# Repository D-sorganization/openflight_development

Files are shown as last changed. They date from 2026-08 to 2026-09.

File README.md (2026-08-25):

<p align="center">

  DIY Golf Launch Monitor using the OPS243-A Doppler Radar.
</p>

<p align="center">
  <a href="https://discord.gg/w8hhG4WVMN">
    
  </a>
  <a href="https://buymeacoffee.com/colemangolfs">
    
  </a>
</p>

> [!WARNING]
> **This project is in active development.** Features may be incomplete, unstable, or change without notice. Contributions and bug reports are welcome!

## Overview

OpenFlight is an open-source golf launch monitor built around the OPS243-A
Doppler radar, with an optional TI IWR6843 angle radar.

### What It Measures

- **Ball Speed**: 15-200 mph range with ±0.5% accuracy (OPS243-A)
- **Club Speed**: Detected from pre-impact readings (OPS243-A)
- **Smash Factor**: Ball speed / club speed ratio
- **Launch Angle**: Measured by the IWR6843; estimated when no trusted radar angle is available
- **Club Path**: Experimental pre-impact estimate from the IWR6843
- **Spin Rate**: Experimental candidate from rolling-buffer I/Q; not used for carry by default
- **Carry Distance**: Ballistic model with explicit fallbacks for missing measurements

### Hardware at a Glance

| Component | What it does | ~Cost |
|---|---|---|
| OPS243-A Radar | Ball speed, club speed, experimental spin | $249 |
| Raspberry Pi 5 | Runs everything | $130 |
| 7" Touchscreen | Shows shot data | $46 |
| SparkFun SEN-14262 | Impact sound trigger for shot capture | $18 |
| Power supply + accessories | | $27 |
| **Subtotal, no angle radar** | | **~$400** |
| TI IWR6843LEVM + cable | Launch angle, experimental club path | $156 |
| **Total with angle radar** | | **~$556** |
| K-LD7 (×2) + FTDI adapters | Launch angle + club path (**deprecated**) | $140 |

Without an angle radar you still get ball speed, club speed, smash factor,
experimental spin, and estimated carry. The angle radar adds measured launch
angle and experimental club path.

> **⚠️ The K-LD7 angle radars are deprecated.** The supported angle radar is now the **TI IWR6843**. Don't buy K-LD7s for a new build; their software support remains for existing builds only. See the [full parts list](docs/PARTS.md) for details and links.

> **The IWR6843 needs custom firmware** — the stock TI demo doesn't expose the raw radar cube OpenFlight needs. A validated prebuilt image ships in `firmware/releases/`, so flashing it doesn't require the TI toolchain. See the [IWR6843 Operator Guide](docs/iwr6843/README.md).

## Getting Started

### 1. Get the parts

See the **[Parts List](docs/PARTS.md)** for everything you need with purchase links.

### 2. Wire it up

Follow the **[Sound Trigger Wiring Guide](docs/sound-trigger-wiring.md)** to connect the SEN-14262 to the OPS243-A. The (deprecated) K-LD7 modules connect via USB — no wiring needed.

**Adding the IWR6843 angle radar?** The Pi cannot power both radars over USB, so
the OPS243 moves to the Pi's GPIO UART header while the TI board takes the USB
port. Do it in this order, validating each step before the next — doing both at
once makes any failure ambiguous:

1. **[Move the OPS243 from USB to the Pi GPIO UART](docs/ops243-uart-migration.md)** — rewire and confirm the OPS still triggers on its own.
2. **[IWR6843 Operator Guide](docs/iwr6843/README.md)** — wire, flash the firmware, mount, aim, and measure geometry.

If your OPS243-A has **WiFi**, you cannot use the GPIO UART — its WiFi module
already drives the radar's UART receive line. Use a separately powered USB hub
instead; see the operator guide's Option B.

### 3. Set up the Pi

Flash Raspberry Pi OS (64-bit), plug in the radars, then run the interactive setup:

```bash
git clone https://github.com/jewbetcha/openflight.git
cd openflight
./scripts/setup/setup.sh
```

The script installs everything and walks you through the one-time hardware
configuration (radar flash setup, legacy K-LD7 device naming, auto-start, and
optional cloud sync) with prompts. It's safe to re-run any time.
See the **[Raspberry Pi Setup Guide](docs/raspberry-pi-setup.md)** for
details and troubleshooting.

### 4. Hit balls

```bash
# Default: rolling buffer mode with sound trigger
scripts/start-kiosk.sh

# With the IWR6843 angle radar (OPS243 on the Pi GPIO UART).
# Geometry values are examples — measure your own; see the operator guide.
scripts/start-kiosk.sh --iwr6843 \
  --ops-port /dev/ttyAMA0 \
  --iwr6843-tee-m 1.372 --iwr6843-net-m 4.064 \
  --iwr6843-tilt-deg 5.5 --iwr6843-radar-height-m 0.229 \
  --iwr6843-ball-height-m 0.021

# With legacy K-LD7 hardware (measure the mount tilt first)
scripts/start-kiosk.sh --kld7 --kld7-mount-tilt <measured-degrees>

# Swing speed training (air swings / speed sticks, no sound trigger)
scripts/start-kiosk.sh --swing-speed

# Development mode (no hardware)
scripts/start-kiosk.sh --mock

# With Geekworm X1202/X1206 battery monitoring
scripts/start-kiosk.sh --battery geekworm
```

The IWR6843 example values are not universal. Measure the geometry from the
antenna center and follow the [operator guide](docs/iwr6843/README.md#measure-the-geometry);
wrong values bias the result instead of producing an obvious startup error.

Then open http://localhost:8080 or use the touchscreen.

### 5. Sync to the cloud (optional)

OpenFlight can push your sessions to the **FlightWeb** cloud so you can review
shots from any device. It's opt-in, and **raw radar data never leaves your
Pi** — only shot results and session metadata are uploaded (verify with
`openflight-cloud push --dry-run`).

`setup.sh` offers to enable this and link your Pi. To do it by hand:

```bash
openflight-cloud link       # pair this Pi (enter a short code in your browser)
openflight-cloud status     # linked? queued? parked?
```

Once linked, sessions sync automatically (on session end and via a ~10-minute
timer that heals wifi outages). See the **[Cloud Sync Guide](docs/cloud-sync.md)**
for details.

### TV Display Mode

OpenFlight also serves a fullscreen-friendly browser display for tablets, TV browsers, or a Chrome tab cast to Chromecast.

1. Start OpenFlight as usual with `scripts/start-kiosk.sh`.
2. Find the OpenFlight host on your LAN — its hostname (see below) or its IP address.
3. Open `http://<openflight-host>:8080/display` from another laptop, tablet, or TV browser.
4. For Chromecast, open the display page in Chrome and use Chrome's built-in **Cast** feature to cast the tab.

> **Prefer the hostname over the IP.** Raspberry Pi OS broadcasts its hostname over
> mDNS (Avahi), so `http://openflight.local:8080/display` keeps working even when the
> Pi's DHCP lease expires and it comes back on a different address — a bookmarked IP
> breaks unless you reserved it on your router. Set the name in Raspberry Pi Imager's
> **Hostname** field when you flash the card; the default is `raspberrypi`, i.e.
> `raspberrypi.local`. The viewing device has to support mDNS — macOS, iOS, Windows 10+
> and most Linux desktops do, but some smart-TV browsers don't, so use the IP there.

This is browser/tab casting only. OpenFlight does not include native Cast SDK support yet.

### Swing Speed Training

For air swings and speed-stick training, OpenFlight can use the OPS243-A fast
speed stream directly instead of waiting for impact audio. Start it with
`scripts/start-kiosk.sh --swing-speed`; the server emits `swing_speed` events
with peak club speed, rep duration, reading count, and session stats. See the
**[Swing Speed Training Guide](docs/swing-speed-training.md)** for setup and
tuning options.

## How It Works

### System Architecture

```
SEN-14262 ── trigger ──► OPS243-A ── I/Q ──► RollingBufferMonitor
                                                   │
IWR6843 (optional) ── angle + club path ───────────┤
                                                   ▼
                                           Flask + WebSocket ──► React UI
```

1. **Sound trigger fires** — SEN-14262 detects club impact, triggers OPS243-A HOST_INT
2. **OPS243-A dumps buffer** — I/Q data is analyzed for ball speed, club speed, and an experimental spin candidate
3. **IWR6843 correlates** — The optional angle radar uses the same impact edge for launch angle and experimental club path
4. **Carry computed** — The ballistic model uses trusted measurements and fills missing inputs with documented fallbacks
5. **UI updates** — Shot data emitted via WebSocket to the React frontend

### Doppler Radar Basics

The OPS243-A transmits a 24 GHz signal. When it bounces off a moving object (the golf ball), the frequency shifts proportionally to the object's speed — this is the Doppler effect. At 24.125 GHz, each 1 mph of speed creates a ~71.7 Hz Doppler shift.

### Positioning

Place the OPS243-A **3-5 feet behind the tee**, pointing down the target line:

```
                Ball Flight Direction
                ======================>

[Tee]  ←--- 3-5 ft ---→  [OPS243-A]
```

The IWR6843 has stricter mounting and measurement requirements; use the
[operator guide](docs/iwr6843/README.md#mount-and-aim-the-radar) rather than assuming it
shares the OPS243 position.

## Configuration

### Radar Settings for Golf

| Setting | Value | Why |
| --- | --- | --- |
| Mode | Rolling buffer | Raw I/Q capture for precise speeds and experimental spin |
| Sample Rate | 30 ksps | Supports up to ~208 mph ball speed |
| Capture | 4096 I/Q samples | ~136 ms around impact |
| Trigger | Sound (SEN-14262) | ~10 µs hardware latency via HOST_INT |
| Min Ball Speed | 15 mph | Filter club waggle and slow movements (35 mph for non-default SpeedTriggeredCapture) |
| DC Mask | ~15 mph exclusion zone | Reject body movement and environmental noise |

These are applied automatically — the one-time flash configuration is handled
by the setup script.

### Python API

```python
from openflight.rolling_buffer import RollingBufferMonitor

monitor = RollingBufferMonitor()  # auto-detects the OPS243-A
monitor.connect()
monitor.start()

print("Swing when ready...")
shot = monitor.wait_for_shot(timeout=60)
if shot:
    print(f"Ball Speed: {shot.ball_speed_mph:.1f} mph")
    print(f"Est. Carry: {shot.estimated_carry_yards:.0f} yards")

monitor.stop()
monitor.disconnect()
```

## Limitations

- **Cosine error**: If ball doesn't travel directly toward/away from radar, measured speed will be slightly lower than actual
- **Spin detection**: The live multitaper value is experimental and is not used for carry by default. Short indoor flight windows and multipath make individual readings unreliable; see [Rolling Buffer and Spin Detection](docs/rolling_buffer_spin_detection.md).
- **K-LD7 speed aliasing** (deprecated hardware): The K-LD7 max speed is 62 mph, so it's used only for angle/distance, not speed

## Hardware Diagnostic

To verify the OPS243, sound trigger, and legacy K-LD7 path:

```bash
uv run python scripts/hardware-test/diagnose.py
```

The diagnostic checks the OPS243 transport, rolling-buffer persistence,
software and hardware triggers, and any connected K-LD7 radars. IWR6843 builds
use the [operator guide's first-capture checks](docs/iwr6843/README.md#verify-the-first-capture).

Missing optional hardware (like the horizontal K-LD7) is reported as a skip rather than a failure. Pass `--require-all` to fail on skips, or `--no-interactive` to skip the sound-trigger prompt in unattended runs.

## Project Structure

```
openflight/
├── src/openflight/
│   ├── ops243.py              # OPS243-A radar driver
│   ├── launch_monitor.py      # Shot detection & club/ball separation
│   ├── ballistics.py          # Ballistic trajectory & carry model
│   ├── server.py              # Flask server and shot orchestration
│   ├── session_logger.py      # JSONL session logging
│   ├── rolling_buffer/        # OPS capture and signal processing
│   ├── iwr6843/               # Current angle radar
│   ├── kld7/                  # Legacy angle radar
│   ├── sim/                   # Simulator connector framework
│   └── cloud/                 # FlightWeb uploader
├── ui/                        # React frontend
├── scripts/                   # Utility & setup scripts
├── docs/                      # Documentation
└── pyproject.toml
```

## Community

Join the **[OpenFlight Discord](https://discord.gg/w8hhG4WVMN)** to ask build
questions, share results, and follow development.

## Contributing

Contributions welcome! See [CONTRIBUTING.md](CONTRIBUTING.md) for guidelines.

Areas of interest:

- **Better spin detection**: A dechirped Doppler-sideband estimator is in development (`scripts/analysis/replay_spin_dechirp.py`) — help validating it against launch-monitor truth data is especially welcome
- **Mobile app**: Bluetooth connection to phone

### Running Tests

```bash
uv run pytest tests/ -v
```

## Documentation

- **[Parts List](docs/PARTS.md)** — What to buy
- **[Sound Trigger Wiring](docs/sound-trigger-wiring.md)** — How to wire the sound trigger
- **[Raspberry Pi Setup](docs/raspberry-pi-setup.md)** — Full setup guide
- **[Battery Monitoring](docs/battery/README.md)** — Provider architecture, UI states, and shared Pi support
- **[Geekworm X1202/X1206 Operator Guide](docs/battery/geekworm.md)** — Batteries, Pi setup, native telemetry, and warnings
- **[IWR6843 Operator Guide](docs/iwr6843/README.md)** — Wire, flash, mount, aim, and calibrate the angle radar
- **[LIS3DH Inclinometer Setup](docs/inclinometer/README.md)**: Add enclosure-level compensation to IWR6843 tilt
- **[OPS243 USB → GPIO UART Migration](docs/ops243-uart-migration.md)** — Required before adding the IWR6843
- **[IWR6843 Firmware Developer Guide](firmware/README.md)** — Build the firmware from source (not needed to flash the prebuilt image)
- **[Simulator Connectors](docs/simulator/README.md)** — Stream shots to GSPro, OpenGolfSim, and others
- **[Cloud Sync](docs/cloud-sync.md)** — Push filtered sessions to FlightWeb
- **[Rolling Buffer & Spin Detection](docs/rolling_buffer_spin_detection.md)** — Production capture and experimental spin details
- **[Dechirped-Sideband Spin Replay](docs/spin-dechirp-replay.md)** — Next-gen spin estimator test bench
- **[Camera and YOLO Experiments](docs/yolo-performance-tuning.md)** — Optional, non-production vision work
- **[Legacy K-LD7 Setup](docs/kld7.md)** — Existing K-LD7 builds only
- **[K-LD7 Ball Detection Theory](docs/kld7-ball-detection-theory.md)** — How angle detection works (deprecated hardware)
- **[K-LD7 Session Review](docs/kld7-session-review.md)** — Offline review workflow for session JSONL files (deprecated hardware)
- **[Observability & Log Shipping](docs/observability.md)** — Ship logs to Grafana Cloud
- **[Contributing Guide](CONTRIBUTING.md)** — How to contribute
- **[Changelog](docs/CHANGELOG.md)** — Version history

## License

GNU Affero General Public License v3.0 or later (AGPL-3.0-or-later) - see LICENSE file.

## Acknowledgments

- [OmniPreSense](https://omnipresense.com/) for the OPS243-A radar and documentation
- The golf hacker community for inspiration

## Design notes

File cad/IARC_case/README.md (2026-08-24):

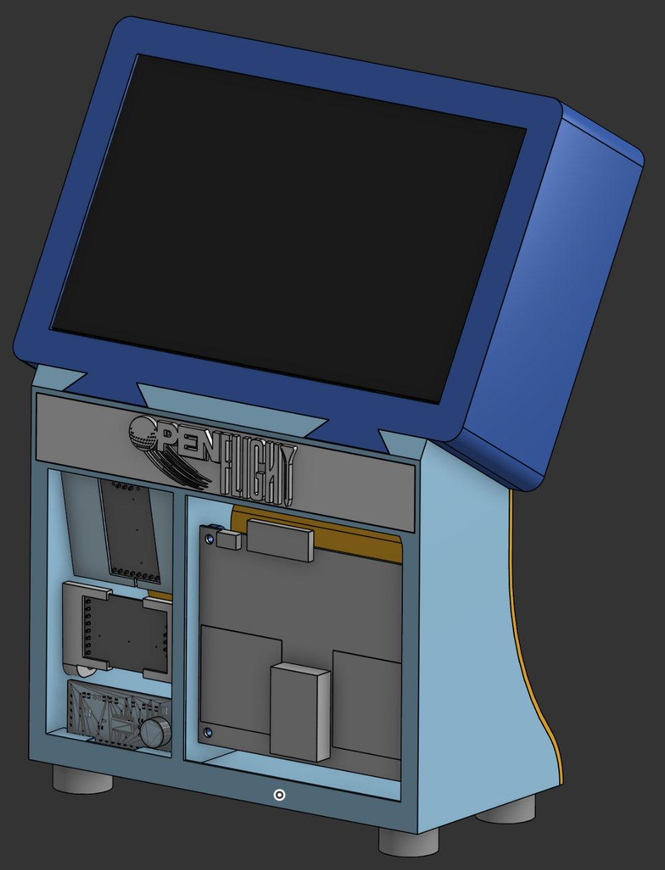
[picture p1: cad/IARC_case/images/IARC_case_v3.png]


> **⚠️ Note:** The KLD7 mounts in this case are for the deprecated K-LD7 angle radars — OpenFlight has moved to a more capable radar chip. Skip the KLD7 mount steps for a new build.

- M5 Bolts needed: 10
- M2.5 Bolts needed: 12

Instructions for OpenFlight IARC v3 Case Build
  
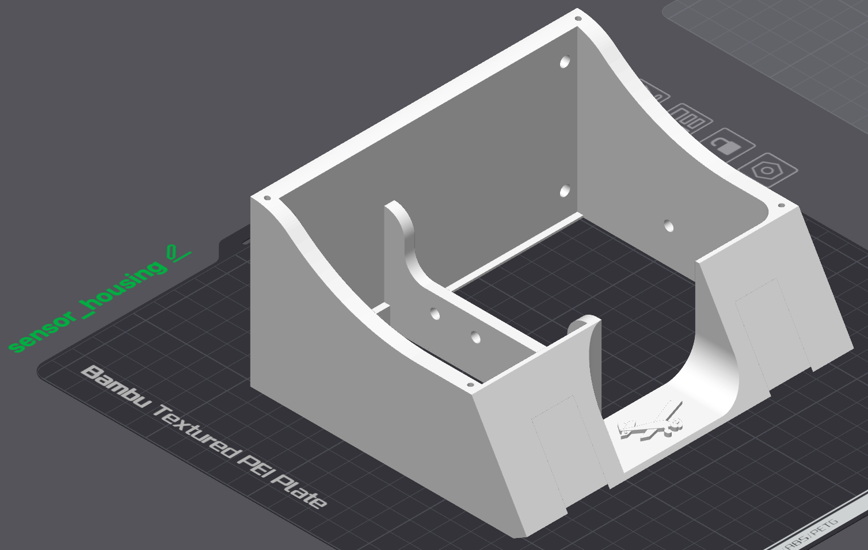
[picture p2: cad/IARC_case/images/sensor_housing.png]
1. Print out `sensor_housing.stl` 
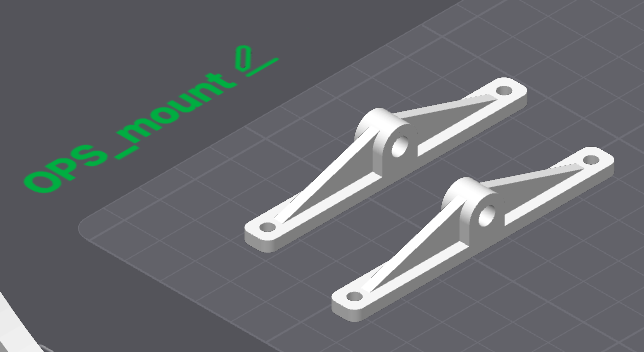
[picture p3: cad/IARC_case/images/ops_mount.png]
2. Print out (2x) `OPS_mount.stl` 
3. Secure the OPS sensor to each `OPS_mount.stl` part with screws (I don't know which ones)
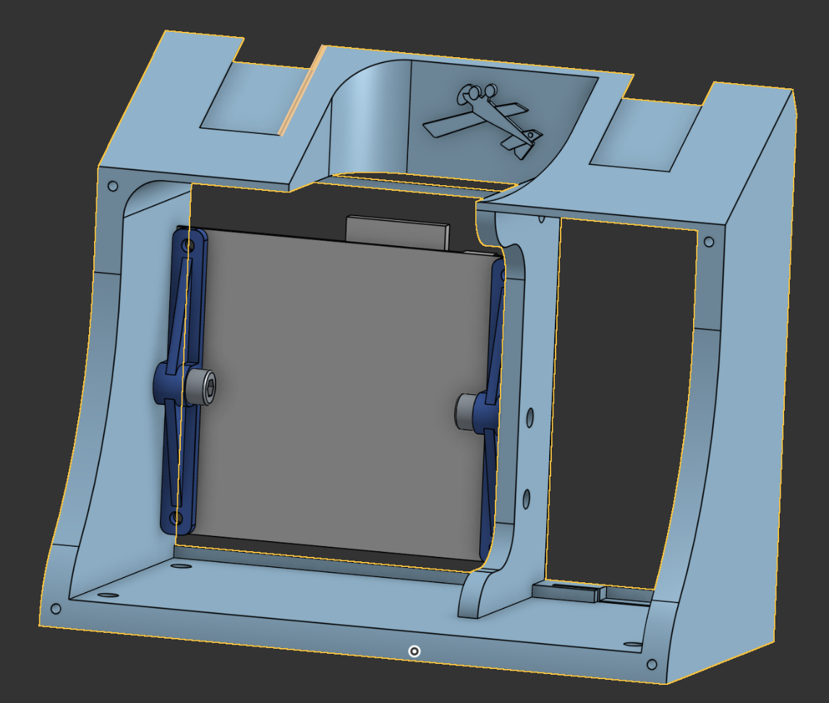
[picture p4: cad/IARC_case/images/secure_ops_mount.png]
4. Secure the `OPS_mount.stl` parts to the `sensor_housing.stl` part with (2x) M5 bolt 
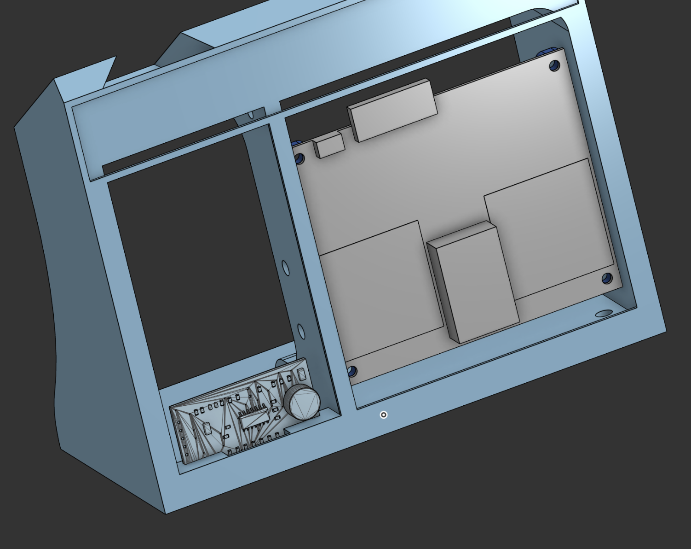
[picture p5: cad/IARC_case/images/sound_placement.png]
5. Fit the sound sensor into the little slot on the left side of the `sensor_housing.stl` part. 
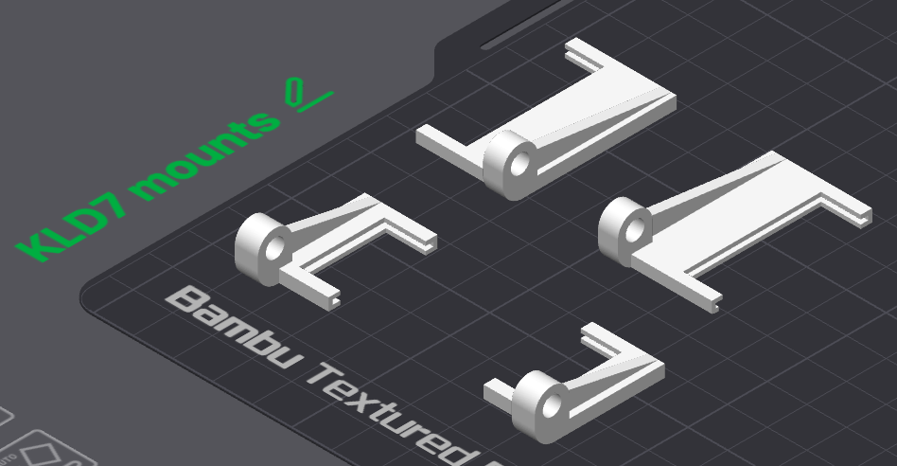
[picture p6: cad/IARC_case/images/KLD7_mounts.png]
6. Print out (1x) `KLD7_h_mount_L_v2.stl` and (1x) `KLD7_h_mount_R_v2.stl` 
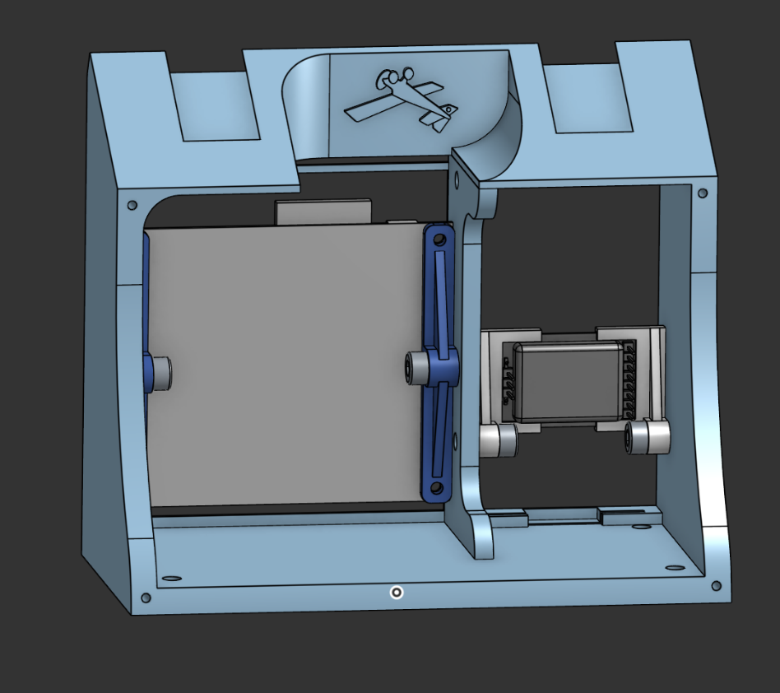
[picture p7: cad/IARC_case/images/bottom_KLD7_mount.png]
7. Slot a KLD7 sensor between the mount parts, and secure them to the `sensor_housing.stl` part with (2x) M5 bolt 
8. Print out (1x) `KLD7_v_mount_L_v2.stl` and (1x) `KLD7_v_mount_R_v2.stl` 
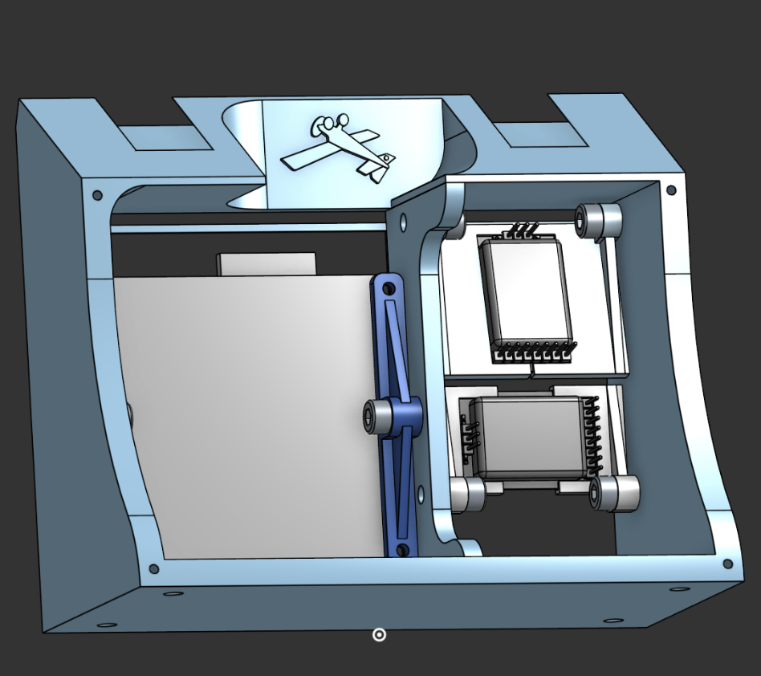
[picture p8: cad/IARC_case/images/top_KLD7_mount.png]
6. Slot a KLD7 sensor between the mount parts, and secure them to the `sensor_housing.stl` part with (2x) M5 bolt 
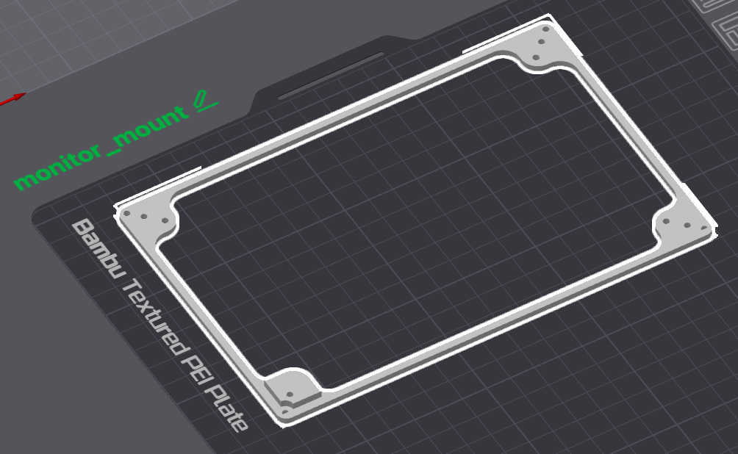
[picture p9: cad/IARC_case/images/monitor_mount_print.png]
7. Print out the `monitor_mount.stl` part. 
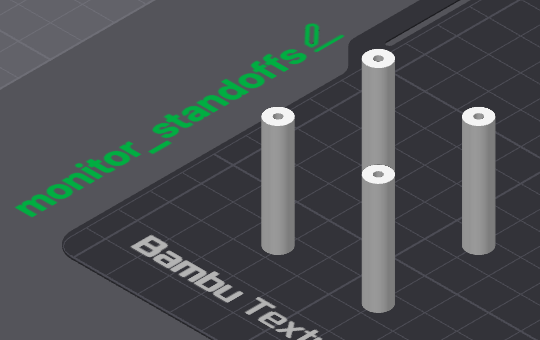
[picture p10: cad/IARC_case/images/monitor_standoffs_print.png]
8. Print out (4x) `monitor_standoffs.stl`'s. 
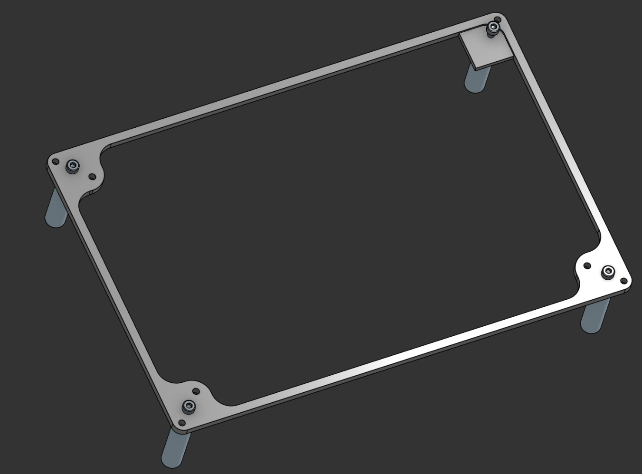
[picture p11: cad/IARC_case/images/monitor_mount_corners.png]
9. Secure each `monitor_standoff.stl` part to the corners of the `monitor_mount.stl` part with (1x) M2.5 bolt. 
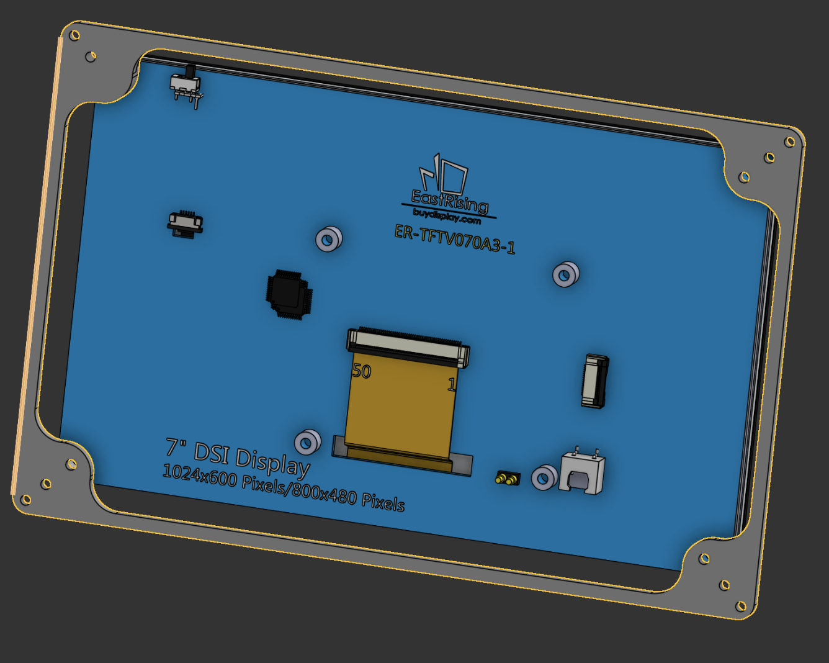
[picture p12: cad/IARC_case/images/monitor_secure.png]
10. Secure the monitor to the `monitor_mount.stl` part. 
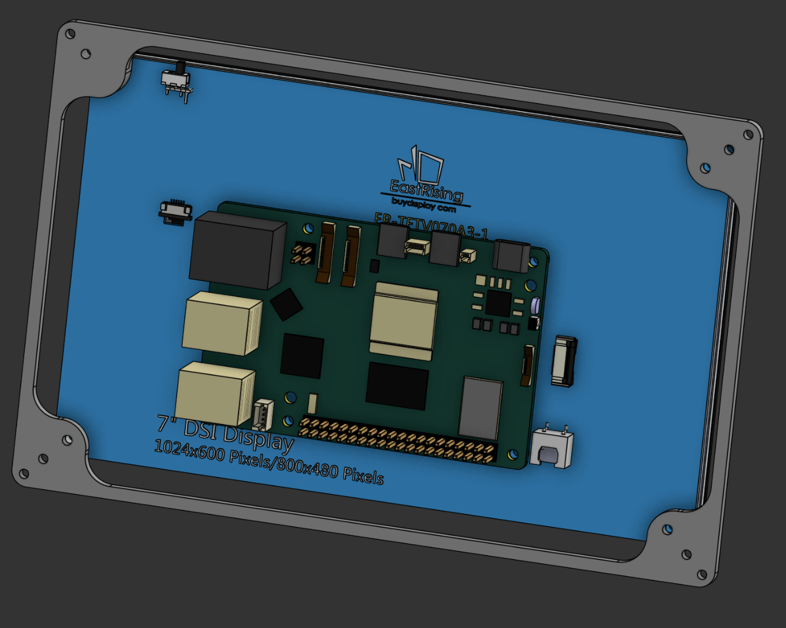
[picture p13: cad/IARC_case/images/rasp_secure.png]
11. Secure the raspberry Pi to the monitor. 
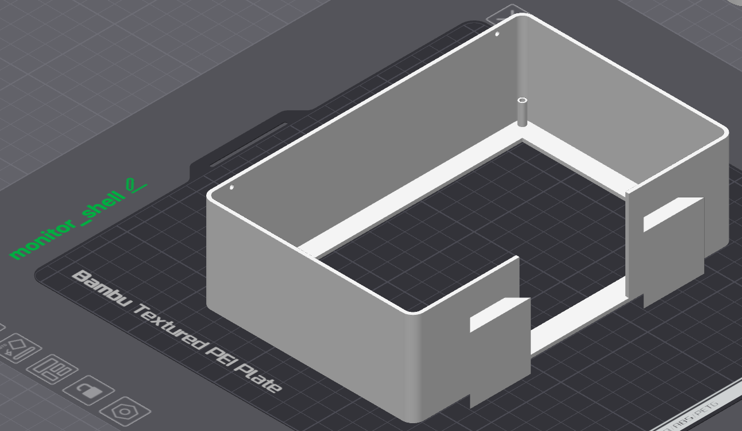
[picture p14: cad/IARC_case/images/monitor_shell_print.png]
12. Print out the `monitor_shell.stl` part. If you use the Raspberry Pi Touch Display 2 instead of the 7" HMTECH touchscreen, print `Touch_Display2_shell.stl` and `Touch_Display2_backplate.stl` instead. 
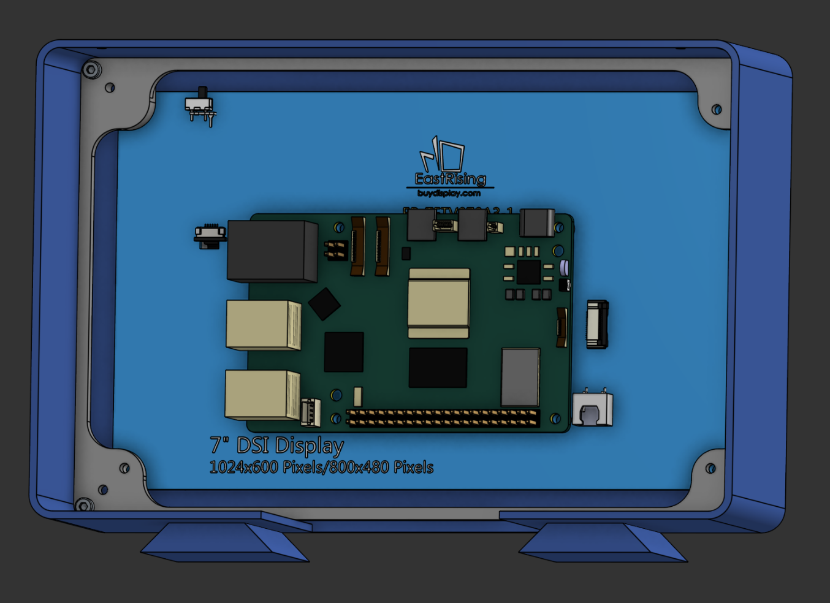
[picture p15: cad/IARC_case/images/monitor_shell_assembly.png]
13. Secure the monitor assembly inside the `monitor_shell.stl` part with (4x) M2.5 bolts at the corners. 
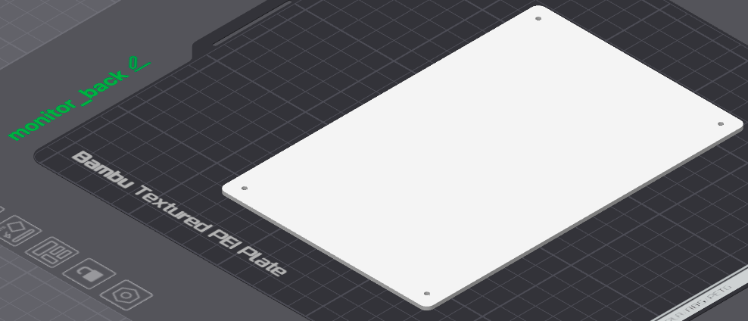
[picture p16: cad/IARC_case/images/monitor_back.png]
14. Print out the `monitor_back.stl` part. 
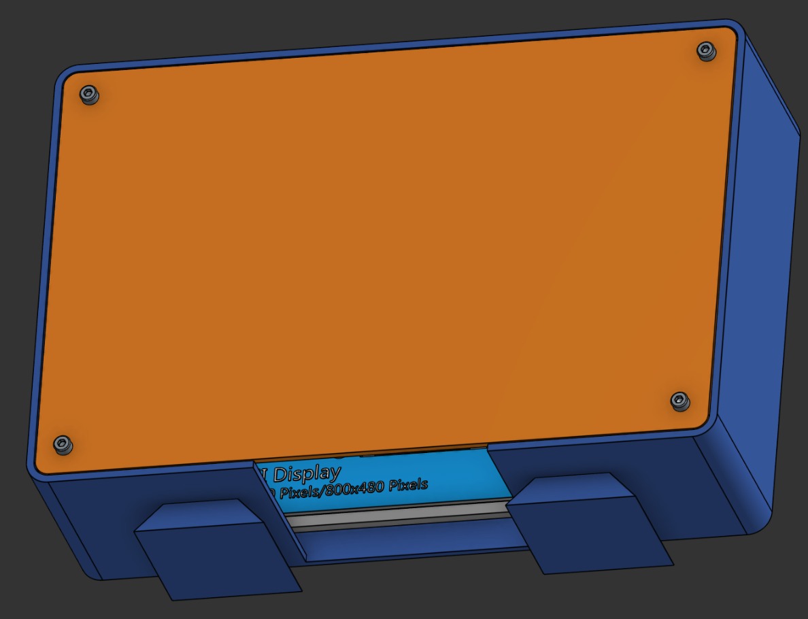
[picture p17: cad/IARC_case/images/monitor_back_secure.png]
15. Secure the `monitor_back.stl` part to the `monitor_standoffs.stl` parts with (4x) M2.5 bolts. 
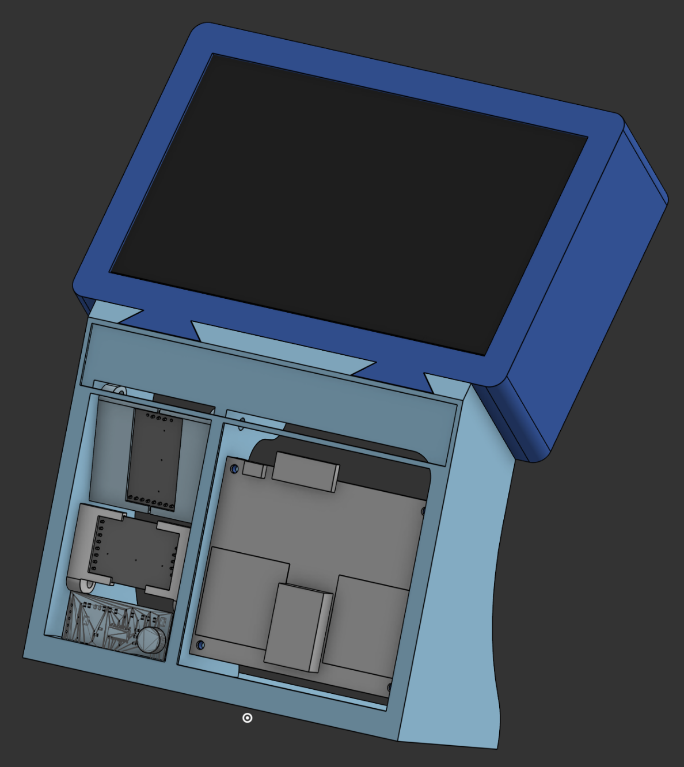
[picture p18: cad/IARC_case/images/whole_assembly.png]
16. Slide the whole assembly into the sensor housing assembly, using the dovetails to align everything together. 
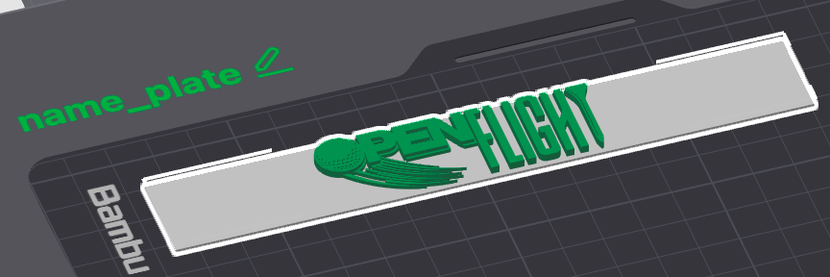
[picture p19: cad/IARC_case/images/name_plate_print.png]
17. Print out the `name_plate.stl` file. 
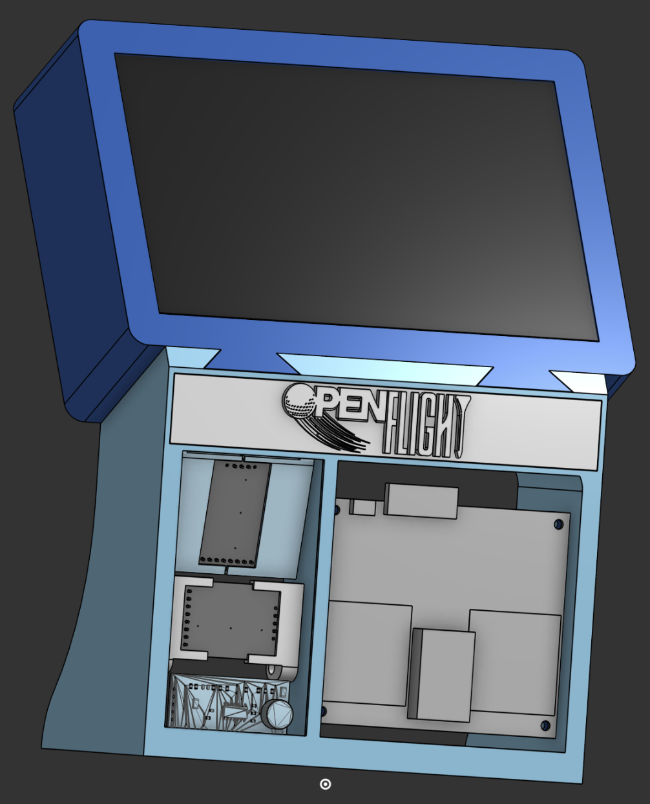
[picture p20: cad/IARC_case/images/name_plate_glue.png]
18. Secure the `name_plate.stl` file to the front of the whole assembly with glue. 
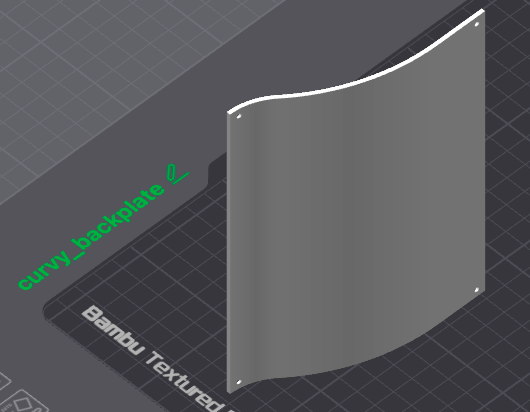
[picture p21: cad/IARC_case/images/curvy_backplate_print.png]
19. Print out the `curvy_backplate.stl` file. 
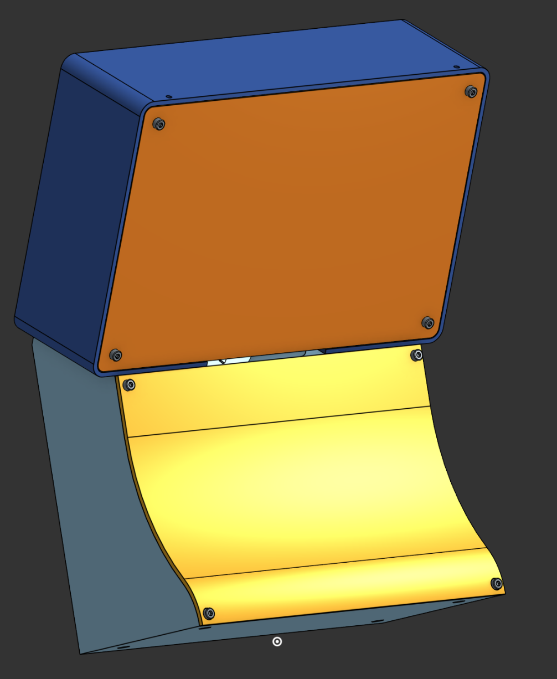
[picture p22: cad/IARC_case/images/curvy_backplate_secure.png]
20. Secure the `curvy_backplate.stl` file to the whole assembly with (4x) M2.5 bolts. 
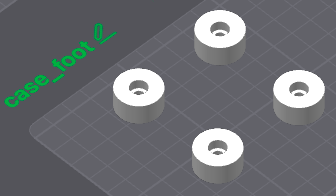
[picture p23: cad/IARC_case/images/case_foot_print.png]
21. Print out (4x) `case_foot.stl` parts. 
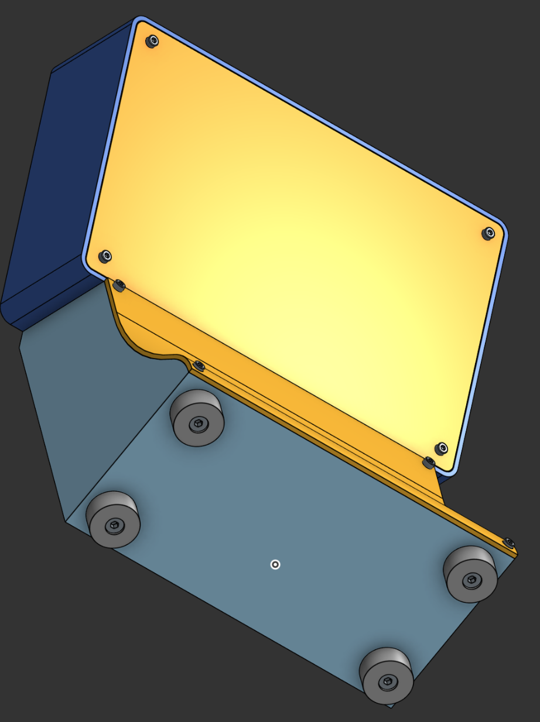
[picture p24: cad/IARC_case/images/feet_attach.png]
22. Secure each foot to the bottom of the whole assembly with (4x) M5 Bolts. 

And that’s how you put together the 3d printed parts!

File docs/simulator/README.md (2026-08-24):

# Simulator Connectors

OpenFlight can stream each shot into golf simulators in real time. Connectors
are **optional** and **additive**: you can run zero, one, or several at once
(e.g. GSPro and OpenGolfSim simultaneously). The shot-detection pipeline is
never modified — connectors are listeners that hang off the shot it already
produces.

Supported simulators:

- [GSPro](gspro.md) (OpenConnectV1)
- [OpenGolfSim](opengolfsim.md)

This document explains how the connector layer works and how to add a new
simulator. For setting up a specific simulator, see its page above.

## Quick start

1. Copy the example config and enable the simulator(s) you use:
   ```bash
   cp config/sim.example.json config/sim.json
   ```
   ```jsonc
   {
     "connectors": [
       // OpenGolfSim via its Developer API on 3111 (speaks OpenConnect V1).
       // Club sync needs the scripts/setup/opengolfsim patch; see opengolfsim.md.
       { "type": "opengolfsim", "enabled": true, "host": "127.0.0.1", "port": 3111 },
       // GSPro
       { "type": "gspro", "enabled": false, "host": "192.168.1.50", "port": 921 }
     ]
   }
   ```
   A connector's `type` is the *product*. Both ride the shared OpenConnect V1
   codec — they differ only in name and default port (GSPro 921, OpenGolfSim's
   Developer API 3111).
2. **Enable the feature at launch with `--sim`** (off by default). Connectors
   marked `enabled` in the file then come up:
   ```bash
   scripts/start-kiosk.sh --sim
   ```
   Without `--sim`, no connectors run regardless of the file. (Once the feature
   is broadly stable it may default on.)

The header shows a status pill per connector (green = connected, amber =
connecting/reconnecting, red = error, gray = disabled). In **debug mode**, a
per-shot "Sent to <sim>" panel shows every field that was sent with an **M**
(measured) or **E** (estimated) badge.

## How it works

```
OPS243 + optional angle radar  ──►  shot pipeline  ──►  on_shot_detected()
                                              │  (UI emit unchanged)
                                              ▼
                                       resolve_shot(shot)            ← sim/resolver.py
                                              │  ResolvedShot + provenance
                                              ▼
                              ┌───────────────┼───────────────┐
                              ▼               ▼               ▼
                  OpenConnect V1 codec (gspro/codec.py)    (future)   ← per-sim codec
                              │               │
                        TcpSimClient    TcpSimClient                   ← sim/transport.py
                              ▼               ▼
                          GSPro :921     OpenGolfSim :3111
```

The design separates the parts that are **shared across all simulators** from
the parts that are **specific to one protocol**:

| Layer | File | Shared? |
|---|---|---|
| TCP lifecycle, reconnect/backoff, JSON framing, optional heartbeat | `sim/transport.py` | shared |
| Shot → resolved fields + measured/estimated provenance (fallback table) | `sim/resolver.py` | shared |
| Connection state, player state, inbound event types, resolved shot | `sim/types.py` | shared |
| Connector = codec + transport, and the codec registry | `sim/codec.py` | shared |
| Config (`config/sim.json` + CLI merge) | `sim/config.py` | shared |
| **Wire format**: serialize a shot, parse inbound messages, heartbeat | `gspro/codec.py`, `opengolfsim/codec.py` | **per-sim** |

The key idea: two simulators differ only in their **wire format** and their
**inbound message shapes**. Everything else — connecting, reconnecting,
filling in missing fields, tracking provenance, fanning out to multiple
targets — is written once and reused.

### The resolver and provenance

`resolve_shot()` turns a `Shot` into a `ResolvedShot` with every
simulator-relevant field populated, applying a fallback when a measurement is
missing (e.g. no measured spin → a per-club model value). Each field is tagged
`measured` or `estimated`. This logic lives in exactly one place, so every
connector is honest about what came from hardware versus a model, and the UI
renders identical badges for any simulator.

A shot is **only dropped** when ball speed is missing — every other field has
a model fallback.

### The codec contract

A codec is a small class implementing the `Codec` protocol
(`sim/transport.py`):

```python
class Codec(Protocol):
    name: str

    def build_shot(self, resolved: ResolvedShot) -> bytes: ...  # serialize a shot
    def parse_inbound(self, frame: bytes) -> list[InboundEvent]: ...  # decode sim → us
    def heartbeat_bytes(self) -> Optional[bytes]: ...  # None = no keepalive
    def on_connect_bytes(self) -> Optional[bytes]: ...  # e.g. a hello frame
    def fields_for_target(self) -> list[str]: ...  # which fields it sends
```

Inbound messages are normalized into protocol-neutral events
(`PlayerUpdate`, `ShotAck`, `SimError`) so the server handles club changes and
errors the same way regardless of simulator.

> **Club selection is one-way: simulator → OpenFlight.** Both GSPro and
> OpenGolfSim treat the sim as the source of truth for the current club and
> push it to the launch monitor; neither protocol accepts a club change *from*
> the launch monitor. OpenFlight applies the sim's club to its shot tagging and
> carry/spin model. (If a future sim's API supports setting the club from the
> device, the codec is where you'd add an outbound `build_club_change`-style
> method — no other layer changes.)

## Adding a new simulator

1. **Create a codec.** Add `src/openflight/<sim>/codec.py` implementing the
   `Codec` protocol. Map `ResolvedShot` fields to the simulator's wire format
   in `build_shot`, and translate inbound messages to `PlayerUpdate` /
   `ShotAck` / `SimError` in `parse_inbound`. Return `None` from
   `heartbeat_bytes()` if the protocol has no keepalive.
2. **Register it.** Add the type to `_codec_for()` and to `_DEFAULTS` /
   `KNOWN_TYPES` in `sim/config.py` (default host/port/units).
3. **No new CLI flag needed.** The single `--sim` gate enables all connectors
   from `config/sim.json`; just add your connector there.
4. **UI display names.** Add the target → display-name entry in
   `ui/src/components/SimStatus.tsx` and `SimShotBadges.tsx`.
5. **Tests.** Add a codec round-trip test (serialize + parse inbound) and a
   club-mapping test. The shared transport/resolver are already covered.
6. **Docs.** Add `docs/simulator/<sim>.md` and link it from this page.

You do **not** touch the transport, the resolver, the server fan-out, or the
config loader — that's the point of the abstraction.

## Session logging

Each connector logs three entry types to the session JSONL:

- `sim_send` — a shot forwarded to a simulator (target, shot number, per-field
  values + provenance)
- `sim_status` — a connection-state change (connected, reconnecting, error)
- `sim_player` — a player/club update pushed back by the simulator

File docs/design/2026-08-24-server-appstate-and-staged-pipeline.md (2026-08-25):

# Upstream Design Proposal: `server.py` AppState, Staged Shot Pipeline, and Camera Retirement

**Author:** Dieter Olson  
**Date:** 2026-08-24  
**Issue:** [#20](https://github.com/D-sorganization/openflight_development/issues/20)  
**Status:** Proposed / Implemented in Slice 1  

---

## 1. Executive Summary

As OpenFlight has expanded to support TI IWR6843 mmWave radar, simulator connectors (GSPro, OpenGolfSim, E6), LIS3DH inclinometer compensation, calculated spin models, and swing-speed training modes, `src/openflight/server.py` has grown into a 4,200+ line god-module holding 29 `global` declarations, runtime mutation of configuration constants, and a ~500-line monolithic `on_shot_detected` handler.

Past experience across large refactors (e.g. PRs #120–#127) demonstrates that massive, single-shot rewrites stall in review, whereas well-specified incremental slices with automated tests merge quickly and safely.

This proposal outlines a phased architectural refactoring strategy:
1. **`AppState` Dataclass:** Encapsulate scattered module globals, hardware controllers, session state, and configuration dictionaries into a clean, typed container instantiated at startup.
2. **Staged Shot Processing Pipeline:** Decompose the monolithic `on_shot_detected` handler into distinct, testable, and isolated stages (ingestion, angle extraction, ballistics, logging, and downstream fan-out).
3. **K-LD7 Orientation Extraction (First Slice):** Extract `_process_kld7_orientation()` to deduplicate ~90 lines of duplicated vertical/horizontal radar buffer analysis and validation logic.
4. **Dead Camera Stack Retirement:** Formally deprecate and retire ~2,030 lines of unreachable computer vision code (`camera_tracker.py` and `src/openflight/camera/`) whose dependencies (`opencv-python`, `supervision`, `inference-sdk`) were removed from the base package.

---

## 2. Current Architecture & Pain Points

### 2.1 Global State Accumulation
`server.py` currently relies on 29 `global` statements across startup routines, socket events, and shot callbacks:
- Hardware handles: `monitor`, `kld7_vertical`, `kld7_horizontal`, `iwr6843_runtime`, `inclinometer_service`, `power_monitor`, `camera`, `camera_tracker`.
- Session state: `current_player_name`, `sim_player_state`, `sim_connectors`.
- Operational flags: `mock_mode`, `debug_mode`, `mock_swing_speed_mode`, `ballistics_enabled`, `battery_provider`, `ball_speed_correction_enabled`, `calculated_spin_enabled`, `_VERTICAL_RADAR_GATE_BYPASS`.
- Configuration dictionaries: `active_kld7_radc_tuning`, `iwr6843_runtime_config`, `inclinometer_runtime_config`.

**Consequences:**
- Testing requires extensive `monkeypatch.setattr(server_module, ...)` calls.
- Concurrency and lifecycle cleanup are fragile.
- Runtime state cannot be cloned or instantiated independently for headless simulations or multi-rig testing.

### 2.2 Duplication in `on_shot_detected`
The primary shot callback executes synchronously on the capture thread. Prior to this refactor, vertical (launch angle) and horizontal (club path) K-LD7 processing were duplicated line-for-line across ~200 lines:
- Ring buffer snapshotting and underfill warnings.
- RADC raw payload verification.
- Post-shot frame span validation.
- Radar angle candidate extraction and validation gating.
- Club angle extraction (angle of attack vs. club path).
- JSONL buffer session logging.
- Tracker reset.

### 2.3 Dead Vision Stack
OpenFlight previously explored Pi Camera v2 / HQ camera tracking for launch angle. However:
- Dependencies (`opencv-python`, `supervision`, `trackers@git`, `inference-sdk`) were commented out in `pyproject.toml` due to ARM64 wheel build instability and latency constraints on Raspberry Pi.
- TI IWR6843 60 GHz radar and OPS243-A Doppler radar provide superior accuracy and environmental robustness without optical lighting constraints.
- `camera_tracker.py` and `camera/` remain on disk and referenced in `server.py`, but all execution branches are unreachable on fresh installs.

---

## 3. Proposed Architecture

```
                                  ┌─────────────────────────────┐
                                  │          AppState           │
                                  │ ─────────────────────────── │
                                  │ • Hardware Adapters         │
                                  │ • Session & Player State    │
                                  │ • Config & Tuning Dicts     │
                                  │ • Operational Flags         │
                                  │ • Lifecycle & Concurrency   │
                                  └──────────────┬──────────────┘
                                                 │
                                                 ▼
┌─────────────────────────────────────────────────────────────────────────────────────────┐
│                                   Shot Processing Pipeline                              │
├───────────────────┬───────────────────┬───────────────────┬──────────────┬──────────────┤
│ 1. Ingestion      │ 2. Angle & Path   │ 3. Ballistics &   │ 4. Session   │ 5. Client &  │
│    & Geometry     │    Resolution     │    Trajectory     │    Logging   │    Sim Fanout│
├───────────────────┼───────────────────┼───────────────────┼──────────────┼──────────────┤
│ • Inclinometer    │ • IWR6843 LCMF-v1 │ • Cosine speed    │ • JSONL      │ • WebSocket  │
│   tilt snapshot   │ • K-LD7 vertical/ │   correction      │   logging    │   "shot" emit│
│ • Impact timing   │   horizontal      │ • Calculated spin │ • Diagnostic │ • Simulators │
│   correlation     │   processing      │ • RK4 simulation/ │   provenance │   (GSPro,    │
│                   │ • Estimator/table │   table carry     │ • Error traps│   OpenGolf)  │
│                   │   fallback        │                   │              │              │
└───────────────────┴───────────────────┴───────────────────┴──────────────┴──────────────┘
```

### 3.1 `AppState` Dataclass
`AppState` unifies runtime state into a structured, type-annotated dataclass:

```python
@dataclass
class AppState:
    """Encapsulates OpenFlight server runtime state, hardware adapters, and configuration."""

    # Hardware controllers & adapters
    monitor: Any = None
    power_monitor: Optional[PowerMonitor] = None
    battery_provider: Optional[str] = None
    kld7_vertical: Any = None
    kld7_horizontal: Any = None
    iwr6843_runtime: Any = None
    inclinometer_service: Any = None
    camera: Any = None
    camera_tracker: Any = None
    sim_connectors: List[Any] = field(default_factory=list)

    # Session & player state
    current_player_name: str = "Player 1"
    sim_player_state: SimPlayerState = field(
        default_factory=lambda: SimPlayerState(shot_counter=initial_shot_counter())
    )

    # Operational flags & runtime modes
    mock_mode: bool = False
    debug_mode: bool = False
    mock_swing_speed_mode: bool = False
    ballistics_enabled: bool = True
    ball_speed_correction_enabled: bool = True
    ball_speed_correction_distance_ft: float = 1.0
    ball_speed_correction_ball_above_radar_ft: float = 0.0
    radar_gate_bypass: bool = False
    calculated_spin_enabled: bool = False
    experimental_kld7_radc_tuning: bool = False
    experimental_kld7_raw_radc_logging: bool = False

    # Dynamic tuning / config dictionaries
    active_kld7_radc_tuning: dict = field(default_factory=lambda: dict(_DEFAULT_KLD7_RADC_TUNING))
    iwr6843_runtime_config: dict = field(default_factory=lambda: {"enabled": False})
    inclinometer_runtime_config: dict = field(default_factory=lambda: {"enabled": False})

    # Debug file logging
    debug_log_file: Any = None
    debug_log_path: Optional[Path] = None

    # Camera runtime state
    camera_enabled: bool = False
    camera_streaming: bool = False
    camera_thread: Optional[threading.Thread] = None
    camera_stop_event: Optional[threading.Event] = None
    ball_detected: bool = False
    ball_detection_confidence: float = 0.0
    latest_frame: Optional[bytes] = None

    # Lifecycle synchronization
    shutdown_cleanup_started: bool = False
```

### 3.2 Staged Shot Pipeline
`on_shot_detected` is decomposed into 5 clear stages:

1. **Stage 1: Geometric Ingestion & Snapshot**
   - Captures orientation from `inclinometer_service` before blocking I/Q operations.
   - Correlates radar impact timestamps.
2. **Stage 2: Launch Angle & Path Resolution**
   - Executes `_process_iwr6843_angle()` (TI 60 GHz radar).
   - Executes `_process_kld7_orientation()` for vertical (launch angle + AoA) and horizontal (club path) tracking.
   - Derives spin axis from horizontal launch and club path.
   - Falls back to `_ensure_user_facing_launch_angles()` when radar measurements are unavailable or rejected.
3. **Stage 3: Ballistic & Trajectory Simulation**
   - Applies radial-to-true speed cosine correction.
   - Evaluates calculated spin models if enabled.
   - Resolves launch conditions and simulates 3D trajectory via RK4 numerical ballistics, falling back to spin-adjusted tables.
4. **Stage 4: Session Logging & Telemetry**
   - Records shot records, raw I/Q captures, and RADC buffer diagnostics to `SessionLogger`.
5. **Stage 5: Client Broadcast & Simulator Fan-out**
   - Emits WebSocket payload to React frontend.
   - Dispatches shot events to active simulator connectors (GSPro / OpenGolfSim).

### 3.3 First Slice Implementation: `_process_kld7_orientation()`
Extracted helper function that unifies K-LD7 vertical and horizontal buffer processing:

```python
def _process_kld7_orientation(
    tracker,
    orientation: str,
    shot: Shot,
    shot_ts: float,
    session_log=None,
) -> None:
    """Process a single K-LD7 tracker (vertical or horizontal) for a detected shot."""
```

Benefits:
- Eliminates ~90 lines of duplicate code.
- Ensures identical diagnostic warning logs and buffer retention across both axes.
- Cleanly isolated for unit testing.

### 3.4 Camera Stack Retirement Plan

| Phase | Scope | Description |
|---|---|---|
| **Phase 1 (This PR)** | Foundation & Deduplication | Define `AppState`, extract `_process_kld7_orientation()`, document proposal, maintain backwards-compatible camera stubs. |
| **Phase 2** | Code Retirement | Move `camera_tracker.py` and `camera/` to `archive/vision/` or deprecate package. Remove unused CV2 dependencies. |
| **Phase 3** | Server Cleanup | Remove dead camera branches from `server.py` startup and `on_shot_detected`. Collapse camera status routes into a clean no-op / disabled stub. |
| **Phase 4** | Pipeline Decoupling | Refactor `on_shot_detected` into standalone stage functions accepting `(shot, app_state)`. |

---

## 4. Testing & Validation Strategy

1. **Automated Unit Tests:**
   - `TestAppState`: Verify default values, custom instantiation, and immutability/field consistency.
   - `TestProcessKld7Orientation`: Verify vertical angle acceptance, low-confidence rejection, club AoA sign inversion, horizontal club path assignment, and buffer session logging.
   - Existing 1,400+ unit and replay tests in `tests/` pass with zero regressions.
2. **Backwards Compatibility:**
   - All module-level attributes in `server.py` are preserved, ensuring existing test monkeypatching and public imports remain unbroken.

---

## 5. Conclusion

This proposal establishes a clean, reviewable roadmap for modernizing `server.py`. By landing `AppState` and `_process_kld7_orientation` first, we demonstrate immediate code reduction and maintainability gains without risking system stability.

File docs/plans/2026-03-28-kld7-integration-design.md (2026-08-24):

# K-LD7 Full Stack Integration — Design

**Date:** 2026-03-28
**Status:** Approved

## Goal

Integrate the RFbeam K-LD7 24 GHz FMCW radar into the openflight stack for real-time angle measurement. The K-LD7 handles angle (vertical or horizontal, depending on mount orientation) and distance. The OPS243-A handles speed and spin. Long-term, K-LD7 replaces the camera for angle measurement.

## Architecture

### K-LD7 Module (`src/openflight/kld7/`)

**`kld7_tracker.py`** — Main integration class, mirrors CameraTracker pattern:

```python
KLD7Tracker(
    port=None,  # Auto-detect FTDI serial
    range_m=5,  # Detection range
    speed_kmh=100,  # Hardware max; gives fastest frame rate (~34 fps)
    orientation="vertical",  # "vertical" or "horizontal" — which angle plane this module measures
)
```

- Background thread streams TDAT+PDAT continuously (no FFT — maximizes frame rate to ~34 fps)
- Ring buffer (`collections.deque`) holds last ~2 seconds of frames (~70 frames)
- `get_angle_for_shot() -> KLD7Angle | None`:
  - Searches ring buffer for highest-magnitude detection event
  - Prefers PDAT over TDAT (more reliable for transient targets — validated in testing)
  - Returns angle, distance, magnitude, confidence, frame count
  - Confidence based on: magnitude strength, number of detection frames, angle consistency
- `reset()` — clears ring buffer after shot processed
- Supports two instances on different ports for dual-module (vertical + horizontal)

**`types.py`** — Data types:

```python
@dataclass
class KLD7Angle:
    vertical_deg: float | None  # Populated when orientation="vertical"
    horizontal_deg: float | None  # Populated when orientation="horizontal"
    distance_m: float
    magnitude: float
    confidence: float  # 0.0 - 1.0
    num_frames: int  # Frames with detection in the event

@dataclass
class KLD7Frame:
    timestamp: float
    tdat: dict | None  # Single tracked target
    pdat: list[dict]  # All raw detections
```

### Server Integration

**CLI flags** (server.py + start-kiosk.sh):

| Flag | Default | Description |
|---|---|---|
| `--kld7` | off | Enable K-LD7 module |
| `--kld7-port` | auto-detect | Serial port |
| `--kld7-orientation` | `vertical` | `vertical` or `horizontal` |

Future (second module): `--kld7-port-2`, `--kld7-orientation-2`

**Startup:**
1. If `--kld7` present, create `KLD7Tracker`, connect, start background thread
2. Non-fatal on failure — warn and continue without angle radar (like camera)

**Shot attachment** (in `on_shot_detected()`):
1. OPS243 creates shot with speed + spin
2. K-LD7 step: `kld7_tracker.get_angle_for_shot()` → `KLD7Angle`
3. Attach to shot: `shot.launch_angle_vertical` or `shot.launch_angle_horizontal` per orientation
4. Reset ring buffer

**Angle priority chain (vertical):**
1. K-LD7 radar (highest — direct measurement)
2. Camera (medium — visual tracking)
3. Estimation from club/speed (lowest)

**Angle priority chain (horizontal):**
1. K-LD7 radar (when horizontal module connected)
2. Camera (existing)
3. None (no estimation)

K-LD7 data overrides camera data when both are present.

### Carry Distance

**Vertical angle:** No formula changes. `adjust_carry_for_launch_angle()` already penalizes deviation from optimal launch angle per club type. K-LD7 provides better input data with higher confidence.

**Horizontal angle** (when available): `carry_along_target = carry * cos(horizontal_angle_rad)`. Applied after all other adjustments (spin, smash factor). A 10° offline shot loses ~1.5% carry.

### UI Changes

**Current:** Ball speed gauge + 4 metric cards (carry, club speed, launch angle, spin)

**Changes:**
- Rename "Launch Angle" → **"Vertical"** — vertical launch angle in degrees
- Add **"Horizontal"** card — horizontal angle in degrees (positive = right of target)
- Subtext shows source: "radar" or "estimated"
- Horizontal card hidden when no horizontal data available
- Same confidence indicator pattern (high/medium/low)

## Data Flow

```
K-LD7 (USB serial)              OPS243-A (USB serial)
    │                                │
    ▼                                ▼
KLD7Tracker                    RollingBufferMonitor
(background thread)            (capture thread)
    │                                │
    │ ring buffer                    │ trigger → process → Shot
    │ (~2s of TDAT/PDAT)             │ (speed + spin)
    │                                │
    └──────────┐    ┌────────────────┘
               ▼    ▼
         on_shot_detected()
               │
               ├── kld7_tracker.get_angle_for_shot()
               ├── camera_tracker.calculate_launch_angle() [fallback]
               ├── estimate_launch_angle() [last resort]
               ├── adjust carry for angles
               ├── session_logger.log_shot(...)
               └── socketio.emit("shot", ...)
                        │
                        ▼
                    React UI
                (vertical + horizontal cards)
```

## Hardware

**Single module (tomorrow's test):**
- K-LD7 on EVAL board, mounted vertically (90° rotation)
- Provides vertical launch angle
- `/dev/ttyUSB*` via FTDI

**Dual module (future):**
- Module 1: mounted vertically → vertical angle
- Module 2: bare K-LD7 + FTDI cable (~$95) → horizontal angle
- Two `/dev/ttyUSB*` ports, two `KLD7Tracker` instances

## Known Limitations

1. **Speed aliasing:** K-LD7 max 100 km/h; golf ball speeds alias. Speed data ignored — OPS handles speed.
2. **~34 fps without FFT:** 1-2 frames per ball pass at golf speed. May limit angle accuracy.
3. **Golf ball RCS:** Detection at 5m validated indoors with tossed balls. Full-speed struck balls unverified.
4. **Single-plane per module:** Each K-LD7 measures one angle plane only.

## Module Responsibilities (Clean Separation)

| Measurement | Module | Notes |
|---|---|---|
| Ball speed | OPS243-A | Primary measurement |
| Club speed | OPS243-A | From pre-impact readings |
| Spin rate | OPS243-A | Rolling buffer I/Q analysis |
| Vertical angle | K-LD7 (vertical mount) | Replaces camera when available |
| Horizontal angle | K-LD7 (horizontal mount) | Future second module |
| Distance | K-LD7 | Bonus data, not used in carry calc yet |

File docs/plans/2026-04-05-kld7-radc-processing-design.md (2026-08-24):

# K-LD7 Raw ADC Processing — Design Spec

**Date:** 2026-04-05
**Status:** Draft

## Goal

Replace dependence on the K-LD7's internal detector (PDAT) with custom FFT + CFAR processing on raw ADC samples (RADC). This gives us control over detection threshold, FFT resolution, and angle estimation — the same signal-processing chain that commercial launch monitors use.

## Background

The K-LD7 currently outputs processed detections (PDAT) at ~34 fps. A golf ball appears in only 1-2 PDAT frames because the module's internal detector is conservative. With raw I/Q we can run longer FFTs, lower thresholds, and potentially recover ball returns the module discards.

### RADC Frame Structure

3072 bytes per frame at ~34 fps:

| Segment | Content | Size |
|---|---|---|
| F1 Freq A | 256 I samples (uint16) + 256 Q samples (uint16) | 1024 bytes |
| F2 Freq A | 256 I samples (uint16) + 256 Q samples (uint16) | 1024 bytes |
| F1 Freq B | 256 I samples (uint16) + 256 Q samples (uint16) | 1024 bytes |

Two frequencies (F1, F2) enable phase-difference angle estimation between Rx channels.

### Bandwidth Requirement

RADC at 34 fps = ~102 KB/s. Current baud rate of 115200 (~11.5 KB/s) is insufficient. Must use 3 Mbaud for reliable RADC streaming.

## Deliverables

### 1. Capture Script — `scripts/capture_kld7_radc.py`

**Purpose:** Stream and record raw ADC data from a single K-LD7 for offline analysis.

**Behavior:**
- Connect to K-LD7 at specified port and baud rate (default 3 Mbaud)
- Stream `RADC | PDAT | TDAT` simultaneously
- RADC for custom processing, PDAT/TDAT for comparison against module's detector
- Record continuously for a specified duration
- Save to `.pkl` with metadata

**CLI:**
```bash
./scripts/capture_kld7_radc.py --port /dev/ttyUSB0 --orientation vertical --duration 60
./scripts/capture_kld7_radc.py --port /dev/ttyUSB0 --baud 3000000 --duration 30
```

**Output `.pkl` structure:**
```python
{
    "metadata": {
        "module": "K-LD7",
        "port": "/dev/ttyUSB0",
        "baud_rate": 3000000,
        "orientation": "vertical",
        "capture_start": "2026-04-05T...",
        "capture_end": "2026-04-05T...",
        "total_frames": N,
        "params": {...},  # K-LD7 config params
    },
    "frames": [
        {
            "timestamp": float,
            "radc": {
                "f1a_i": np.ndarray,  # (256,) uint16
                "f1a_q": np.ndarray,  # (256,) uint16
                "f2a_i": np.ndarray,  # (256,) uint16
                "f2a_q": np.ndarray,  # (256,) uint16
                "f1b_i": np.ndarray,  # (256,) uint16
                "f1b_q": np.ndarray,  # (256,) uint16
            },
            "tdat": dict | None,  # module's tracked target
            "pdat": list[dict],  # module's raw detections
        },
        ...,
    ],
}
```

### 2. Analysis Library — `scripts/kld7_radc_lib.py`

**Purpose:** Standalone helpers for processing RADC captures. No dependency on the main `openflight` package.

**Dependencies:** `numpy` only. Plotting lives in the analysis script, not here.

#### FFT Processing

- `parse_radc_frame(frame) -> dict` — Extract I/Q arrays from raw RADC bytes
- `compute_range_doppler(iq_complex, fft_size=2048) -> np.ndarray` — Hann window, zero-pad, FFT, magnitude spectrum
- `cfar_detect(spectrum, guard_cells=4, training_cells=16, threshold_factor=8.0) -> list[Detection]` — OS-CFAR on the range-Doppler spectrum, returns peaks above adaptive noise floor

#### Spatial Filtering

- `estimate_angle_from_phase(f1_complex, f2_complex) -> float` — Phase-difference angle estimation between the two frequency channels
- `filter_by_distance(detections, min_m, max_m) -> list` — Distance gate
- `filter_by_velocity(detections, min_kmh, max_kmh) -> list` — Velocity gate

#### Ball Isolation

- `find_ball_candidates(frames, club_event_time) -> list` — Distance gate 2-6m, fast outbound, short burst, appearing after club event
- `compare_radc_vs_pdat(frame) -> dict` — Side-by-side comparison of what our FFT finds vs what the module's PDAT reported

#### Data Types

```python
@dataclass
class RADCDetection:
    frame_index: int
    timestamp: float
    distance_m: float
    velocity_kmh: float
    angle_deg: float  # from phase difference
    magnitude: float  # FFT bin magnitude
    snr_db: float  # signal-to-noise from CFAR
    bin_index: int  # FFT bin number
```

### 3. Analysis Script — `scripts/analyze_kld7_radc.py`

**Purpose:** Visualize and explore RADC captures.

**Dependencies:** `numpy`, `matplotlib`

**CLI:**
```bash
# Full analysis
./scripts/analyze_kld7_radc.py capture.pkl

# Zoom to detected swing windows
./scripts/analyze_kld7_radc.py capture.pkl --shot-windows

# Export detections to CSV
./scripts/analyze_kld7_radc.py capture.pkl --csv
```

**Generated outputs:**
- Range-Doppler heatmap per frame (around swing events)
- Detection timeline: our FFT detections vs PDAT detections on same time axis
- Distance vs time scatter for ball candidates
- Per-shot comparison table (CSV): our detection count, angles, magnitudes vs PDAT

## FFT Parameters

| Parameter | Value | Rationale |
|---|---|---|
| Window | Hann | Standard for spectral analysis, good sidelobe suppression |
| Input samples | 256 (from RADC) | Fixed by hardware |
| Zero-pad to | 2048 | 8× interpolation, ~0.15 m/s velocity resolution |
| CFAR guard cells | 4 | Prevent target self-masking |
| CFAR training cells | 16 | Enough for noise estimate |
| CFAR threshold | 8.0× (start) | Tunable — lower = more sensitive, more false alarms |

## What This Is Not

- **Not a live replacement for the PDAT tracker** — purely offline analysis to validate the approach
- **Not coherent integration across frames** — single-frame FFT first, multi-frame stacking is a future step if this shows promise
- **Not dual-K-LD7** — single vertical unit for now, horizontal comes later

## Success Criteria

1. Capture script reliably records RADC at 3 Mbaud without dropped frames
2. Our FFT + CFAR finds at least as many ball detections as PDAT on the same capture
3. We can see ball returns in the range-Doppler map that PDAT missed
4. Phase-based angle estimation produces reasonable values (within ±10° of PDAT angles)

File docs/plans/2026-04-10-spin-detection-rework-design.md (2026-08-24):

# Spin Detection Rework: Amplitude Envelope Demodulation

## Problem

The current spin detection extracts ~30 ball speed values from overlapping FFT windows (937 Hz effective sample rate), then runs a secondary 256-point FFT to find spin modulation frequency. With only 30 data points, the frequency resolution is 220 RPM/bin — too coarse to detect real spin. 81% of captures show spectral leakage artifacts, and the 19% that "pass" are Hann window sidelobe artifacts at exactly 1318 and 1538 rpm (FFT bins 6 and 7).

## Approach

Work directly on the raw 4096 I/Q samples (30 kHz, 136.5ms) instead of ~30 extracted speed values. The golf ball seam creates amplitude modulation at **2x spin rate** as it crosses the radar beam twice per revolution. Bandpass filter the I/Q signal around the ball's Doppler frequency, extract the amplitude envelope, then find the spin frequency using FFT (primary) with autocorrelation fallback for low-cycle signals (drivers).

This gives us ~100x more data points for spin analysis and ~2x finer frequency resolution.

## Signal Processing Pipeline

```
Raw I/Q (4096 samples, 30 kHz, from IQCapture)
    │
    ├─ Existing pipeline → ball_speed_mph (from process_capture)
    │
    ▼
1. Convert ball speed to Doppler frequency
   ball_doppler_hz = 2 * ball_speed_mps / wavelength_m

2. Bandpass filter I/Q around ball_doppler_hz
   - Complex signal: I + jQ
   - 4th order Butterworth bandpass, ±200 Hz around ball Doppler
   - Using scipy.signal.sosfiltfilt (zero-phase, no group delay)
   - Isolates ball return from club, body movement, and noise

3. Extract amplitude envelope
   envelope = abs(filtered_complex_signal)
   Full capture: ~4096 samples at 30 kHz

4. Trim to ball-present window
   - Use ball_timestamp_ms from existing speed detection to locate ball onset
   - Convert to sample index: start_sample = ball_timestamp_ms * 30
   - Take from ball onset to end of capture (typically 30-80ms = 900-2400 samples)
   - Require minimum 600 samples (~20ms) to proceed

5. Remove DC offset, apply Hann window
   - Subtract mean from envelope (removes DC component)
   - Apply Hann window to reduce spectral leakage

6. Primary detection: FFT on envelope
   - Zero-pad to 8192 for spectral interpolation
   - Frequency resolution: 30000/8192 = 3.66 Hz ≈ 110 RPM
   - Search for peak in seam frequency range: 80-670 Hz
     (corresponds to 2400-20000 RPM via 2x seam relationship)
   - Calculate SNR: peak magnitude / median of valid frequency range
   - Reject peaks in first 2 bins (DC leakage)

7. Fallback detection: Autocorrelation on envelope
   - Used when FFT SNR is marginal (< 5.0) but above noise (> 2.0)
   - Compute normalized autocorrelation of the windowed envelope
   - Search for first significant peak at lag corresponding to 80-670 Hz
   - Lag range: 30000/670 = 45 samples to 30000/80 = 375 samples
   - Peak must exceed 0.3 normalized correlation to be valid
   - If autocorrelation confirms FFT frequency (within 10%), boost confidence

8. Convert seam frequency to spin RPM
   spin_rpm = (peak_frequency_hz / 2) * 60
   Divide by 2 because seam crosses beam twice per revolution.

9. Quality assessment
   - "high": FFT SNR >= 8 AND >= 5 seam cycles in the trimmed window
   - "medium": FFT SNR >= 5, OR autocorrelation confirms FFT peak
   - "low": FFT SNR >= 3, marginal detection
   - Reject: SNR < 3, or peak in first 2 bins, or fewer than 2 seam cycles
```

## Expected Detection Performance

| Club | Typical Spin | Seam Freq | Cycles in 60ms | Expected Result |
|---|---|---|---|---|
| Wedge | 8000-10000 rpm | 267-333 Hz | 16-20 | High confidence |
| 9-iron | 7000-9000 rpm | 233-300 Hz | 14-18 | High confidence |
| 7-iron | 5000-7000 rpm | 167-233 Hz | 10-14 | High confidence |
| 5-iron | 4000-5500 rpm | 133-183 Hz | 8-11 | Medium-high |
| 3-iron | 3500-4500 rpm | 117-150 Hz | 7-9 | Medium |
| Driver | 2500-3500 rpm | 83-117 Hz | 5-7 | Medium (FFT+autocorrelation) |
| Driver (low) | 2000-2500 rpm | 67-83 Hz | 4-5 | Low-medium (autocorrelation) |

## Bandpass Filter Design

- Type: 4th order Butterworth
- Center: ball_doppler_hz (computed from OPS243 ball speed)
- Bandwidth: ±200 Hz (400 Hz total)
- Implementation: `scipy.signal.butter` + `sosfiltfilt` (sos form for numerical stability)
- The ±200 Hz window captures the ball's Doppler peak plus spin-induced spectral broadening while rejecting club returns (which are at a different Doppler frequency)

### Doppler Frequency Examples

| Ball Speed | Doppler Frequency | Filter Band |
|---|---|---|
| 80 mph | ~1930 Hz | 1730-2130 Hz |
| 120 mph | ~2900 Hz | 2700-3100 Hz |
| 160 mph | ~3860 Hz | 3660-4060 Hz |

All within the 0-15 kHz Nyquist bandwidth of 30 ksps sampling.

## Files Changed

### Modified: `src/openflight/rolling_buffer/processor.py`

**`detect_spin()`** — Replace internals entirely. New signature:
```python
def detect_spin(self, capture: IQCapture, ball_speed_mph: float, 
                ball_timestamp_ms: float) -> SpinResult:
```
Instead of the current:
```python
def detect_spin(self, ball_speeds: List[float], sample_rate_hz: float) -> SpinResult:
```

**`process_capture()`** — Update to pass `IQCapture` and `ball_speed_mph` to `detect_spin` instead of extracted ball speed values.

**Keep `extract_ball_speeds()`** — still used for the speed timeline, just no longer feeds spin detection.

### Unchanged
- `SpinResult` dataclass in `types.py` — same fields: `spin_rpm`, `confidence`, `snr`, `quality`
- `server.py` — consumes `SpinResult` from `ProcessedCapture`, no changes
- Session logger, UI, Alloy pipeline — all consume spin_rpm/quality unchanged
- Trigger, monitor, K-LD7 code — unrelated

## Constants

```python
# Spin detection via amplitude envelope demodulation
SPIN_BANDPASS_BW_HZ = 200  # ±200 Hz around ball Doppler
SPIN_BANDPASS_ORDER = 4  # Butterworth filter order
SPIN_FFT_SIZE = 8192  # Zero-padded FFT for envelope
SPIN_MIN_SEAM_HZ = 80  # 2400 RPM minimum (seam = 2x spin)
SPIN_MAX_SEAM_HZ = 670  # 20000 RPM maximum
SPIN_MIN_SAMPLES = 600  # ~20ms minimum ball signal
SPIN_SNR_HIGH = 8.0  # High confidence threshold
SPIN_SNR_MEDIUM = 5.0  # Medium confidence threshold
SPIN_SNR_MIN = 3.0  # Minimum to report
SPIN_AUTOCORR_THRESHOLD = 0.3  # Minimum normalized correlation
SPIN_MIN_CYCLES = 2  # Minimum seam cycles to report
```

## Testing Strategy

1. **Synthetic signal test**: Generate I/Q with known Doppler frequency and amplitude modulation at known spin rate. Verify `detect_spin` recovers the correct RPM.
2. **Multiple spin rates**: Test at 3000, 5000, 7000, 10000 RPM to cover the full range.
3. **No-spin test**: Flat amplitude envelope (no modulation) should return no spin.
4. **Noise robustness**: Add white noise to synthetic signal, verify detection degrades gracefully.
5. **Real capture validation**: Run against the driving range session data (session_20260410) to check that the new method doesn't produce the 1318/1538 artifacts.

## Validation Against Real Data

After implementation, re-analyze `session_logs/session_20260410_110759_range.jsonl` (68 shots from driving range). Success criteria:
- No more 1318/1538 rpm quantized values
- Iron/wedge spin detection rate > 50% (currently 19% but with fake values)
- Detected spin values in expected ranges per club (driver 2500-3500, iron 4000-8000, wedge 8000-12000)
- "No spin detected" is preferred over reporting incorrect values

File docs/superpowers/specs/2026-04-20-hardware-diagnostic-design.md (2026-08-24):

# Hardware Diagnostic Script

**Date:** 2026-04-20
**Status:** Approved
**Scope:** A unified guided diagnostic script that verifies every hardware component of the OpenFlight launch monitor — OPS243-A radar, both K-LD7 angle radars, the sound trigger, and the rolling buffer hardware trigger path.

## Problem

The repo has 5+ separate hardware test scripts (`test_kld7.py`, `test_radar_raw.py`, `test_sound_trigger_hardware.py`, `test_rolling_buffer_persist.py`, `debug_hardware_trigger.py`). Each tests one thing. There's no single "is the device fully working?" check — a user setting up a new build or debugging a failure has to run each script, interpret its output independently, and remember which flags each accepts. A unified diagnostic reduces setup friction and provides a clear pass/fail signal for support.

## Approach

Single Python script at `scripts/hardware-test/diagnose.py` that runs 6 checks in sequence. Each check is a function returning a `CheckResult`. Shared state (open serial handles, detected ports) is passed between checks via a `DiagnosticState` dataclass. Reuses existing `OPS243Radar`, `KLD7Tracker`, and `RollingBufferProcessor` — no new dependencies.

Guided walkthrough model: the diagnostic prompts the user at moments that require physical interaction (sound trigger). Connectivity checks run automatically. Missing optional hardware skips cleanly with a clear reason.

## Architecture

**File:** `scripts/hardware-test/diagnose.py` (one file)

**Entry point:** `uv run python scripts/hardware-test/diagnose.py`

**Flags:**
- `--require-all` — skipped checks (e.g., only one K-LD7 detected) fail instead of pass
- `--no-interactive` — skip checks that require user action (Check 6)
- `--timeout-multiplier N` (default 1.0) — scale all per-check timeouts for slow environments

**Data structures:**

```python
@dataclass
class CheckResult:
    name: str
    status: Literal["pass", "fail", "skip"]
    detail: str = ""  # one-line primary message
    hint: str = ""  # remediation suggestion on fail
    elapsed_s: float = 0.0

@dataclass
class DiagnosticState:
    """Shared state between checks so later ones can skip cleanly."""

    ops243_port: Optional[str] = None
    ops243_radar: Optional[OPS243Radar] = None  # held open across checks
    kld7_vertical_port: Optional[str] = None
    kld7_horizontal_port: Optional[str] = None
```

**Top-level flow:**

```python
CHECKS = [
    check_ops243_connectivity,
    check_ops243_rolling_buffer_persisted,
    check_ops243_software_trigger,
    check_kld7_vertical,
    check_kld7_horizontal,
    check_sound_trigger_end_to_end,
]

def main():
    state = DiagnosticState()
    results = []
    try:
        for check in CHECKS:
            print_check_start(check.__name__)
            result = run_with_timeout(check, state)
            results.append(result)
            print_check_result(result)
    finally:
        if state.ops243_radar:
            state.ops243_radar.disconnect()
    print_summary(results)
    sys.exit(0 if all_pass(results) else 1)
```

## The 6 Checks

### Check 1 — OPS243 connectivity (~2s)
- Auto-detect by scanning `/dev/ttyACM*` and `/dev/ttyUSB*`, try `OPS243Radar.connect()` at 57600 baud.
- Query `get_info()` and `get_firmware_version()`; PASS if either returns a usable response.
- Detail on pass: `"{port} • firmware {version}"`
- Hint on fail: `"Check USB connection and permissions (dialout group)"`
- Stores `state.ops243_port` and `state.ops243_radar` (kept open for Checks 2–3 and 6).

### Check 2 — OPS243 rolling buffer persisted (~1s)
- Queries current boot mode via `get_info()`. Verifies the radar is already in rolling buffer mode (G1/GC) without us configuring it — this proves the `A!` persistence from the setup script is active.
- Detail on pass: `"Radar boots in rolling buffer mode (G1)"`
- Hint on fail: `"Run 'uv run python scripts/hardware-test/test_rolling_buffer_persist.py --setup' then power cycle the radar"`
- Skipped (cascade) if Check 1 failed.

### Check 3 — OPS243 software trigger (~3s)
- Calls `radar.trigger_capture(timeout=5)`. Parses response through `RollingBufferProcessor.parse_capture()`. Verifies 4096 I/Q samples.
- Detail on pass: `"Capture received: 4096 I/Q samples"`
- On fail, detail distinguishes "no response" vs "malformed response":
  - No response: `"Software trigger sent but no I/Q response received"`
  - Malformed: `"Response received but parse failed: {parse_error}"`
- Skipped if Check 2 failed.

### Check 4 — K-LD7 vertical connectivity (~3s)
- Scans serial ports for FTDI/CP210x devices matching K-LD7 descriptors (reusing logic from `test_kld7.py`). If two match, uses the first one; the second is reserved for Check 5.
- Instantiates `KLD7Tracker(orientation="vertical")`, connects, streams for 1 second, verifies at least 5 frames received.
- Detail on pass: `"{port} • {frame_count} frames in 1.0s (~{fps} fps)"`
- Hint on fail: distinguishes "no K-LD7 detected on any serial port" vs "detected but no frames streaming".
- Disconnects after check so Check 5 can claim the other unit.

### Check 5 — K-LD7 horizontal connectivity (~3s)
- Same logic as Check 4, using the second detected K-LD7. Uses `orientation="horizontal"`.
- If only one K-LD7 was detected, SKIP with detail `"Only one K-LD7 detected — horizontal is optional"`.
- `--require-all` converts this skip to a fail.

### Check 6 — Sound trigger end-to-end (~20s, interactive)
- Calls `radar.rearm_rolling_buffer()` first (since Check 3's software trigger consumed the previous buffer).
- Prompts: `"Clap loudly or tap the SEN-14262 sensor. Waiting up to 15 seconds..."`
- Calls `radar.wait_for_hardware_trigger(timeout=15)`. On trigger, parses the capture, verifies 4096 samples.
- Detail on pass: `"Hardware trigger fired, capture valid (4096 samples)"`
- Hint on timeout: `"Check SEN-14262 wiring to OPS243 HOST_INT pin. Adjust R17 resistor if sensor too quiet."`
- On malformed response: distinguishes "trigger fired but capture bad" from no trigger.
- Skipped if Check 3 failed. Skipped with `--no-interactive`.

**Ordering rationale:** Later checks depend on earlier ones — connectivity → persistence → trigger. Failing a prerequisite cascade-skips dependent checks, producing a clear "OPS243 broken → these 4 checks skipped because of it" rather than a cascade of red.

## Output Format

Color-coded live checklist. Colors auto-disable when `stdout` isn't a TTY.

```
OpenFlight Hardware Diagnostic
========================================

[1/6] OPS243 connectivity ............... ✓ PASS (1.2s)
        /dev/ttyACM0 • firmware v1.2.3

[2/6] OPS243 rolling buffer persisted ... ✓ PASS (0.8s)
        Radar boots in rolling buffer mode (G1)

[3/6] OPS243 software trigger ........... ✓ PASS (2.1s)
        Capture received: 4096 I/Q samples

[4/6] K-LD7 vertical .................... ✓ PASS (2.5s)
        /dev/ttyUSB0 • 42 frames in 1.0s (~42 fps)

[5/6] K-LD7 horizontal .................. ⊘ SKIP
        Only one K-LD7 detected — horizontal is optional
        Pass --require-all to fail on skipped optional components

[6/6] Sound trigger + rolling buffer ....
        ► Clap loudly or tap the SEN-14262 sensor now.
          Waiting up to 15 seconds...
        ✓ Trigger received after 3.2s
[6/6] Sound trigger + rolling buffer .... ✓ PASS (3.4s)
        Hardware trigger fired, capture valid (4096 samples)

========================================
Summary: 5 passed, 0 failed, 1 skipped (10.0s total)
Overall: ✓ HEALTHY
```

**Color scheme:** ✓ PASS green, ✗ FAIL red, ⊘ SKIP yellow, ⧗ (running) dim, hints dim gray, headings bold.

**Failure example:**

```
[3/6] OPS243 software trigger ........... ✗ FAIL (5.1s)
        Software trigger sent but no I/Q response received
        → Radar may be stuck in a non-rolling-buffer mode despite Check 2
        → Try power-cycling the radar and re-running
```

## Exit Codes

- `0` — all checks passed (skips allowed unless `--require-all`)
- `1` — one or more checks failed
- `2` — script usage error (bad flags)
- `130` — interrupted by user (Ctrl+C)

## Error Handling

- Each check runs inside `try/except Exception as e` — any uncaught exception becomes `status=fail` with `detail=f"Unexpected error: {type(e).__name__}: {e}"`. The diagnostic never crashes; it reports.
- `SerialException` with `[Errno 13] Permission denied` maps to hint: `"Add your user to the dialout group: sudo usermod -aG dialout $USER"`.
- `KeyboardInterrupt` handled at top level for clean Ctrl+C exit (130).
- `finally` in `main()` ensures any open serial handles in `state` are closed on any exit path.

## Timeouts

- Checks 1, 2, 4, 5: 10s soft timeout per check
- Check 3: 8s
- Check 6: 15s wait + 5s processing = 20s
- `--timeout-multiplier N` scales all values
- Implementation: `signal.alarm()` wrapper (POSIX only — fine for Linux Pi, the target environment)

## Testing

**In scope (unit tests in `tests/test_diagnose.py`):**
- `CheckResult` formatting helpers (color, status symbols)
- Summary function with synthetic result sets (all pass, some fail, all skip)
- Each check function's decision logic, with `OPS243Radar` / `KLD7Tracker` mocked — verifies the correct `CheckResult` is produced for each observable radar/tracker response pattern

**Out of scope:**
- Live hardware interaction (that's what the script itself is for)
- Mocking the serial-level protocol — too brittle, no real verification value

## Out of Scope / YAGNI

- JSON output (can add later if a health dashboard needs it)
- Metrics export to Prometheus/Alloy (observability is already wired up elsewhere)
- CI integration beyond running the unit tests
- Web-based version of the diagnostic
- Fixing hardware problems detected (diagnostic is read-only; setup scripts already exist for fixes)

## Files Created / Modified

| File | Change |
|---|---|
| `scripts/hardware-test/diagnose.py` | New |
| `tests/test_diagnose.py` | New |
| `README.md` | Add "Diagnostic" section pointing to the new script |

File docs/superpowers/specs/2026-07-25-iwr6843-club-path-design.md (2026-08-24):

# IWR6843 Club Path From Pre-Impact Frames

**Date:** 2026-07-25
**Status:** Approved
**Scope:** Measure true club path (in-to-out / out-to-in) from the IWR6843's pre-impact frames, and fix three defects in the existing angle pipeline that would otherwise make the new measurement untrustworthy: a plain-mean channel combine, a span gate that rejects usable tracks, and hardcoded confidence values on both launch angles.

## Problem

`Shot.club_path_deg` exists and is wired end to end — session logger, WebSocket payload, GSPro `Path` field, and the `spin_axis_deg` derivation at `server.py:2156`. Its only producer was the deprecated K-LD7 horizontal radar, so the field is permanently `None` on the IWR6843 path.

The IWR6843 firmware retains 6 pre-impact frames explicitly for future club metrics. Nothing consumes them.

Separately, the 2026-07-25 range sessions exposed three defects in the vertical launch path that must be fixed alongside, because club path inherits the same machinery and feeds the same derived metric:

1. `lcmf.py:658` averages the two channel estimates unweighted. When one channel collapses, the reported angle is the mean of a good estimate and a broken one.
2. `REJECT_MIN_SPAN_S = 0.018` rejects tracks that produce good estimates.
3. `server.py:1892` and `:1900` hardcode `0.95` confidence for both launch angles, discarding the quality signals the estimators already compute.

## Evidence From Current Code And Captured Data

All findings below come from the 15 captures in `session_logs/iwr/` (sessions `20260725_130951` and `20260725_140533`), replayed offline.

### The club region is stored, and there is a club-like mover in it

`Geometry.loop_time` maps ring slot to time via `(frame - trigger_frame) % n_frames`, so slot-order 0 is the **oldest** retained frame and impact sits at slot-order 6. The pre-impact frames are therefore slot-orders 0–6.

Those frames carry range bins 20–72 = **0.94–3.38 m**, which covers the tee at 1.372 m. The observed window schedule matches `firmware/README.md` exactly on all seven captures of session `140533`: orders 0–6 → start bin 20, 7–11 → 32, 12–17 → 47.

Within the pre-impact frames every shot shows a strong mover in the club's neighbourhood, 60–1000× the frame-median power, closing from roughly 2.0 m to 1.55 m over the final 20 ms — about 22 m/s radial, consistent with the 66–79 mph club speeds the OPS243 measured for those same shots.

That mover is **not proven** to be the club head rather than hands or body. The design therefore treats identity as a gate, not an assumption: the club track's radial speed must be consistent with the OPS243 club speed for the shot, which is an independent measurement already available per shot.

### Range resolution and array shapes

- `range_res_m = RANGE_SPAN_M / range_fft_size` = 6.0 / 128 = **4.69 cm**. `geometry_from_header` on an unprojected 3-TX dump leaves `range_fft_size` unset and silently falls back to `6.0 / n_samples` = 11.3 cm. Always derive geometry from the projected 2-TX cube, as `process_dump` does.
- `tracking.mti_filter` returns a 5-D array `(frames, tx, loops, rx, bins)`. Power reductions must sum every axis except frames and bins; `movers_by_slot` sums `axis=(1, 2, 3)`.

### The `two8` channel collapses at this rig's geometry

Session `140533`, seven 7-irons, tilt 5.5°, radar height 0.229 m:

| shot | reported (mean) | `two8` | `four4_path_tdm` | component sd |
|---|---|---|---|---|
| 2 | 8.60 | −0.50 | 17.71 | 9.1 |
| 3 | 24.32 | 26.62 | 22.03 | 2.3 |
| 4 | 9.13 | −0.96 | 19.23 | 10.1 |
| 5 | 7.95 | −0.11 | 16.02 | 8.1 |
| 6 | 7.33 | −0.62 | 15.28 | 7.9 |
| 7 | 7.92 | −0.65 | 16.48 | 8.6 |

`four4_path_tdm` alone gives **17.8° ± 2.5°**, against this codebase's own table expectation of 17.1° for a 7-iron. The reported mean is 10.9°. The operator confirmed the shots flew normally, which is incompatible with 8° launches.

`two8` is also hypersensitive to assumed tilt — on identical data it reads −1.4° at tilt 0, −0.5° at 5.5°, and +16.6° at 10.4°, while `four4_path_tdm` moves roughly 1:1 with tilt as physics requires. A 4.9° change in one input moving an output 17° indicates an ill-conditioned fit, not a measurement. `two8` is also the only channel that does not receive the TDM cross-phase correction applied at `lcmf.py:234-241`, which is a plausible but unproven root cause.

### The span gate rejects usable tracks

Replaying with `REJECT_MIN_SPAN_S` relaxed from 0.018 to 0.015:

| session | accepted at 18 ms | at 15 ms | recovered four-path value |
|---|---|---|---|
| `140533` | 6/7 | 7/7 | shot 1 → 19.25° |
| `130951` | 1/7 | 2/7 | shot 6 → 21.16° |

Recovered values sit inside the existing cluster. Remaining failures are at 12.5–12.9 ms with 16–24 inliers and are genuinely thin.

Relaxing the gate **alone makes the product worse**: shot 1 at a 15 ms gate reports 8.79°, the mean of `two8 = −1.66` and `four4 = 19.25`. The relaxation is only worth shipping together with robust channel selection.

Gating on `component_std_deg` is also harmful in isolation: spread is 8–11° on nearly every shot *because* `two8` is broken, so an agreement gate would cut coverage from 7/7 to 1/7. Component agreement becomes a usable signal only once two healthy channels exist.

### Horizontal launch is healthy but reported dishonestly

HLCMF-v0 coherence across both sessions is 0.71–0.95, comfortably above its own 0.25 bar. `server.py:1900` reads `horizontal_confidence` into a local variable and then assigns `0.95` regardless.

## Approach

Estimate club path from the **rate of change** of the club's azimuth across the pre-impact frames, rather than from absolute azimuth.

Club path is a direction of travel, so it needs at least two spatial samples over time; a single azimuth reading cannot produce it. Given samples over time, two formulations are available:

- **Absolute:** convert each frame's phase to an absolute azimuth, build a Cartesian track, fit a line. Depends on `elem_phase_rad` from `iwr6843_calibration_reference.json`, measured on a different board.
- **Differential (chosen):** fit the azimuth *rate* and discard the constant offset. A per-element phase error common to every frame cancels in the difference.

The differential form is chosen because the 2026-07-25 sessions are a direct demonstration of what borrowed array calibration does to an absolute angle estimate. It still requires one external constant — where boresight sits relative to the target line — but that is a mount-aim value measured with a tape and a string, not inherited from another board.

```
path_deg = degrees(atan2(r · θ̇, ṙ)) + aim_offset_deg
```

where `θ̇` is the fitted azimuth rate, `ṙ` the club track's range rate, and `r` the club's range at impact.

### Expected precision

For a 3° club path at r ≈ 1.7 m and ṙ ≈ 22 m/s, the club moves ~2.3 cm laterally over the final 20 ms — roughly 0.8° of azimuth change, about 0.04 rad of phase. Against per-snapshot phase noise at the observed SNR, averaged over ~72 snapshots, this lands near **±1–2° of club path**.

That is sufficient to separate deliberate in-to-out from out-to-in swings (8–15° apart) and insufficient for a degree-level accuracy claim. The validation plan is set accordingly. This estimate is analytical and must be confirmed or refuted by the separation test.

> **Superseded by implementation (2026-07-25).** The polar formulation above
> (fit the azimuth *rate*, `path_deg = atan2(r · θ̇, ṙ) + aim_offset_deg`) was
> not what shipped, including the "Differential" bullet's rejection of the
> Absolute/Cartesian option above — that option is what `club.py` actually
> implements. This note records the divergence rather than rewriting the
> sections above; see `club.py`'s module docstring for the full derivation.
>
> The shipped formulation is Cartesian, not polar: each sample converts to
> `x = r · cos(az)`, `y = r · sin(az)`, weighted linear fits recover
> `v_x`/`v_y` directly, and `path_deg = atan2(v_y, v_x) + aim_offset_deg`.
> Both `x(t)` and `y(t)` are exactly linear in time for straight-line motion,
> so this fit is unbiased in the continuous limit — the polar/rate form was
> not (a fitted azimuth rate is a window-averaged rate through the fit's own
> mean time, not the instantaneous rate at impact; see `club.py` for the
> measured discrepancy on a synthetic fixture).
>
> Measured precision (first-principles fixture, `test_iwr6843_club_path.py`)
> is **±0.3° across ±12°** — 0.034° at 4°, 0.092° at 8°, 0.297° at +12°,
> 0.303° at −12°, growing with angle — not the "±1–2°" estimated above.
>
> The cancellation mechanism is also corrected here: absolute azimuth enters
> **additively** (`+ aim_offset_deg`), so it is only the *rate*/velocity
> terms that are immune to a constant per-element phase error, which is what
> makes `--iwr6843-azimuth-offset-deg` load-bearing rather than a mount-aim
> nicety. And the cancellation does not come from `elem_phase_rad` in
> `iwr6843_calibration_reference.json` as implied above — `club.py` never
> calls `cal.apply`. It comes from the TX2-vs-reference-antenna phase
> *difference* computed in `doa.tx2_phase_at`, which is why a common
> per-element error cancels regardless of which board it was measured on.
>
> The "azimuth-rate fit residual" named in the Failure Modes table below
> (`rejected_azimuth_fit`) is, correspondingly, now a cross-range fit
> residual (`club.py:277`), not a rate residual.

## Architecture

One new module, `src/openflight/iwr6843/club.py`, owns the club measurement. It stays out of `lcmf.py` (683 lines, owns vertical launch) and `shot.py` (owns the ball) because club path has its own gates, failure modes, and confidence.

Two targeted improvements to existing code, both non-breaking:

- **`tracking.py`** — `find_ball` hardcodes `BALL_GATES_M` and `SPEED_BOUNDS_MS` as module constants. Add them as keyword parameters defaulting to today's values so the club track reuses the RANSAC range-walk fitter instead of duplicating it. The function's docstring already notes that the club steals the track when gates are wrong, so the fitter demonstrably finds clubs; it needs pointing at one deliberately.
- **`doa.py`** — the per-`(frame, loop)` TX2 phase construction currently lives inside `lcmf._tx2_horizontal_proxy`. Extract it as a shared helper used by both the ball's horizontal proxy and the club estimator, so the TDM correction and per-RX circular median exist once.

`club.py` depends on `tracking`, `doa`, and `dump`. It does **not** depend on `lcmf`, keeping the two estimators independent.

### Data flow

```
capture.raw ──► process_dump()        ──► ball track      (existing)
            ├─► estimate_lcmf_v1()    ──► launch angles   (existing)
            └─► estimate_club_path()  ──► ClubPathResult  (new)
                      │
                runtime.process_shot() → IWR6843ShotResult(capture, measurement, club_path)
                      │
                server.py → shot.club_path_deg (gated on confidence)
                      │
                ├─ session log: iwr6843_capture.club_path
                ├─ WebSocket: club_path_deg          (field exists)
                └─ GSPro: Path                        (already mapped)
```

`runtime.py` is the seam: `IWR6843ShotResult` gains a `club_path` field and `process_shot` calls the new estimator alongside the existing one. No changes to the capture monitor.

## Components

### `club.py`

```
CLUB_SEARCH_HALF_WIDTH_M = 0.6           # window around the tee
CLUB_SPEED_BOUNDS_MS = (10.0, 45.0)      # radial; 66-79 mph clubs read ~22 m/s
CLUB_MIN_FRAMES = 4
CLUB_MIN_SNAPSHOTS = 24
CLUB_MAX_AZIMUTH_FIT_RESIDUAL_DEG = 0.5  # provisional, see below
CLUB_SPEED_PROJECTION_RANGE = (0.4, 0.95)

@dataclass ClubPathResult:
    status, path_deg, confidence,
    azimuth_rate_dps, range_rate_ms, club_range_m,
    n_frames, n_snapshots, fit_residual_deg,
    track_rms_bins, track_inliers, track_span_s

find_club(mti, geo, *, tee_range_m) -> BallTrack | None
estimate_club_path(raw, cal, *, ops_club_speed_mph, aim_offset_deg,
                   tdm_sign) -> ClubPathResult
```

Pipeline: parse and project the dump → MTI → `find_club` over the pre-impact window → per `(frame, loop)` TX2 phase from the shared `doa` helper → line fit of azimuth versus time → combine with the track's range rate → apply the aim offset and TrackMan sign.

**Club-speed gate as a projection window, not a tolerance.** The club track measures *radial* speed, which is the true club speed times an unknown projection factor. The observed 22 m/s against a 66 mph (29.5 m/s) club gives a factor of ~0.66. The gate therefore requires the track's radial speed to fall between 0.4× and 0.95× the OPS club speed in m/s, rather than within a symmetric tolerance of it. A symmetric tolerance would either reject every valid shot or admit anything.

**`CLUB_MAX_AZIMUTH_FIT_RESIDUAL_DEG` is provisional at 0.5°.** It cannot be derived analytically. Implementation sets it from the residual distribution observed across the 15 local captures plus the synthetic tests' noise floor, and the chosen value is recorded in the implementation plan. Until then 0.5° is a starting point, not a validated threshold.

**Sign conventions, stated explicitly because they are the easiest thing to get backwards:**

- `path_deg` follows TrackMan for a **right-handed** golfer: positive is in-to-out (club travelling rightward relative to the target line), negative is out-to-in. Left-handed operation is not handled; the existing `club_path_deg` contract has the same limitation and changing it is out of scope.
- `aim_offset_deg` is **added** to the measured path. A positive offset means the radar's boresight points to the *right* of the target line. It is exposed as `--iwr6843-azimuth-offset-deg`, following the existing `--kld7-angle-offset` precedent, and defaults to 0 with a log note that the reported path is then relative to boresight rather than the target line.

**`tdm_sign` source.** `estimate_club_path` does not resolve the TDM sign itself. The caller passes it: `runtime.process_shot` forwards `measurement.tdm_sign_used` from the ball estimate when one exists, and otherwise falls back to the configured `tdm_sign_policy` (`"positive"` in production). A club path computed on the fallback is still emitted but its status records `tdm_sign_fallback` so replay can tell the two cases apart.

### Fix 1 — robust channel selection (`lcmf.py`)

Replace `raw_angle_deg = float(np.mean(component_values))` with a robust combine: when the channel spread exceeds `CHANNEL_SPREAD_MAX_DEG = 8.0`, keep the channel with better own-fit evidence and multiply confidence by `SINGLE_CHANNEL_CONFIDENCE_FACTOR = 0.7`; otherwise take the mean as today.

The 8.0° threshold is set from the captured data rather than picked: the one shot whose channels agree has a spread of 4.59° (26.62 vs 22.03), while the collapsed shots span 15.9–20.2°. Nothing observed falls between, so the boundary sits in a genuine gap. The 0.7 derate is a policy choice, not a measurement — a single-channel estimate has no cross-check, and 0.7 keeps it above the fallback-estimate confidence of 0.5 while marking it as weaker than a corroborated one.

Shot 1 becomes 19.25° instead of 8.79°. The reference rig's behaviour at 10.4° tilt is unchanged because its channels agree. No channel model internals change.

### Fix 2 — span floor (`shot.py`)

`REJECT_MIN_SPAN_S = 0.015`. Ships with Fix 1, never alone.

### Fix 3 — derived confidence (`server.py`)

Vertical confidence derives from channel agreement and evidence count; horizontal confidence derives from HLCMF-v0 coherence. `spin_axis_deg` is emitted only when both legs clear their thresholds, rather than appearing the moment `club_path_deg` becomes non-null.

## Non-Goals

- Changing the HLCMF-v0 horizontal algorithm. Fix 3 only stops its coherence being discarded.
- Changing the `two8` channel model, including adding the missing TDM cross-phase. Fix 1 routes around it. If the cross-phase is the root cause, that is a separate change owned by the estimator's author, with its own TrackMan validation.
- Attack angle (vertical club path). Shares the pre-impact dependency and is a natural follow-on, but out of scope here.
- Any firmware change. The required data is already captured.

## Failure Modes

Club path is an independent estimator. Every failure leaves `club_path_deg` at `None` and does not affect ball speed, club speed, spin, or launch angle.

| Status | Cause |
|---|---|
| `rejected_no_club_track` | no mover in the tee window passes the club gates |
| `rejected_club_speed_mismatch` | track radial speed inconsistent with OPS club speed |
| `rejected_insufficient_snapshots` | fewer than `CLUB_MIN_FRAMES` / `CLUB_MIN_SNAPSHOTS` survive |
| `rejected_azimuth_fit` | azimuth-rate fit residual above threshold |
| `rejected_phase_wrap` | \|Δφ\| across the window exceeds π/2; the true change is ~0.04 rad, so anything near a wrap is a bad track |
| `rejected_no_pre_impact_frames` | `trigger_frame` leaves no pre-impact window |

## Logging

`iwr6843_capture` gains a `club_path` block carrying every `ClubPathResult` field.

The ball measurement dict gains **`track_span_s`**. Track span is the gate that rejected 7 of 8 shots in session `130951` and 1 of 7 in `140533`, and it is currently invisible without an offline replay. Any threshold that rejects a value must record the value it rejected.

## Testing

Synthetic-first, following `test_iwr6843_pipeline.py`, which packs a known target into the real wire format via `pack_dump`. Real captures cannot be committed: `.gitignore` excludes `session_logs/*/` and `session_logs/session_*.jsonl`.

- **Club path math** — synthesise a club with known azimuth and range rates; assert the recovered path within tolerance. Golden cases: pure radial → 0°, known lateral → known in-to-out, mirrored → out-to-in with the sign flipped. This test pins the sign convention.
- **Robust channel selection** — table-driven: spread above threshold drops the outlier, agreement takes the mean, single-channel derates confidence. Includes the exact `two8 = −1.66 / four4 = 19.25` case asserting 19.25°.
- **Span gate boundary** — 14.9 ms rejected, 15.1 ms accepted.
- **Confidence derivation** — low horizontal coherence yields low confidence; a regression test asserts `0.95` never appears as a literal confidence for either angle.
- **Spin axis gating** — emitted only when both legs pass; absent when either fails.
- **Failure-mode coverage** — one test per status in the table above.
- **Real-dump regression, opt-in** — `skipif`-guarded over `session_logs/iwr/`, asserting shot 1 → 19.25° and that the five collapsed shots report their four-path value. Skips on CI, runs locally.

## Validation

Club path has no ground truth at the operator's range, so acceptance is a **directional separation test** rather than an accuracy figure — the method PR #155 used for its horizontal launch proxy.

Three sessions of 10 shots each: deliberate in-to-out, square, deliberate out-to-in. The session boundary is the label, so no live intent-tagging is required.

`scripts/iwr6843/club_path_report.py` takes the three session JSONLs and reports group means, within-group spread, and whether the ordering separates.

**Pass criteria:** group means ordered correctly (out-to-in < square < in-to-out), and the gap between adjacent group means exceeding the within-group spread.

The feature ships marked experimental, reporting a separation result rather than an accuracy claim, until a TrackMan session can score it.

## Risks

- **The pre-impact mover may not be the club head.** Mitigated by the OPS club-speed cross-check as an acceptance gate rather than an assumption. If the mover turns out to be hands or body, the club-speed gate rejects and club path stays `None` — the failure is visible, not silent.
- **±1–2° precision may be too coarse even for separation** if the operator's deliberate in-to-out and out-to-in swings differ by less than a few degrees. The separation test detects this directly.
- **The aim offset is a new manual measurement.** A wrong offset biases every club path by a constant. It is recorded in the session config so a bad value can be corrected in replay rather than requiring a re-shoot.

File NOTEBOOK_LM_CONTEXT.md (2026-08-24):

# NOTEBOOK_LM_CONTEXT: OpenFlight Development (Launch Monitor, Force Plate & MoCap)

> **Agent Context Directive**: This notebook serves as the master knowledge base and context pack for AI agents and NotebookLM writing systems generating technical content, documentation, or articles for the **OpenFlight Development** ecosystem, specifically feeding launch monitor sensors, tri-axial force plate dynamics, and 3D motion capture articles.

---

## 1. Domain & Project Architecture

**OpenFlight Development** is an open-hardware and software telemetry suite integrating high-speed optical vision, FMCW Doppler radar, tri-axial force plate arrays, and 3D optical motion capture for athletic impact and movement analysis.

### Core Telemetry Subsystems:
```
                       +-----------------------------------+
                       |    Impact Event & Athlete Motion  |
                       +-----------------+-----------------+
                                         |
            +----------------------------+----------------------------+
            |                            |                            |
            v                            v                            v
 +----------------------+    +-----------------------+    +-----------------------+
 | Launch Monitor Optics|    |    Doppler Radar      |    | Force Plate Hardware  |
 | Stereo High-Speed    |    | 24/60 GHz FMCW        |    | Tri-Axial Strain Gauge|
 | Impact & Spin Axis   |    | Velocity & Range FFT  |    | GRF Vectors & COP     |
 +----------+-----------+    +-----------+-----------+    +-----------+-----------+
            |                            |                            |
            +----------------------------+----------------------------+
                                         |
                                         v
                       +-----------------------------------+
                       | Synchronized Telemetry Engine     |
                       +-----------------------------------+
```

---

## 2. Sensor Physics & Mathematical Derivations

### 2.1 Launch Monitor Sensor Physics
1. **High-Speed Optical Stereoscopic Imaging**:
   - Stereo pair intrinsic parameters matrix $K$ and extrinsic rotation/translation $[R | \mathbf{t}]$.
   - 3D marker centroid reconstruction from 2D pixel coordinates $(u, v)$ via epipolar geometry and triangulation.
   - Ball launch angle $\theta_{launch}$, azimuth $\phi_{az}$, ball speed $v_0$, and 3D spin vector $\boldsymbol{\omega}$ estimation.

2. **Doppler Radar (FMCW / Continuous Wave)**:
   - Baseband beat frequency $f_b = \frac{2 B R}{c T_c} + \frac{2 f_0 v}{c}$.
   - FFT range-Doppler processing for velocity tracking ($v_{club}, v_{ball}$) pre- and post-impact.

### 2.2 Force Plate Dynamics & Center of Pressure (COP)
Tri-axial force sensors measure Ground Reaction Force (GRF) vector components $\mathbf{F} = (F_x, F_y, F_z)^T$ and moments $\mathbf{M} = (M_x, M_y, M_z)^T$.

- **Center of Pressure (COP)**:
  $$
  x_{COP} = \frac{-M_y + F_x z_0}{F_z}, \quad y_{COP} = \frac{M_x + F_y z_0}{F_z}
  $$
  where $z_0$ is the vertical distance from sensor origin to the top plate surface.

- **Free Moment (Torque about vertical axis $T_z$)**:
  $$
  T_z = M_z - x_{COP} F_y + y_{COP} F_x
  $$

- **Shear Forces & Loading Rate**:
  - $F_x$: Lateral (side-to-side) shear force.
  - $F_y$: Anterior-Posterior (toe-to-heel) shear force.
  - Vertical Loading Rate: $dF_z / dt$ during transition from backswing to downswing.

### 2.3 3D Motion Capture & Kinematic Alignment
- **Segment Coordinate Systems (SCS)**: Defined for pelvis, thorax, lead upper arm, lead forearm, and club.
- **Euler / Cardan Angle Rotations**: $Z-Y'-X''$ sequence (Flexion/Extension, Abduction/Adduction, Internal/External Rotation).
- **Temporal Synchronization**: Triggering frame $t_0$ across optical cameras ($1000\text{ fps}$), Doppler radar ($100\text{ Hz}$ update), force plates ($1000\text{ Hz}$), and optical mocap ($250\text{ Hz}$).

---

## 3. Technical Article Drafting Frameworks

Use the structured context below to feed technical writing articles:

### Article Feeder 1: Launch Monitor Physics & Hardware Architecture
- **Focus**: Comparing optical high-speed vision vs FMCW radar for measuring launch parameters.
- **Key Points**: Photogrammetric error bounds, shutter speed requirements ($1/10,000\text{ s}$), rolling vs global shutter distortion, and spin axis vector calculation.

### Article Feeder 2: Ground Reaction Force (GRF) & COP Trajectory Analysis
- **Focus**: Biomechanics of ground force generation in explosive rotary athletic movements.
- **Key Points**: Lead vs trail foot vertical force distribution, COP trace path during downswing, peak vertical force timing relative to arm uncocking, and free moment $T_z$ torque creation.

### Article Feeder 3: Integrated 3D Motion Capture & Sensor Fusion
- **Focus**: Synchronizing force vectors with kinematic body segment movements.
- **Key Points**: Mapping GRF force vectors to joint moment centers, kinetic sequence energy transfer, and multi-sensor calibration protocols.

---

## 4. Key Terminology & Index for AI Agents

| Term | Definition | Context Usage |
| :--- | :--- | :--- |
| **GRF** | Ground Reaction Force 3D vector $(F_x, F_y, F_z)$ | Tri-axial force plate kinetics |
| **COP** | Center of Pressure $(x_{COP}, y_{COP})$ | Force centroid location on footbed/plate |
| **Smash Factor** | Ratio $v_{ball} / v_{club}$ | Impact efficiency parameter |
| **Free Moment ($T_z$)** | Pure rotational torque about vertical axis | Foot-ground friction interaction |
| **FMCW Radar** | Frequency-Modulated Continuous-Wave Radar | Ball & club velocity tracking |

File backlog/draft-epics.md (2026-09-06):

# Draft Epics — Hardware Bring-Up and Validation

**Archived:** 2026-09-06 · **Draft only — not filed, not tracked.**

The three former milestones of this repository, preserved as draft epics. Every
former open issue is reproduced below **verbatim**, under the epic it belonged to.
Issue numbers are retained only so that older references and the closure comments
on GitHub still resolve; the issues themselves are closed and will not be reopened.

The bodies are unedited, so they still say `jewbetcha/openflight`; that repo was
renamed and now redirects to [`open-flight/openflight`](https://github.com/open-flight/openflight).

## The dependency chain

This backlog is almost entirely serial, because it is physical work. That is the
single most useful thing to know about it — there is no parallel lane to pick up
when the current step is blocked on a part in the mail.

```
Build chain
  D1 bench prep ─┐
                 ├─► D4 Pi base ─► D5 OPS bring-up ─► D6 sound trigger ─► [M1]
  D2 procure ────┘
                 [M1] ─► D7 GPIO UART ─► D8 IWR6843 ─► D9 case + mount ─► [M2]

Validation chain
  [M1] ─► D10 interference A/B/AB ─┐
                                   ├─► D12 paired session ─► D21 driver truth data ─► [M3]
  [M2] ────────────────────────────┘
```

`D1` (bench prep) and `D2` (procurement) are the only two that can start
concurrently, and `D1` needs no Pi at all. `D10` (the interference A/B/AB) only
needs the ~$400 speed monitor from `D6`, so it is available well before the angle
radar arrives — and it must be settled before `D12`, or any later disagreement can
be blamed on OPS243/MLM2 cross-talk rather than on the instrument.

## Gate discipline

Every phase ends in a gate: a concrete command whose output proves the phase
worked. This mirrors the upstream principle that doing two things at once makes
any failure ambiguous. If a gate is red, the next phase is not started — that rule
is worth more than the issue tracker ever was.

---

## Draft Epic A — M1: A working speed monitor (~$400)

**Outcome:** an OPS243-A + Raspberry Pi 5 + sound-trigger rig that reports
plausible ball speed, club speed and smash factor on real shots, with a reliable
clap trigger and rolling-buffer capture that survives a power cycle.

**Why this epic is the one that matters.** It is genuinely useful on its own — no
angle radar required — and it is the point at which MLM2 Pro ball-speed spot checks
become possible, which is the entire premise of the contribution strategy. Nothing
downstream is reachable without it.

**Known traps captured in the drafts below.** The OPS243 WiFi (`-W`) variant locks
serial to 19200 baud and is incompatible with I/Q transfer, so the variant check in
`D1` is not a formality. The SEN-14262 needs an R17 gain resistor for 3.3 V
operation, and its LED behaviour is the gate. Rolling-buffer mode must persist
across a power cycle because upstream documents a firmware bug where the HOST_INT
pin mode switches on runtime mode transitions.

**Draft issues:** `D1`, `D2`, `D4`, `D5`, `D6`

<details>
<summary><b>D1 — Phase 0: Bench prep - verify OPS243 variants, solder R17</b></summary>

> Archived from closed issue #1 · labels: `build`

From [hardware/build-plan.md](https://github.com/D-sorganization/openflight_development/blob/main/hardware/build-plan.md) Phase 0 - no Pi required, can start now.

- [ ] Inspect both OPS243 boards: confirm neither is the WiFi `-W` variant (WiFi locks serial to 19200 baud - incompatible with I/Q transfer per upstream PARTS.md). Note serial numbers, label unit A (build) and unit B (bench).
- [ ] Solder 47 kOhm through-hole resistor into R17 on the SEN-14262 (gain fix for 3.3 V operation). Gate: LED flashes on clap, does not stick on. Fallback: 33 kOhm.
- [ ] Read upstream docs end-to-end: sound-trigger-wiring.md, PARTS.md, iwr6843/README.md, ops243-uart-migration.md.

**Exit gate:** both radars identified and labeled; SEN-14262 modded and LED behavior verified.

</details>

<details>
<summary><b>D2 — Procure core parts (Pi 5, display, PSU, SD, cables, resistors, RPT balls)</b></summary>

> Archived from closed issue #2 · labels: `procurement`

Buy the core block from [hardware/parts-list.md](https://github.com/D-sorganization/openflight_development/blob/main/hardware/parts-list.md) (~$220-235):

- [ ] Raspberry Pi 5 (4 GB+)
- [ ] Display - DECIDE FIRST: HMTECH 7" 1024x600 vs Raspberry Pi Touch Display 2 (IARC case parts differ per display; pick before printing)
- [ ] Official 27 W USB-C PSU
- [ ] microSD 64 GB
- [ ] USB-A to micro-USB data cable (OPS243)
- [ ] Data-capable USB cable for IWR6843LEVM (confirm connector when board arrives)
- [ ] Dupont F-F jumper pack (need 8+)
- [ ] 47 kOhm and 33 kOhm through-hole resistors
- [ ] RPT balls (Callaway Chrome Soft X RPT 3-pack) - spin ground truth for validation
- [ ] Decide: powered USB hub needed? (only if an OPS is WiFi variant or Layout B chosen)

</details>

<details>
<summary><b>D4 — Phase 1: Pi base system + mock-mode smoke test</b></summary>

> Archived from closed issue #4 · labels: `build`

From [hardware/build-plan.md](https://github.com/D-sorganization/openflight_development/blob/main/hardware/build-plan.md) Phase 1.

- [ ] Flash Raspberry Pi OS 64-bit, boot, network
- [ ] Clone jewbetcha/openflight and run `./scripts/setup/setup.sh` (interactive: uv, deps, UI build, auto-start prompts)
- [ ] Display working (per display choice)

**Exit gate:** `scripts/start-kiosk.sh --mock` shows simulated shots in the UI at http://localhost:8080.

</details>

<details>
<summary><b>D5 — Phase 2: OPS243 USB bring-up + rolling-buffer flash persistence</b></summary>

> Archived from closed issue #5 · labels: `build`

From [hardware/build-plan.md](https://github.com/D-sorganization/openflight_development/blob/main/hardware/build-plan.md) Phase 2.

- [ ] Connect OPS243 unit A over USB
- [ ] One-time flash config: `uv run python scripts/hardware-test/test_rolling_buffer_persist.py --setup`
- [ ] Power-cycle radar (unplug, wait 3 s, replug)

**Exit gate:** `test_rolling_buffer_persist.py --test` passes - rolling buffer mode persists across power cycle (required for HOST_INT hardware triggers; upstream documents a firmware bug where HOST_INT pin mode switches on runtime mode transitions).

</details>

<details>
<summary><b>D6 — Phase 3: Sound trigger wiring + first real shots</b></summary>

> Archived from closed issue #6 · labels: `build`

From [hardware/build-plan.md](https://github.com/D-sorganization/openflight_development/blob/main/hardware/build-plan.md) Phase 3, following upstream docs/sound-trigger-wiring.md.

- [ ] Wire: SEN-14262 VCC to Pi 3.3V (pin 1); GND to Pi GND (pin 6); GATE to OPS J3 pin 3 (HOST_INT); OPS J3 pin 10 to Pi GND (shared rail). J3 pin 1 is at the RIGHT end - confirm silkscreen.
- [ ] `uv run python scripts/hardware-test/test_sound_trigger_hardware.py` then clap: expect TRIGGER RECEIVED with 4096 I/Q samples
- [ ] Full diagnostic: `uv run python scripts/hardware-test/diagnose.py` (K-LD7 checks will skip)
- [ ] Hit real balls; skim session JSONL (`shot_detected`, `rolling_buffer_capture`, `trigger_diagnostic`)

**Exit gate:** reliable clap triggers AND plausible ball/club speed + smash on real shots. This is the ~$400 working-speed-monitor milestone - MLM2 Pro ball-speed spot checks become possible here.

</details>

---

## Draft Epic B — M2: Full unit with the IWR6843 angle radar

**Outcome:** measured launch angle (and experimental club path) from a
TI IWR6843LEVM mounted in a printed IARC case, with geometry measured rather than
guessed and a calibration session on record.

**The ordering constraint is hard.** The Pi cannot power both radars over USB, so
the OPS243 must move to the GPIO UART header *and be re-validated alone* before the
TI board is connected. On a Pi 5 the header UART is `/dev/ttyAMA0`; `/dev/serial0`
is the debug-header UART and will silently fail to be the thing you meant.

**The open design problem.** The IARC case STL set predates the IWR6843 migration
and carries K-LD7 mounts only — there is no LEVM mount. That gap has to be solved
by anyone building this, which makes a finished mount design the highest-value CAD
contribution available upstream (see `D9`). CAD PRs have historically merged fast
there.

**Geometry is the accuracy budget.** Tilt, tee slant range, net distance, radar
height and ball height are all measured from the antenna centre against a common
floor reference. Wrong values bias the result instead of producing an obvious
startup error, and small mount shifts appear as angle bias — so the mount must be
rigid and the geometry re-measured after any reassembly.

**Draft issues:** `D7`, `D8`, `D9`

<details>
<summary><b>D7 — Phase 4: Migrate OPS243 to Pi GPIO UART (Layout A)</b></summary>

> Archived from closed issue #7 · labels: `build`

From [hardware/build-plan.md](https://github.com/D-sorganization/openflight_development/blob/main/hardware/build-plan.md) Phase 4, following upstream docs/ops243-uart-migration.md. Required before the IWR6843 (the Pi cannot power both radars over USB).

- [ ] Wire OPS 5V (J3-9) to Pi pin 2/4; GND (J3-10) to Pi GND; OPS TxD (J3-7) to Pi RXD0 (pin 10); OPS RxD (J3-6) to Pi TXD0 (pin 8). TX/RX crossed.
- [ ] raspi-config: disable serial login shell, enable serial hardware, reboot
- [ ] Use `/dev/ttyAMA0` on Pi 5 (NOT `/dev/serial0` - that is the debug-header UART)
- [ ] Confirm user in `dialout` and `gpio` groups

**Exit gate:** everything from Phase 3 works identically on `--radar-port /dev/ttyAMA0`, validated BEFORE the TI board is connected (upstream: doing both at once makes any failure ambiguous).

</details>

<details>
<summary><b>D8 — Phase 5: IWR6843LEVM firmware flash + bring-up + calibration</b></summary>

> Archived from closed issue #8 · labels: `build`

From [hardware/build-plan.md](https://github.com/D-sorganization/openflight_development/blob/main/hardware/build-plan.md) Phase 5, following the upstream IWR6843 Operator Guide (docs/iwr6843/README.md).

Board confirmed ordered 2026-07: Digi-Key 296-IWR6843LEVM-ND (TI IWR6843LEVM) - correct variant (#3, closed).

- [ ] On arrival: verify silkscreen says IWR6843LEVM; identify USB connector type and confirm a data-capable cable is on hand; confirm boot-mode switch S1 and RESET button are accessible
- [ ] Verify firmware image hash: sha256 `3045bb2f087b40c228bf1dd5190cf3fac6dbde50682c7927e86714314b0e7fcb`
- [ ] Identify CP2105 Enhanced/UARTA interface (usually /dev/ttyUSB0, by-id ...if00-port0)
- [ ] Flash-mode switches; `firmware/flash_iwr6843.py --probe`; flash release image; functional-mode switches; RESET
- [ ] Three-way GATE splice: detector GATE to OPS HOST_INT AND Pi BCM17 (pin 11), soldered or lever connector
- [ ] Mount: antenna face down target line, vertical array vertical (TX above RX), ~0.152 m height, ~10 deg tilt starting point
- [ ] Measure geometry from antenna center and a common floor reference: tee-m (slant), net-m, tilt-deg (inclinometer), radar-height-m, ball-height-m (0.021 mat / 0.040 tee)
- [ ] First run with `--debug` and explicit ports/config/geometry
- [ ] Calibration session: `scripts/iwr6843/calibrate.py --shots 20 --club 7i ...` (stop kiosk first - it owns BCM17). Set tilt by PHYSICAL measurement; ignore edge-of-sweep tilt candidates (known unreliable upstream).
- [ ] If using club path: measure and pass `--iwr6843-azimuth-offset-deg`; run the 3-session separation test (`scripts/iwr6843/club_path_report.py`). Right-handed only for now.

**Exit gates:** clap gives `Capture complete: 549542 bytes` with `rf_faults=0`; real shots log `Angle source: radar` on trusted shots.

</details>

<details>
<summary><b>D9 — Phase 6: IARC case print + solve IWR6843 mount gap</b></summary>

> Archived from closed issue #9 · labels: `build`, `upstream`

From [hardware/build-plan.md](https://github.com/D-sorganization/openflight_development/blob/main/hardware/build-plan.md) Phase 6.

- [ ] Print IARC case v3 parts for the chosen display (`cad/IARC_case/` - `monitor_shell.stl` vs `Touch_Display2_*.stl` variants). Note upstream PR #147 / merged #156 reworked Touch Display 2 parts.
- [ ] Assemble: Pi, OPS mount, sensor housing, display shell, feet
- [ ] **Solve the IWR6843 mount gap:** the IARC case STL set predates the IWR6843 (K-LD7 mounts only, no LEVM mount). Check upstream cad/ and issues first; if absent, design one. Constraints from the operator guide: board rotated so the vertical virtual array is physically vertical, antenna face unobstructed, rigid mount (small shifts appear as angle bias).
- [ ] Re-measure ALL geometry after mounting; re-run a short calibration session

A finished IWR6843LEVM mount design is a strong upstream contribution - every new builder will need one.

</details>

---

## Draft Epic C — M3: Cross-validated against the MLM2 Pro

**Outcome:** a paired dataset that says, with numbers, how this rig compares
to a commercial reference instrument — and specifically a driver dataset that
upstream has asked for and does not have.

**This is the distinctive contribution.** Upstream's own words are that estimator
limits are "deferred pending a session paired with a reference instrument, which
this repo does not have." All of their truth data to date is three borrowed
TrackMan sessions. An MLM2 Pro plus RPT balls closes that gap.

**The specific upstream ask.** Driver is their weak point: 3.55° MAE and +3.39°
bias in the July 2026 field report, dominated by false-accepted slow "ghost" tracks
— the TI radar locking onto 55–57 mph movers while the OPS measured 152–158 mph
balls. Their proposed fix (reject TI tracks below ~65–70% of OPS ball speed, then
OPS-guided fast-track recovery) recovered 3 of 4 bad driver shots at ~2.6° MAE in
offline replay, and is explicitly blocked on more truth data. Driver blocks with
RPT balls are exactly that dataset.

**Settle interference first.** `D10` is not optional politeness. The MLM2 Pro radar
plausibly shares the OPS243's K-band neighbourhood (24.125 GHz CW); the IWR6843 at
60 GHz is unaffected. If cross-talk is not characterised before the paired session,
a maintainer can reasonably attribute any disagreement to cross-talk rather than to
the instrument, and the finding becomes contestable.

**Run with `--debug`.** The `.l3dump` captures are what make offline replay possible
(`scripts/iwr6843/replay.py`), and replay is how a dataset becomes a proposed fix
rather than just a complaint.

**Draft issues:** `D10`, `D12`, `D21`

<details>
<summary><b>D10 — Radar interference check: MLM2 Pro + OPS243 (A/B/AB protocol)</b></summary>

> Archived from closed issue #10 · labels: `validation`, `research`

From [validation/mlm2pro-cross-validation.md](https://github.com/D-sorganization/openflight_development/blob/main/validation/mlm2pro-cross-validation.md).

The MLM2 Pro radar likely operates in the same K-band neighborhood as the OPS243 (24.125 GHz CW). Interference is an open question to TEST, not assume away. (IWR6843 is 60 GHz - unaffected.)

Protocol:
- [ ] A: 10 shots OpenFlight only - record spin read rate, spin_snr, ball-speed spread
- [ ] B: 10 shots MLM2 Pro only - confirm normal behavior
- [ ] AB: 10 shots both running - compare OpenFlight spin_snr / read rate / trigger behavior vs A, and MLM2 readings vs B
- [ ] If degraded: try lateral separation, then alternating-shot capture as fallback
- [ ] Write up result in notes/ - publishable upstream (other MLM2 Pro owners will ask)

</details>

<details>
<summary><b>D12 — First full paired validation session (driver/7i/wedge, RPT balls)</b></summary>

> Archived from closed issue #12 · labels: `validation`

From [validation/mlm2pro-cross-validation.md](https://github.com/D-sorganization/openflight_development/blob/main/validation/mlm2pro-cross-validation.md). Prereqs: build at M2, interference check done, adapter script working.

- [ ] Session header: date, location, net distance, full OpenFlight geometry flags, commit SHA, MLM2 app version, ball type per block
- [ ] Run with `--debug --session-location mlm2-validation`
- [ ] Blocks: driver 10-15 (RPT), 7i 10-15 (RPT), PW/SW 10-15 (RPT), optional 5-10 range balls
- [ ] Select matching club in UI per block; log shot order
- [ ] Export MLM2 CSV; pair by sequence + timestamp; count device-only shots (detection-rate asymmetry is a finding)
- [ ] Report: detection rate, ball-speed bias/std, launch V/H bias/RMSE split by angle_source, spin read rate + accepted-delta + rejection histogram, club speed (with MLM2 caveat), carry labeled model-vs-model
- [ ] Autopsy the 2-3 worst disagreements via JSONL diagnostics and .l3dump replay

Driver block matters most upstream: the IWR6843 driver ghost-track problem (3.55 deg MAE, +3.39 deg bias in the July field report) needs driver truth data.

</details>

<details>
<summary><b>D21 — Truth-data program: driver ghost-track gate dataset for upstream</b></summary>

> Archived from closed issue #21 · labels: `validation`, `upstream`

**Tier 2 - the unique-value contribution** ([contribution opportunities](https://github.com/D-sorganization/openflight_development/blob/main/project-reviews/2026-07-30-contribution-opportunities.md) item 5).

Upstream's driver accuracy is their weak point: 3.55 deg MAE, +3.39 deg bias, dominated by false-accepted slow "ghost" tracks (TI locked onto 55-57 mph movers while OPS measured 152-158 mph balls). Their roadmap fix - reject TI tracks below ~65-70% of OPS ball speed, then OPS-guided fast-track recovery (offline replay recovered 3 of 4 bad driver shots at ~2.6 deg MAE) - explicitly "needs more truth data before shipping."

- [ ] After M2+M3 prereqs: dedicated driver blocks (10-15 shots, RPT balls) in every paired MLM2 session
- [ ] Log with `--debug` so .l3dump captures replay offline (`scripts/iwr6843/replay.py`)
- [ ] Deliver paired dataset + replay results to upstream (issue first, offer the data)
- [ ] Also feeds: two-dot relaxed-confidence thresholds, the 8-deg agreement gate, select-vs-average - all "deferred pending a session paired with a reference instrument"

</details>

---

## What was deliberately not carried forward

- **The milestones themselves.** `M1`, `M2` and `M3` were closed along with the
  issues. The three epics above replace them as prose.
- **Issue #11** (MLM2 Pro CSV adapter for `compare_trackman.py`) — completed and
  closed on its own merits before this archive; the script exists. Upstreaming it as
  `--source mlm2pro` support is carried in
  [`upstream-contribution-queue.md`](upstream-contribution-queue.md).
- **Issue #3** (verify the IWR6843 order is the LEVM variant) — resolved 2026-07;
  Digi-Key 296-IWR6843LEVM-ND is the correct variant. The on-arrival silkscreen
  check survives inside `D8`.

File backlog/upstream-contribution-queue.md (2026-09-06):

# Upstream Contribution Queue — Draft

**Archived:** 2026-09-06 · **Draft only — not filed, not tracked.**
**Verified against** `open-flight/openflight` `main` = **`5dd0d0b`** (2026-09-02), fetched 2026-09-06.

Software work that belongs to [`open-flight/openflight`](https://github.com/open-flight/openflight),
not to this repository. Nothing here is filed anywhere yet — filing it means opening
an issue or PR **on the upstream repo**.

---

## First, the thing this archive exists to fix

This repository is **not a GitHub fork**. It was seeded by copying upstream's tree,
so there is **no merge base** — `git merge-base upstream/main HEAD` returns nothing.
Git cannot rebase, cherry-pick or three-way-merge anything between the two.

Since that copy, the two trees have gone in different directions:

| | This repo | Upstream `5dd0d0b` |
|---|---|---|
| Commits the other side does not have | 24 | 1,182 |
| `src/openflight/server` | 8-module package, 4,687 lines | single `server.py`, **5,964 lines** |
| `AppState` | present (`server/state.py`) | 0 occurrences |
| `club_data.py` | present | absent |
| CI toolchain | `uv` + ruff + vitest | `pip`, no ruff job |

Nine of the 24 local commits are real source changes to the mirrored tree, made
here instead of upstream. That is the drift, stated plainly: roughly nine PRs of
software work living in a snapshot that upstream has since moved 1,182 commits
past, in a repo with no ancestry link to rebase across.

**The rule going forward:** clone `open-flight/openflight` fresh, branch from *its*
`main`, and open the PR there. Do not develop against the snapshot in this repo.

## Disposition of the nine local source PRs

Re-checked against upstream `5dd0d0b` today. "Rebuild" means the change is still
wanted but must be re-authored against current upstream — the local diff will not
apply.

| Local PR | What it did | Upstream today | Disposition |
|---|---|---|---|
| [#35](https://github.com/D-sorganization/openflight_development/pull/35) | Windows test fixes (CRLF, platform skips) | `test_compare_trackman.py:159,178` already carry `newline=""`; `test_start_kiosk.py` guarded by PR #171 | **Mostly landed independently.** Only the `test_cloud_config` 0600 and `test_serial_latency` udev skips may remain — verify, then a tiny PR. |
| [#36](https://github.com/D-sorganization/openflight_development/pull/36) | Docs-drift fixes | `CLAUDE.md:204` now reads "Min ball speed: 15 mph"; the CFAR-SNR and shot-timeout lines are gone | **Superseded.** Re-diff before claiming any remaining drift. |
| [#37](https://github.com/D-sorganization/openflight_development/pull/37) | CI → `uv`, add ruff/vitest | upstream workflows are still `anti-slop`, `pr-checks`, `pylint`, `pytest`, `ui-build`; no `uv`, no ruff job | **Rebuild and offer.** Mechanical, high acceptance odds, closes the local-vs-CI gap that violates upstream's own rule #1. |
| [#38](https://github.com/D-sorganization/openflight_development/pull/38) | `club_data.py` consolidation | no `club_data.py` upstream | **Rebuild — highest priority.** This is a *correctness* fix dressed as a refactor: the smash/launch/spin tables were numerically diverged (DRIVER 1.48 vs 1.45, WOOD_7 1.42 vs 1.41 vs 1.40). Propose in an issue first, then PR with cross-consistency tests. |
| [#39](https://github.com/D-sorganization/openflight_development/pull/39) | MLM2 Pro CSV adapter | absent upstream | **Rebuild and offer** as `--source mlm2pro` for `compare_trackman.py` plus `docs/mlm2pro-test-process.md`. Gives every MLM2-owning builder a validation path, which multiplies upstream's truth-data supply beyond one person. |
| [#40](https://github.com/D-sorganization/openflight_development/pull/40) | `AppState` + K-LD7 orientation dedup | 0 `AppState`; `server.py` grew 3,755 → 5,964 lines | **Do not cold-PR.** See U7 below. |
| [#41](https://github.com/D-sorganization/openflight_development/pull/41) | IWR6843 accuracy write-up for Discussion #161 | n/a — this is prose | **Blocked on data**, not on code. See U9. |
| [#45](https://github.com/D-sorganization/openflight_development/pull/45) | Replace unsafe `pickle`, convert server to logging | `server.py` has 0 `pickle`, but ~10 `scripts/analysis/*` files still load pickles; 1,623 `print(` calls remain across 69 files in `src` + `scripts` | **Split and rebuild.** The pickle-load hardening in the analysis scripts is a defensible standalone security PR. The print→logging sweep is too large to land as one change. |
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

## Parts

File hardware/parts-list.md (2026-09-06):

# OpenFlight Build — Parts List & Procurement Status

**Date:** 2026-07-30
**Sources:** upstream [docs/PARTS.md](https://github.com/jewbetcha/openflight/blob/main/docs/PARTS.md), [IWR6843 Operator Guide](https://github.com/jewbetcha/openflight/blob/main/docs/iwr6843/README.md), [sound-trigger wiring guide](https://github.com/jewbetcha/openflight/blob/main/docs/sound-trigger-wiring.md), `cad/IARC_case/`.

Target build: **current-generation stack** — OPS243 (speed/spin) + IWR6843LEVM (angles/club path) + SEN-14262 sound trigger on a Raspberry Pi 5. The K-LD7 path is deprecated upstream; do not buy K-LD7 hardware.

## Already have

| Item | Qty | Notes / action needed |
|---|-----|---|
| OPS243 Doppler radar | 2 | ⚠️ **Verify variant.** Upstream requires the standard USB **OPS243** (57600 baud CDC-ACM). The **OPS243-A-W (WiFi)** locks serial to 19200 baud — too slow for I/Q transfer; PARTS.md calls it incompatible, and the IWR guide only allows it via a powered USB hub (Layout B) with degraded assumptions. Check the board for the WiFi module / "-W" marking. Two non-WiFi units = one for the build + one bench/dev unit (very useful for replay + driver work without touching the build). |
| SparkFun SEN-14262 sound detector | 1 | Needs the **R17 gain-mod resistor soldered** before use (see consumables below). |
| Rapsodo MLM2 Pro | 1 | Reference instrument for validation — not part of the build. Needs RPT balls for measured (not estimated) spin. |

## On order

| Item | Qty | Notes / action needed |
|---|-----|---|
| TI IWR6843LEVM mmWave radar | 1 | ✅ **Variant confirmed 2026-07-31:** Digi-Key **296-IWR6843LEVM-ND**, MFG Texas Instruments **IWR6843LEVM** — exactly the board upstream targets (~$150, 60 GHz, 3 TX × 4 RX, CP2105 dual-UART USB bridge; firmware image, `.cfg`, S1 flash procedure, and enclosure geometry are all LEVM-specific). On arrival: verify silkscreen, identify USB connector type (data-capable cable), confirm S1 boot switch + RESET access — see draft `D8` in [`backlog/draft-epics.md`](../backlog/draft-epics.md). |

## Need to buy — core (blocks the build)

| # | Item | Spec | Ref price | Why |
|---|---|---|---|-----|
| 1 | Raspberry Pi 5 | 4 GB+ RAM (8 GB is fine) | ~$130 | Main compute. Upstream setup targets Pi 5 explicitly (UART0 on `/dev/ttyAMA0`, lgpio pin factory). |
| 2 | 7" touchscreen | Either HMTECH 7" 1024×600 IPS (HDMI/USB, ~$46) **or** Raspberry Pi Touch Display 2 (DSI, ~$60) | ~$46–60 | Kiosk UI. Note: the IARC case has dedicated STLs for each display — pick the display **before** printing the case (`monitor_shell.stl` vs `Touch_Display2_*.stl`). |
| 3 | 27 W USB-C power supply | Official Pi 5 PSU, 5V/5A | ~$14 | Pi 5 + two radars is power-hungry; don't cheap out here. Upstream: treat intermittent USB disconnects as power problems first. |
| 4 | microSD card | 32 GB+ Class 10 / A2 | ~$10 | Pi OS (64-bit). Debug-mode IWR dumps are ~550 KB/shot — 64 GB is cheap insurance for long sessions. |
| 5 | USB-A → micro-USB cable | Data-capable | ~$5 | OPS243 connection (initial USB phase, and permanently if using Layout B). |
| 6 | USB cable for IWR6843LEVM | **Data-capable** (charge-only cables won't enumerate); check the connector on the board revision when it arrives | ~$5 | CP2105 serial bridge → Pi. |
| 7 | Dupont jumper wires, F-F | Assorted pack (need ≥8: 3× sound trigger, 4× OPS UART migration, 1× GATE→BCM17) | ~$7 | Sound trigger wiring + OPS GPIO-UART migration (Layout A). |
| 8 | Resistors, through-hole | **47 kΩ** (start) and **33 kΩ** (backup, noisy environments) | ~$2 | R17 gain mod on SEN-14262 — mandatory at 3.3 V or GATE sticks high. |

**Core subtotal: ~$220–235**

## Need to buy — conditional

| # | Item | Condition | Ref price |
|---|---|---|---|
| 9 | Powered USB hub (own external supply, e.g. Acer 4-port) | **Only if** an OPS turns out to be the WiFi variant, or you choose Layout B (both radars on USB) instead of the validated Layout A (OPS on GPIO UART). The Pi cannot power both radars over USB alone. | ~$20 |

## Need to buy / make — recommended extras

| # | Item | Why | Ref price |
|---|---|-----|---|
| 10 | 3D-printed IARC case v3 | `cad/IARC_case/` has the full STL/3MF set (monitor shell, OPS mount, sensor housing, feet). No printer → print service or a friend. ⚠️ **Gap:** the IARC case predates the IWR6843 — it has K-LD7 mounts but **no IWR6843LEVM mount** in `cad/IARC_case/stl/`. Check upstream for a newer mount; otherwise this is a contribution opportunity (design one). The IWR guide says the validated enclosure holds the board rotated so the vertical virtual array is physically vertical — replicate that constraint in any DIY mount. | ~$15 filament |
| 11 | Tripod / mount, 1/4"-20 | Positioning behind the tee (3–5 ft). A rigid mount matters: "small mechanical shifts can appear as angle bias." | ~$10 |
| 12 | Digital inclinometer or phone app | Measuring `--iwr6843-tilt-deg` (antenna-face tilt). Upstream is emphatic: **set tilt by physical measurement**, the calibration sweep cannot recommend one. A phone clinometer app on a flat reference surface works. | $0–15 |
| 13 | Tape measure (metric) | All IWR geometry flags are in meters (tee slant distance, net distance, radar height, ball height). Wrong values silently bias launch angle. | have? |
| 14 | Soldering iron + solder + heat-shrink | R17 resistor mod; the GATE three-way splice (detector GATE → OPS HOST_INT + Pi BCM17) must be soldered/secure, not twisted wires. A lever/Wago 3-way connector is an acceptable alternative for the splice. | tool |
| 15 | Callaway Chrome Soft X **RPT balls** (3+) | MLM2 Pro only *measures* spin with RPT-marked balls; otherwise it estimates. Without them the validation of OpenFlight's hardest metric (spin) has no ground truth. | ~$25/3-pack |
| 16 | Corner reflector (DIY foil or small trihedral) | Optional: verifies IWR horizontal aim on the target line during setup. | ~$0 DIY |
| 17 | Hitting net + mat | Presumably already owned with the MLM2 Pro. Remember: net distance is a measured input (`--iwr6843-net-m`), and ball height off mat (0.021 m) vs tee (0.040 m) ≈ 0.8° of launch angle. | have? |

## Explicitly do NOT buy

- **K-LD7 radars / FTDI adapters** — deprecated upstream, no further development.
- **OPS243-A-W (WiFi)** — incompatible baud rate for I/Q.
- **K-LD7 EVAL boards** — never needed even for legacy builds.
- **TI toolchain / UniFlash requirements** — the prebuilt firmware image flashes from the Pi via the checked-in `firmware/flash_iwr6843.py`; UniFlash is only a fallback.
- **DCA1000EVM / MMWAVEICBOOST carrier boards** — the LEVM's own CP2105 USB serial is the supported data path (verify against upstream docs when the board arrives; the operator guide references only the LEVM + USB).

## Ball-marking note (spin vs angles trade-off)

Upstream README: reflective stickers/dots improve angle-radar returns but wreck radar spin detection (specular pulse ≠ seam modulation); a thin painted stripe is the compromise. For validation sessions, decide per-session what's being validated — use RPT balls (MLM2 spin truth) with no extra reflective patches when validating OpenFlight spin.

## Budget summary

| Bucket | Est. cost |
|---|---|
| Core remaining (items 1–8) | ~$220–235 |
| Conditional hub (item 9) | $0–20 |
| Extras (case, mount, RPT balls, misc) | ~$50–65 |
| **Total remaining spend** | **~$270–320** |
| Already sunk (2× OPS243, SEN-14262, IWR6843 on order) | ~$650 |

## Open verification tasks (tracked as issues)

1. Inspect both OPS243 units — confirm neither is the `-W` WiFi variant; label them A (build) and B (bench).
2. ~~Confirm the IWR6843 order line-item is **IWR6843LEVM**.~~ ✅ Done 2026-07-31 — Digi-Key 296-IWR6843LEVM-ND confirmed.
3. When the LEVM arrives: identify its USB connector type, buy the matching data cable if not on hand.
4. Decide display (HMTECH vs Touch Display 2) before printing case parts.
5. Check upstream `cad/` and issues for an IWR6843 case mount; if absent, plan to design one.

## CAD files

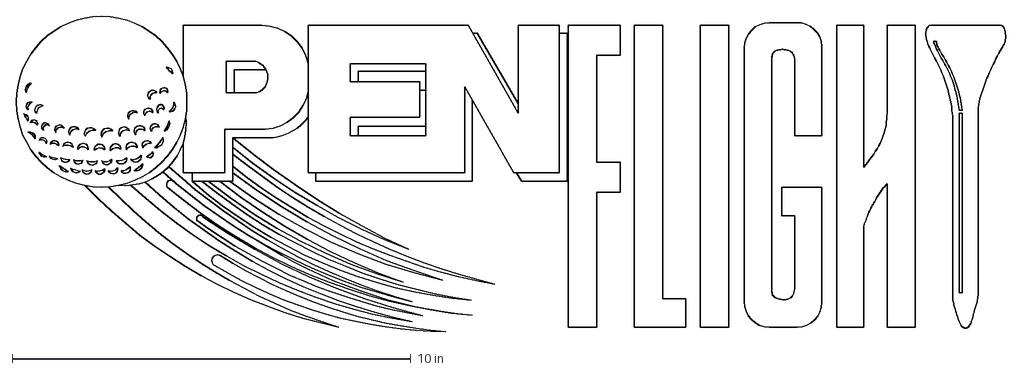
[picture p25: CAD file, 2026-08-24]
cad/logo/MainLogo.DXF
24.8 x 7.90 in

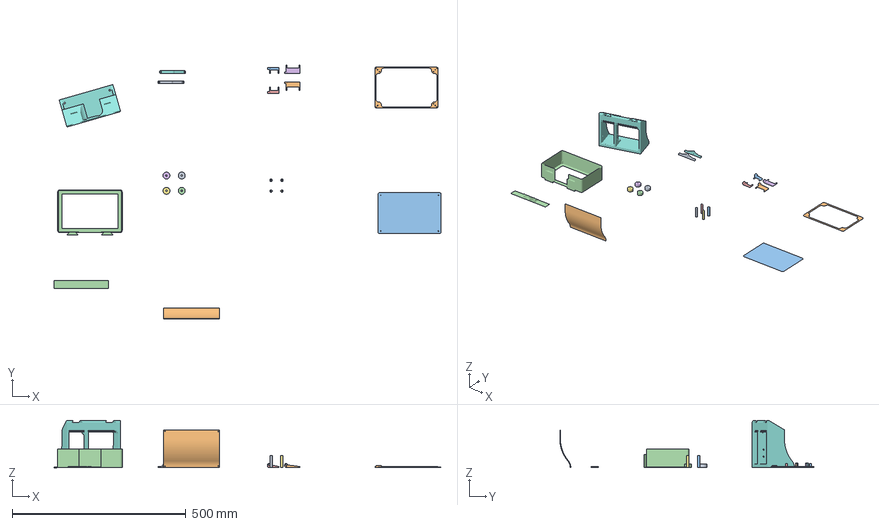
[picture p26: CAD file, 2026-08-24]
cad/IARC_case/IARC_Case_v3.3mf
1113.5 x 732.3 x 136.2 mm
case_foot.stl x 4
curvy_backplate.stl
monitor_standoffs.stl x 4
monitor_shell.stl
KLD7_v_mount_L_v2.stl
sensor_housing.stl
KLD7_v_mount_R_v2.stl
KLD7_h_mount_L_v2.stl
KLD7_h_mount_R_v2.stl
OPS_mount.stl x 2
monitor_mount.stl
monitor_back.stl
name_plate.stl

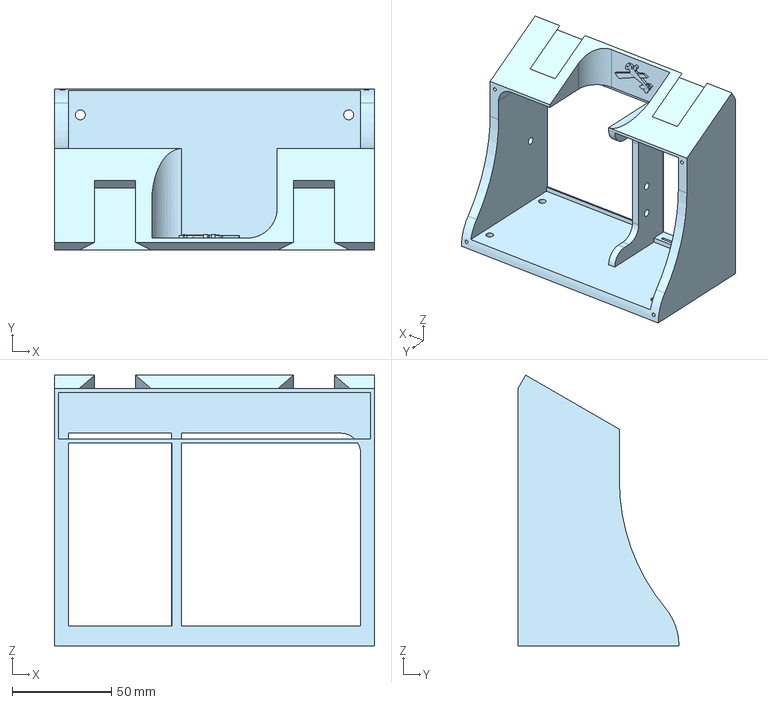
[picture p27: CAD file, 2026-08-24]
cad/IARC_case/step/sensor_housing.step
161.0 x 81.0 x 136.2 mm

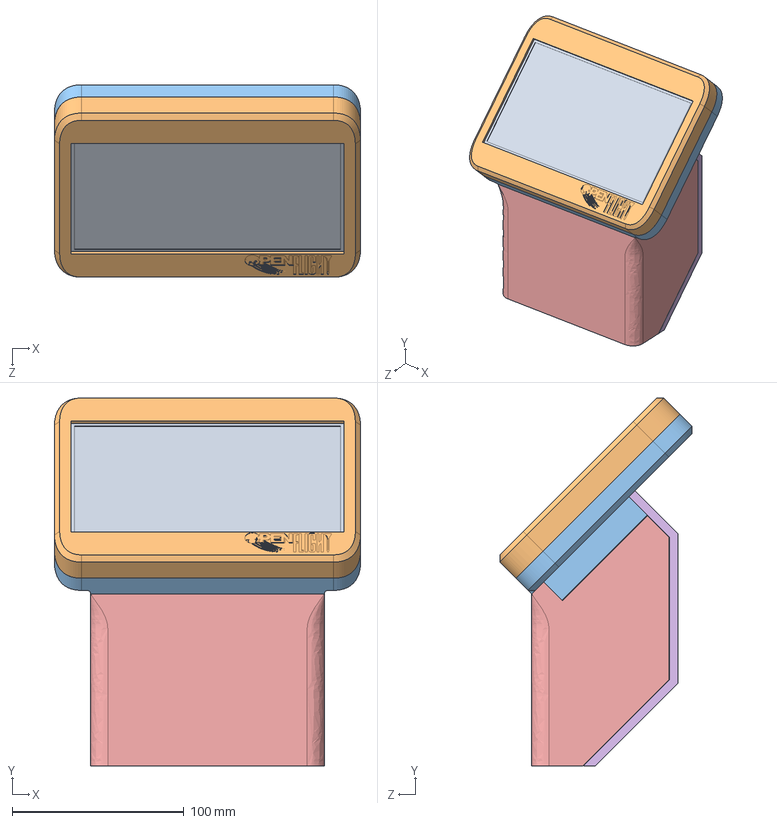
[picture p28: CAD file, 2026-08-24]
cad/LordFarq/OpenFlight_LF.STEP
178.0 x 214.0 x 111.9 mm
Screen
ScreenBezelFront
RearScreen
OPS243
BaseFront
BaseRear

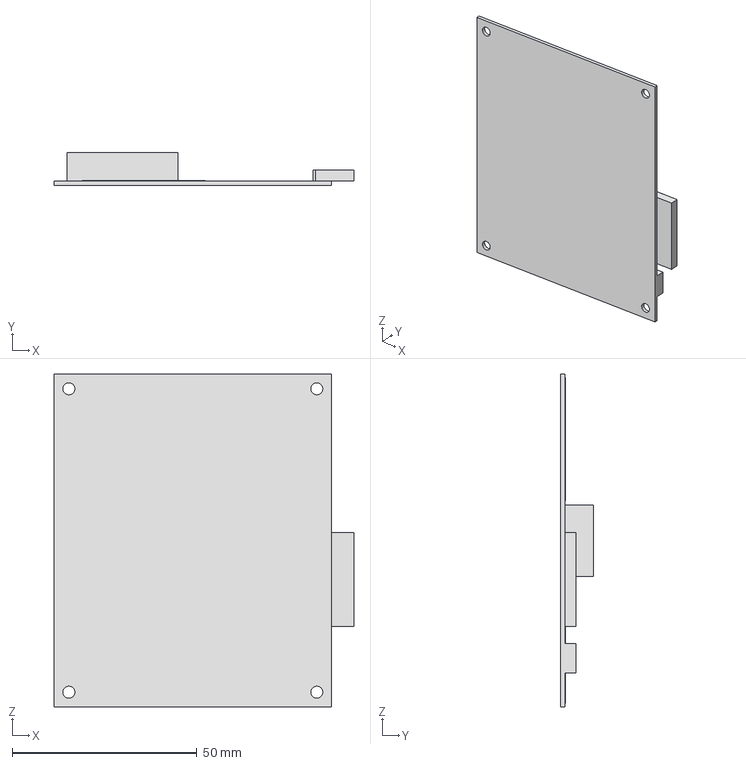
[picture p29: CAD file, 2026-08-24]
cad/OPS243.stp
81.0 x 8.83 x 90.0 mm

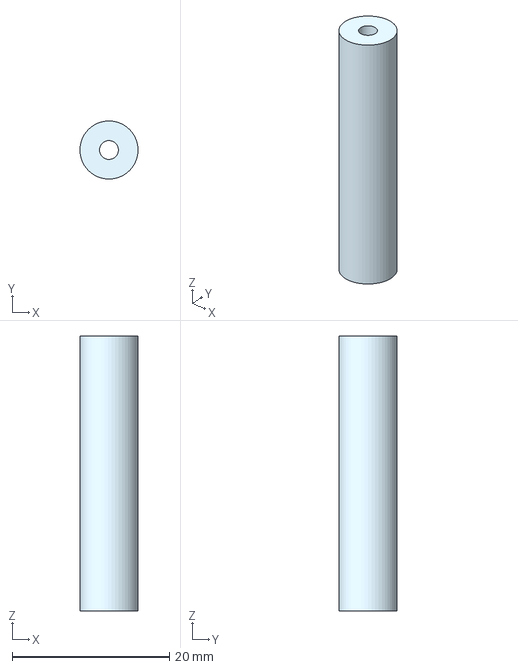
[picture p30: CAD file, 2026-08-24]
cad/IARC_case/step/monitor_standoffs.step
7.39 x 7.40 x 35.0 mm

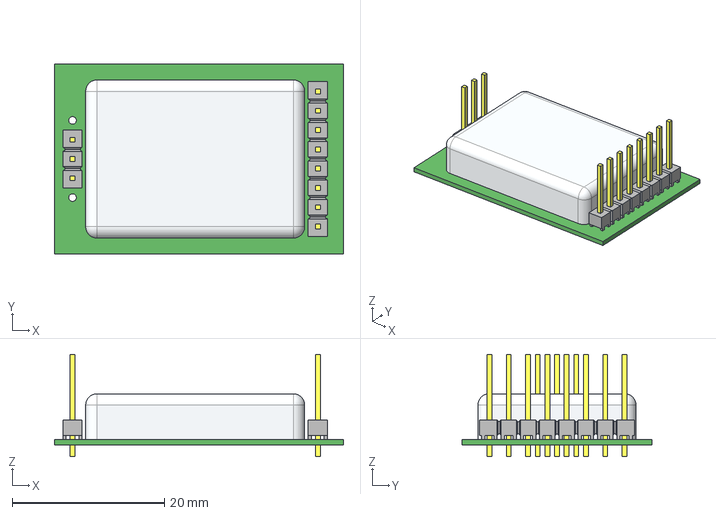
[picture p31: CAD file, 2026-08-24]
cad/K-LD7-RFB.step
38.0 x 25.0 x 13.5 mm

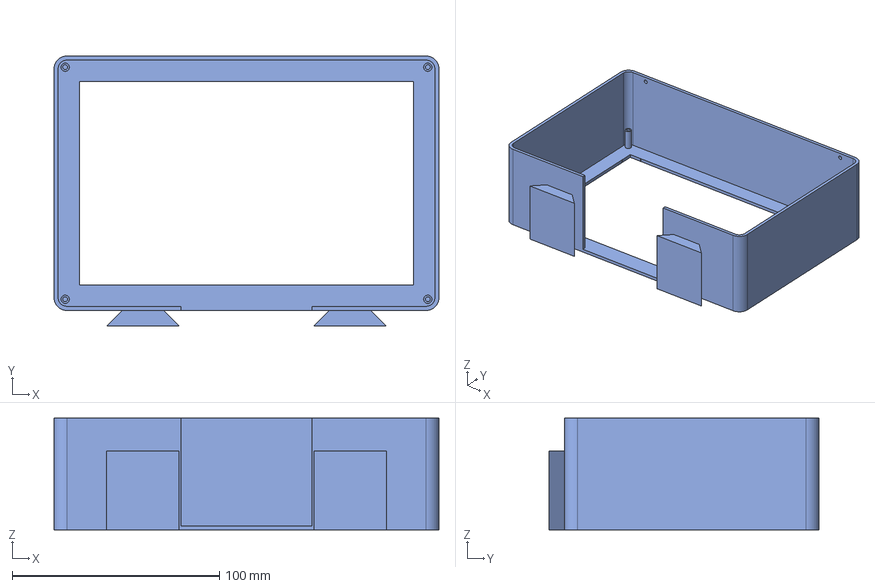
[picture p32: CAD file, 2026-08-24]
cad/IARC_case/step/monitor_shell.step
185.8 x 130.3 x 54.0 mm

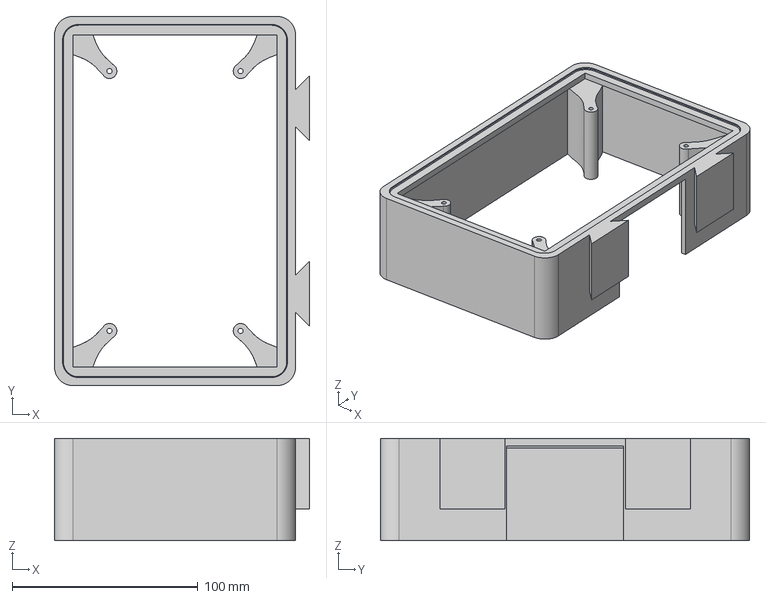
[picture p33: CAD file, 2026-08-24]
cad/IARC_case/step/Touch_Display2_shell.step
137.4 x 199.0 x 55.0 mm

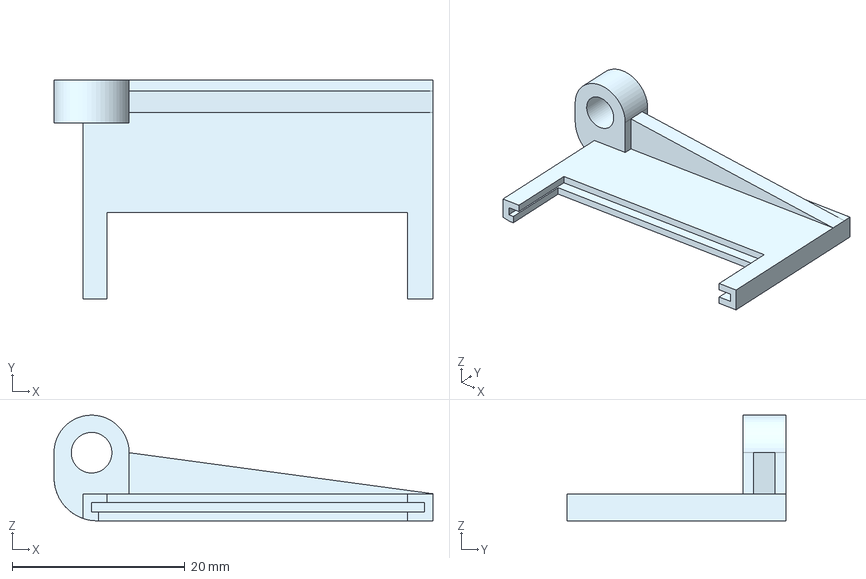
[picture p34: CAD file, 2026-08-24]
cad/IARC_case/step/KLD7_v_mount_R_v2.step
43.8 x 25.3 x 12.2 mm

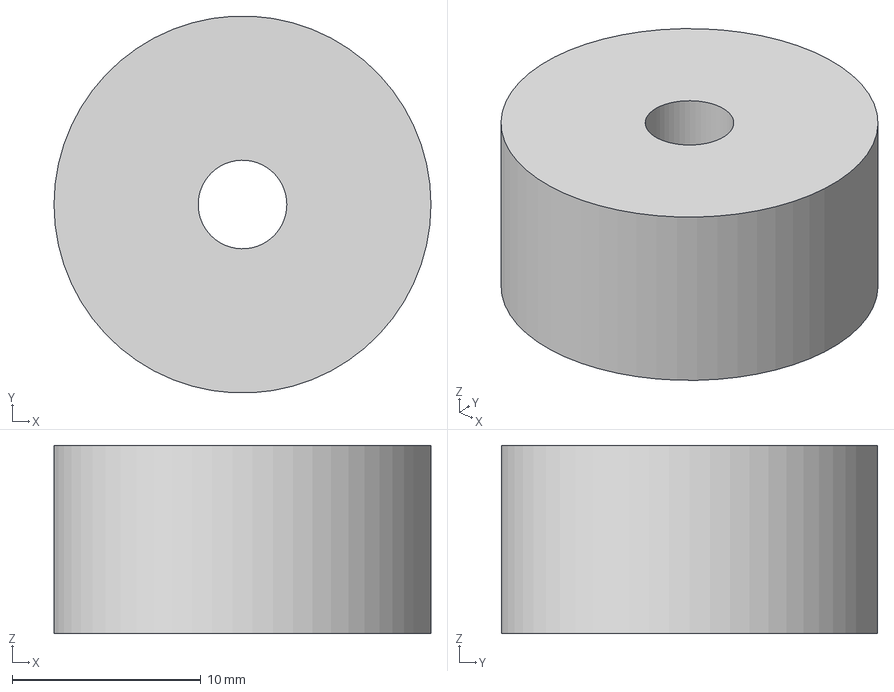
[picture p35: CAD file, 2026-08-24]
cad/IARC_case/step/case_foot.step
20.0 x 20.0 x 10.0 mm

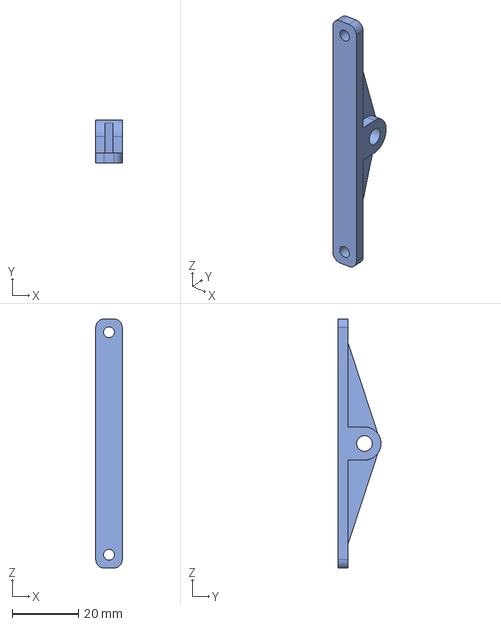
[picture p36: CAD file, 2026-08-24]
cad/IARC_case/step/OPS_mount.step
8.00 x 13.0 x 75.0 mm

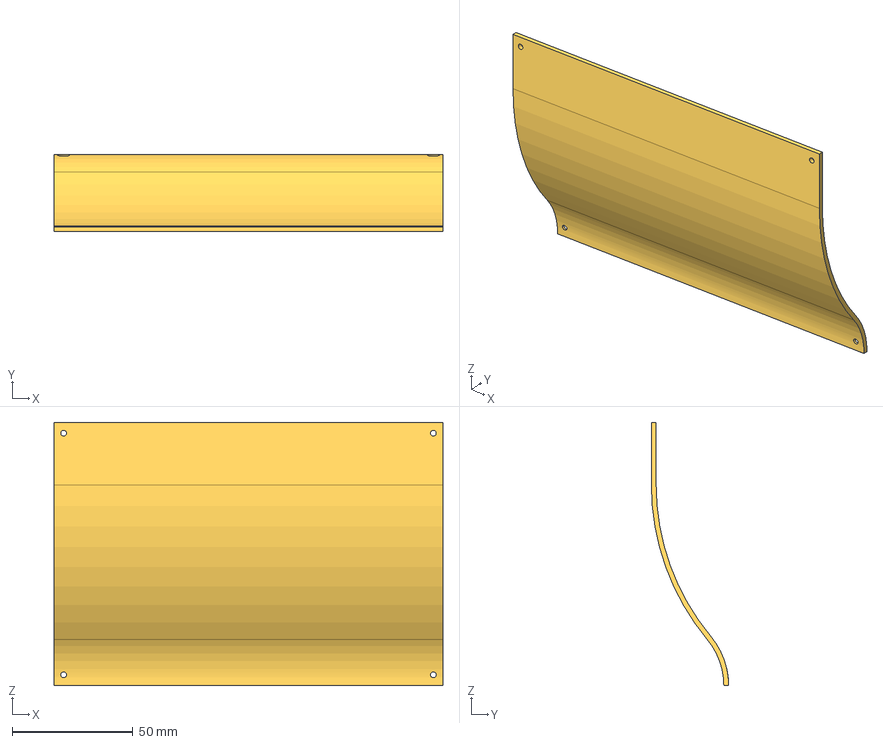
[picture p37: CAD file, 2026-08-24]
cad/IARC_case/step/curvy_backplate.step
161.0 x 32.0 x 109.0 mm

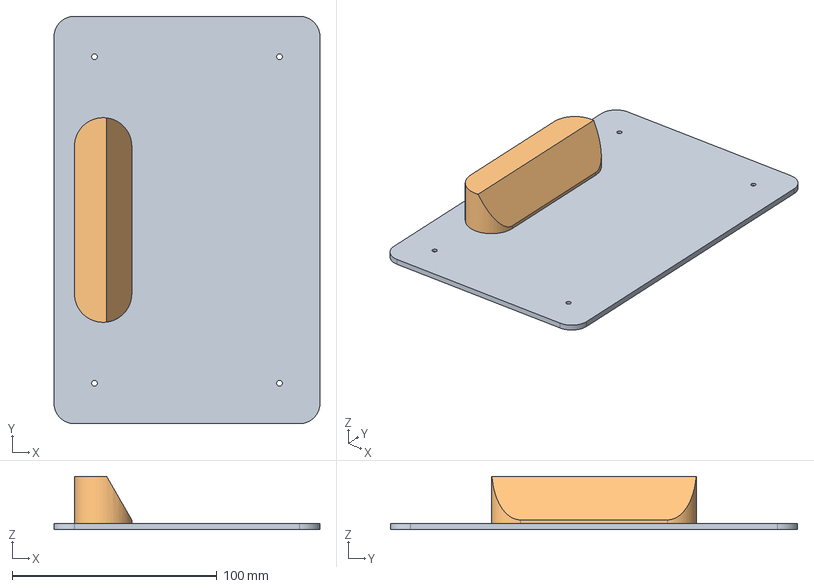
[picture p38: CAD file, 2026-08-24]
cad/IARC_case/step/Touch_Display2_backplate.step
129.9 x 199.0 x 26.0 mm

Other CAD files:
cad/IARC_case/step/KLD7_v_mount_L_v2.step
cad/IARC_case/step/monitor_back.step
cad/IARC_case/step/monitor_mount.step
cad/IARC_case/step/name_plate.step
cad/IARC_case/step/KLD7_h_mount_L_v2.step
cad/IARC_case/step/KLD7_h_mount_R_v2.step
cad/IARC_case/stl/KLD7_h_mount_L_v2.stl
cad/IARC_case/stl/KLD7_h_mount_R_v2.stl
cad/IARC_case/stl/KLD7_v_mount_L_v2.stl
cad/IARC_case/stl/KLD7_v_mount_R_v2.stl
cad/IARC_case/stl/OPS_mount.stl
cad/IARC_case/stl/Touch_Display2_backplate.stl
cad/IARC_case/stl/Touch_Display2_shell.stl
cad/IARC_case/stl/case_foot.stl
cad/IARC_case/stl/curvy_backplate.stl
cad/IARC_case/stl/monitor_back.stl
cad/IARC_case/stl/monitor_mount.stl
cad/IARC_case/stl/monitor_shell.stl
cad/IARC_case/stl/monitor_standoffs.stl
cad/IARC_case/stl/name_plate.stl
cad/IARC_case/stl/sensor_housing.stl

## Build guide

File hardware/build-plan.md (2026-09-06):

# OpenFlight Build Plan — Phased Bring-Up

**Date:** 2026-07-30
**Principle (from upstream docs):** change one thing at a time and validate it before the next step — "doing both at once makes any failure ambiguous." Every phase below ends with a **gate**: a concrete command whose output proves the phase worked. Don't advance on a red gate.

This repo does not carry a GitHub issue tracker. The phases below are preserved
as draft issues in [`backlog/draft-epics.md`](../backlog/draft-epics.md); this
document remains the authoritative version. Software contributions go upstream to
[`open-flight/openflight`](https://github.com/open-flight/openflight) — see
[`backlog/README.md`](../backlog/README.md).

## Phase 0 — Bench prep (no Pi required, can start today)

- [ ] Inspect both OPS243 boards: confirm non-WiFi variant, note firmware/serial numbers, label **A** (build unit) and **B** (bench unit).
- [ ] Solder the R17 resistor (47 kΩ) on the SEN-14262. Visual gate: LED flashes on clap, does **not** stay lit. If stuck high → swap to 33 kΩ.
- [ ] Optional Windows bench check: `uv run python scripts/hardware-test/test_rolling_buffer_persist.py --setup` against a COM port if the script accepts a port override — otherwise defer OPS flash setup to Phase 2 on the Pi. (Repo targets Linux/macOS; treat Windows as read-only dev, not hardware host.)
- [ ] Read: `docs/sound-trigger-wiring.md`, `docs/PARTS.md`, `docs/iwr6843/README.md`, `docs/ops243-uart-migration.md` end-to-end.

## Phase 1 — Pi base system

- [ ] Flash Raspberry Pi OS 64-bit; boot; network up.
- [ ] `git clone https://github.com/open-flight/openflight.git && cd openflight && ./scripts/setup/setup.sh` (interactive; handles uv, deps, UI build, one-time hardware config prompts, auto-start).
- [ ] Display working (HMTECH via HDMI/USB touch, or Touch Display 2 via DSI).
- **Gate:** `scripts/start-kiosk.sh --mock` → UI at `http://localhost:8080` shows simulated shots.

## Phase 2 — OPS243 over USB (speed only, no trigger yet)

- [ ] Connect OPS243-A (unit A) via USB.
- [ ] One-time flash config: `uv run python scripts/hardware-test/test_rolling_buffer_persist.py --setup` → power-cycle radar (unplug, 3 s, replug) → `--test`.
- **Gate:** `--test` passes (rolling buffer persists across power cycle; HOST_INT trigger mode armed from flash).

## Phase 3 — Sound trigger

- [ ] Wire per `docs/sound-trigger-wiring.md`: SEN-14262 VCC→Pi 3.3V (pin 1), GND→Pi GND (pin 6), GATE→OPS J3 pin 3 (HOST_INT); OPS J3 pin 10 → Pi GND (shared ground). J3 pin 1 is at the **right** end of the header — confirm silkscreen, don't infer.
- [ ] `uv run python scripts/hardware-test/test_sound_trigger_hardware.py` → clap → "TRIGGER RECEIVED", 4096 I/Q samples.
- [ ] Full diagnostic: `uv run python scripts/hardware-test/diagnose.py` (checks 1–3 and 6 apply; K-LD7 checks skip).
- **Gate:** clap-triggered captures are reliable; then hit real balls → plausible ball speed, club speed, smash in UI. Log a session and skim the JSONL (`shot_detected`, `rolling_buffer_capture`, `trigger_diagnostic` rows).

**Milestone: working speed/spin launch monitor (~$400 configuration).** Useful immediately, and the MLM2 Pro can already cross-check ball speed from here.

## Phase 4 — OPS243 to GPIO UART (Layout A prerequisite for the IWR6843)

The Pi can't power both radars over USB; the validated layout moves the OPS to the GPIO header.

- [ ] Follow `docs/ops243-uart-migration.md`: OPS 5V (J3-9)→Pi pin 2/4, GND (J3-10)→Pi GND, OPS TxD (J3-7)→Pi RXD0 (pin 10), OPS RxD (J3-6)→Pi TXD0 (pin 8). TX/RX crossed.
- [ ] `raspi-config`: disable serial login shell, enable serial hardware, reboot. On Pi 5 the header UART is **`/dev/ttyAMA0`** (do NOT use `/dev/serial0` → that's the debug header).
- [ ] User in `dialout` + `gpio` groups.
- **Gate:** OPS works exactly as in Phase 3 but on `--radar-port /dev/ttyAMA0` (or `--ops-port`) — sound trigger still fires, speeds still read. Validate this alone **before** the TI board is connected.

## Phase 5 — IWR6843LEVM bring-up (when it arrives)

- [ ] Verify board variant + connector; verify checked-in firmware hash: `sha256sum firmware/releases/l3_dump_vTX2_hwa_window53_12loops_18frames_4ms_v2.bin` → `3045bb2f…e7fcb`.
- [ ] Identify CP2105 **Enhanced/UARTA** interface (usually `/dev/ttyUSB0`, by-id `…if00-port0`) — not the Standard interface.
- [ ] Flash mode (S1.1 ON, S1.2 OFF, S1.3 ON, S1.4 ON, S1.5 OFF) → `uv run python firmware/flash_iwr6843.py --probe --port /dev/ttyUSB0` → then flash the release image → functional mode (S1.1 OFF …) → RESET.
- [ ] Extend the GATE splice three ways: detector GATE → OPS HOST_INT **and** Pi BCM17 (pin 11). Soldered or lever-connector splice, not twisted wire.
- [ ] Mount behind ball, antenna face down the target line, board rotated so the vertical virtual array is vertical (TX above RX). Start ~6" (0.152 m) antenna-center height, ~10° tilt as a starting point.
- [ ] Measure geometry honestly (antenna center, common floor reference): tee slant m, net m, tilt deg (inclinometer!), radar height m, ball height m (0.021 mat / 0.040 tee).
- [ ] First run with `--debug` and explicit ports/config/geometry (see operator guide's example command).
- **Gate 1 (trigger/dump):** clap → `[IWR6843] Capture #N complete: 549542 bytes`, `rejected_by_ball_tracker` (expected for claps), firmware health `active=1 … rf_faults=0`.
- **Gate 2 (real shots):** hit balls → session shows `Angle source: radar` on trusted shots; `iwr6843_capture` entries carry `capture_path` in debug mode.
- [ ] Calibration session: `scripts/iwr6843/calibrate.py --shots 20 --club 7i …` (stop the kiosk first — it owns BCM17). Set tilt by **physical measurement**; ignore edge-of-sweep tilt candidates (known-unreliable, monotonic objective).
- [ ] If measuring club path: measure boresight-to-target-line angle and pass `--iwr6843-azimuth-offset-deg` (not optional trim — absorbs the shipped array-calibration phase offset). Right-handed only. Run the 3-session separation test (`scripts/iwr6843/club_path_report.py`).

## Phase 6 — Enclosure & permanent mounting

- [ ] Print IARC case v3 parts for the chosen display; assemble (Pi, OPS mount, sensor housing, display shell).
- [ ] Solve the IWR6843 mount (no STL in the IARC set — check upstream first; else design one honoring board rotation + antenna clearance). Candidate upstream contribution.
- [ ] Re-measure ALL geometry after enclosure/mount changes (mounting shifts = angle bias), and re-run a short calibration session.

## Phase 7 — Cross-validation & ongoing development

- [ ] Run the MLM2 Pro protocol in [validation/mlm2pro-cross-validation.md](../validation/mlm2pro-cross-validation.md).
- [ ] Feed findings into upstream issues/PRs (see project-reviews/ for the opportunity list).
- Bench unit B + saved `--debug` sessions enable offline work: `scripts/iwr6843/replay.py` (angle estimator), `scripts/analysis/replay_spin_dechirp.py` (next-gen spin), `compare_trackman.py` (comparison tooling).

## Standing rules learned from upstream docs

- Power problems masquerade as everything — intermittent USB disconnects / dual-radar failures → check power first.
- Never trust a geometry number you didn't measure *after* the last time anything moved.
- A clap is a trigger test, not a shot test; `rejected_by_ball_tracker` on claps is success.
- Session JSONLs + `--debug` dumps are the raw material for all offline analysis — hoard them, and keep notes (club, geometry, intent) per session; they're worthless without setup metadata.

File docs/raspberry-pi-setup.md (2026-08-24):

# Raspberry Pi Setup Guide

Complete guide for setting up OpenFlight on a Raspberry Pi 5 with the 7" touchscreen display.

## Prerequisites

Make sure you have all the hardware. See the **[Parts List](PARTS.md)** for what to buy.

**Required:**
- Raspberry Pi 5 (4GB+ recommended)
- 7" Touchscreen Display
- MicroSD Card (32GB+)
- 27W USB-C Power Supply (official Pi 5 PSU recommended)
- OPS243-A Doppler Radar + USB cable
- SparkFun SEN-14262 sound detector (wired per the [Sound Trigger Wiring Guide](sound-trigger-wiring.md))

**Optional:**
- TI IWR6843LEVM + data cable — measured launch angle and experimental club path; see the [IWR6843 Operator Guide](iwr6843/README.md)
- Geekworm X1202 or X1206 UPS HAT — portable Pi 5 power using four separately purchased 18650 or 21700 cells; see the [battery monitoring overview](battery/README.md) and [Geekworm operator guide](battery/geekworm.md)
- InnoMaker OV9281 global-shutter camera (~$30) — experimental vision work; see [Camera and YOLO Experiments](yolo-performance-tuning.md)

**Optional (deprecated):**
- K-LD7 + FTDI adapter (×2) — for launch angle and club path (see [Parts List](PARTS.md)). **Deprecated** — superseded by a more capable radar chip; don't buy for a new build. Supported for existing builds only.

## Setup

### 1. Install Raspberry Pi OS and Dependencies

Use Raspberry Pi Imager to flash **Raspberry Pi OS (64-bit)** to your SD card.

On the first boot, before cloning OpenFlight, you'll likely need a few dependencies to run the setup.sh script.

Run the following command:

```bash
sudo apt update && sudo apt install -y swig liblgpio-dev python3-dev
```

If `./scripts/setup/setup.sh` updates `~/.bashrc`, you may need to run `source ~/.bashrc` (or open a new terminal) so your current shell picks up the new environment variables immediately without needing to reboot or re-login.

### 2. Run the setup script

Plug in the OPS243-A (and the K-LD7 adapters if you have them), then:

```bash
cd ~
git clone https://github.com/jewbetcha/openflight.git
cd openflight
./scripts/setup/setup.sh
```

The script installs everything, then walks you through the one-time hardware
configuration with prompts:

1. **Dependencies** — Python venv, packages, UI build, test run
2. **OPS243-A radar** — saves rolling buffer mode to the radar's flash
   (you'll be asked to unplug/replug the radar once)
3. **K-LD7 radars** (deprecated; if you have them) — identifies each radar by
   plugging them in one at a time, so OpenFlight always knows which is which
4. **Geekworm UPS** (optional) — enables native X1202/X1206 battery and
   external-power telemetry, Pi power settings, and desktop battery support
5. **Auto-start on boot** — optional systemd service
6. **Desktop shortcut** — optional
7. **FlightWeb cloud sync** — optional uploader and device linking

Every step can be skipped and the script is **safe to re-run** any time —
it picks up where you left off.

### 3. Start hitting balls

```bash
./scripts/start-kiosk.sh        # Default: rolling buffer + sound trigger
./scripts/start-kiosk.sh --mock # Mock mode (no hardware)
```

Then open `http://localhost:8080` or use the touchscreen.

For the current IWR6843 angle radar, use the measured startup command in the
[IWR6843 Operator Guide](iwr6843/README.md#start-openflight). Existing K-LD7
builds use `--kld7 --kld7-mount-tilt <measured-degrees>`; see
[Legacy K-LD7 Setup](kld7.md).

### 4. (Optional) Stream to a golf simulator

To send shots to GSPro, OpenGolfSim, or another supported sim, copy the
example config and enable your simulator:

```bash
cp config/sim.example.json config/sim.json   # then edit host/port + "enabled": true
```

See **[Simulator Connectors](simulator/README.md)** for the full guide.

---

## What the Script Configures (Reference)

You don't need this section unless something went wrong or you prefer to do
things by hand.

### OPS243-A Rolling Buffer Mode

The OPS243-A needs a one-time configuration to enable rolling buffer mode with
hardware sound triggering, saved to flash so it boots correctly every time.

> **Why?** The OPS243-A has a firmware bug where the HOST_INT pin mode switches
> unexpectedly when entering rolling buffer mode at runtime. Saving to flash and
> power cycling bypasses this. Confirmed by OmniPreSense engineering.

<details>
<summary>Manual steps</summary>

```bash
# 1. Configure and save to flash
uv run python scripts/hardware-test/test_rolling_buffer_persist.py --setup

# 2. Power cycle the radar, wait 3 seconds, reconnect (see note below)

# 3. Verify — make a sound near the SEN-14262, you should see I/Q trigger data
uv run python scripts/hardware-test/test_rolling_buffer_persist.py --test
```

How you power cycle depends on how the OPS243 is connected:

| Connection | Power cycle by |
|---|---|
| USB | Unplugging the USB cable |
| Pi GPIO UART | Disconnecting 5V from OPS `J3` pin 9 — **not** by rebooting the Pi, which does not necessarily drop the header rail |

If the OPS243 is on the GPIO UART, add `--port /dev/ttyAMA0` to both commands
above.

</details>

### IWR6843 Angle Radar

The setup script does not configure the IWR6843 — it needs custom firmware
flashed over the ROM bootloader, which requires physically moving a switch on
the board. That is covered end to end in the
**[IWR6843 Operator Guide](iwr6843/README.md)**.

Do it in this order, and confirm each step works before starting the next:

1. **Move the OPS243 to the Pi GPIO UART** —
   [migration guide](ops243-uart-migration.md). The Pi cannot power both radars
   over USB, so the OPS243 has to vacate the USB port. Validate the OPS on its
   own after rewiring, before the TI board is involved at all.
2. **Flash the IWR6843** — operator guide, *Flash The IWR6843 Firmware*. A
   validated prebuilt image is in `firmware/releases/`, so the TI toolchain is
   not required. You only need the
   [firmware developer guide](../firmware/README.md) to build from source.
3. **Mount, aim, and measure geometry** — operator guide. The geometry values
   are passed on the command line and a wrong one silently biases the launch
   angle instead of erroring, so measure rather than estimate.

Re-flashing is only needed if the image in `firmware/releases/` changes. A
software update alone does not require it — compare the release filename against
what you flashed.

> [!WARNING]
> A **WiFi-equipped OPS243-A cannot use the GPIO UART.** Its WiFi module already
> drives the radar processor's UART receive line, so the Pi cannot send it
> commands, and OpenFlight must be able to reconfigure and rearm the OPS after
> every capture. Use a separately powered USB hub for both radars instead
> (operator guide, Option B).

### Geekworm X1202/X1206 UPS

The optional UPS setup is automated and safe to rerun:

```bash
sudo ./scripts/battery/geekworm/setup.sh
sudo reboot
./scripts/battery/geekworm/setup.sh --verify
```

It enables I2C, native Linux battery and charger devices, the Pi 5 EEPROM power
settings required by Geekworm, and the Raspberry Pi taskbar compatibility
package. It does not install automatic shutdown or charging-control services.

Cell type, board-revision power limits, physical installation, every system
change, and troubleshooting are documented in the
**[Geekworm X1202/X1206 Operator Guide](battery/geekworm.md)**.

### K-LD7 Device Names (Deprecated Hardware)

Existing K-LD7 builds need stable `/dev/kld7_vertical` and
`/dev/kld7_horizontal` names because USB adapter numbers can swap after a
reboot. Run the device wizard, then follow the legacy guide:

```bash
./scripts/setup/setup_kld7_devices.sh
./scripts/setup/setup_kld7_devices.sh --show
```

The wizard also installs the required FTDI low-latency rule. See
[Legacy K-LD7 Setup](kld7.md) for mounting and startup, and
[K-LD7 Troubleshooting](kld7-troubleshooting.md) for serial failures.

### Auto-Start on Boot

The setup script installs and enables a systemd service configured for your
username and install path.

<details>
<summary>Manual steps and service management</summary>

```bash
# Install (adjust User= and paths in the file if your username isn't the default)
sudo cp ~/openflight/scripts/setup/openflight.service /etc/systemd/system/
sudo systemctl daemon-reload
sudo systemctl enable openflight
sudo systemctl start openflight
```

Management:

```bash
sudo systemctl status openflight --no-pager   # Check status
journalctl -u openflight -f                   # View logs
sudo systemctl stop openflight                # Stop
sudo systemctl restart openflight             # Restart
sudo systemctl disable openflight             # Disable auto-start
```

To modify the service:

```bash
sudo nano /etc/systemd/system/openflight.service
sudo systemctl daemon-reload
sudo systemctl restart openflight
```

</details>

## Running OpenFlight

### Kiosk Mode (Fullscreen — Recommended)

```bash
./scripts/start-kiosk.sh        # Default: rolling buffer + sound trigger
./scripts/start-kiosk.sh --mock # Mock mode (no hardware needed)
```

Use the [IWR6843 Operator Guide](iwr6843/README.md#start-openflight) or
[Legacy K-LD7 Setup](kld7.md) for angle-radar startup commands.

### Manual Start

```bash
openflight-server                # With radar
openflight-server --mock         # No hardware
```

Then open `http://localhost:8080`.

### Running Over SSH

```bash
DISPLAY=:0 ./scripts/start-kiosk.sh
```

## Observability (Grafana Cloud)

OpenFlight can ship session logs to Grafana Cloud for long-term analysis.

```bash
sudo ./scripts/setup/setup_alloy.sh
sudo vim /etc/alloy/credentials.env
```

See [observability.md](observability.md) for full setup and LogQL queries.

## Troubleshooting

### Radar Not Detected

```bash
uv run python scripts/hardware-test/diagnose.py

# OPS243 connected through the Pi GPIO UART
uv run python scripts/hardware-test/diagnose.py --ops-port /dev/ttyAMA0
```

### Sound Trigger Not Working

See the [Sound Trigger Wiring Guide — Troubleshooting](sound-trigger-wiring.md#troubleshooting).

### K-LD7 Not Connecting

```bash
# Check the device mapping
./scripts/setup/setup_kld7_devices.sh --show

# Test standalone
uv run python scripts/hardware-test/test_kld7.py
```

If the mapping is missing or points at the wrong radar, re-run the wizard:
`./scripts/setup/setup_kld7_devices.sh`. Look for `[KLD7] Connected on
/dev/ttyUSB...` in the server logs. See [K-LD7 Troubleshooting](kld7-troubleshooting.md)
for "Wrong length reply" and other connection issues.

### Service Won't Start

```bash
journalctl -u openflight --no-pager -n 50

# If service is masked
sudo systemctl unmask openflight
sudo cp ~/openflight/scripts/setup/openflight.service /etc/systemd/system/
sudo systemctl daemon-reload
sudo systemctl enable openflight
```

### Slow UI Updates

Check for WebSocket instability:
```bash
journalctl -u openflight -f
```

Look for "Client disconnected/connected" messages.

### Display Issues Over SSH

Use `DISPLAY=:0` before commands that need the Pi's display.

## Useful Commands

```bash
./scripts/setup/setup.sh --deps-only                              # Dependencies only
./scripts/start-kiosk.sh --port 3000                              # Custom web port
uv run python scripts/hardware-test/test_rolling_buffer_persist.py --test
uv run python scripts/hardware-test/test_sound_trigger_hardware.py
uv run pytest tests/ -v
```

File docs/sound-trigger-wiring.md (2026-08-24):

# Sound Trigger Wiring Guide

Step-by-step instructions for wiring the sound trigger that enables spin detection in rolling buffer mode.

> **Parts needed:** See the [Parts List](PARTS.md#sound-trigger-for-rolling-buffer-mode) for what to buy.

> **Running the OPS243 on the Pi GPIO UART instead of USB?** This trigger
> wiring is unchanged — `GATE` still drives `HOST_INT` directly. See
> [Moving the OPS243 from USB to the Pi GPIO UART](ops243-uart-migration.md)
> for the data and power side.

## Overview

The SparkFun SEN-14262 sound detector listens for club impact and triggers the OPS243-A radar to dump its I/Q buffer. That captured data is then analyzed for spin rate estimation.

The wiring is simple — three wires off the detector, plus the radar's ground
return:

```
SEN-14262 GATE → OPS243-A HOST_INT (J3 Pin 3)
SEN-14262 VCC  → Raspberry Pi 3.3V
SEN-14262 GND  → Raspberry Pi GND
OPS243-A GND   → Raspberry Pi GND (J3 Pin 10, shared rail)
```

Sound trigger wiring: the SEN-14262 sound detector runs on 3.3V from Raspberry Pi header pin 1 with ground on pin 6, its GATE output drives HOST_INT on OPS243 J3 pin 3, and OPS243 ground on J3 pin 10 returns to the Pi.

*The OPS243 keeps its micro-USB connection for data and power here; only the
trigger and ground are wired by hand. To take the radar off USB as well, see
[the UART migration](ops243-uart-migration.md).*

## Before You Wire: Solder R17

The SEN-14262 is designed for 5V but runs at 3.3V in this setup. At 3.3V the preamp gain is too high and the GATE output can get stuck high. To fix this, solder a through-hole resistor into the **R17** position on the SEN-14262 board.

R17 sits in parallel with the onboard 100kΩ surface-mount R3, reducing the preamp gain:

| R17 Value | Effective Resistance | Gain Reduction |
|---|---|---|
| 47kΩ | ~32kΩ | Moderate — try this first |
| 33kΩ | ~25kΩ | More aggressive — for noisy environments |

Start with 47kΩ. If the GATE LED still stays lit without sound, switch to a lower value.

---

## Wiring

### Step 1: Identify OPS243-A J3 Header Pins

`J3` is the **10-pin** header on the OPS243-A. Pin 1 is at the **right** end, so
the numbering runs right to left:

```
OPS243-A J3 header:
┌────┬────┬────┬────┬────┬────┬────┬────┬────┬────┐
│ 10 │  9 │  8 │  7 │  6 │  5 │  4 │  3 │  2 │  1 │
│GND │ 5V │    │TxD │RxD │    │    │INT │    │IO  │
└────┴────┴────┴────┴────┴────┴────┴────┴────┴────┘
```

The two pins this guide needs:

- **Pin 3** = HOST_INT (trigger input)
- **Pin 10** = GND

### Step 2: Connect Power

1. Connect **SEN-14262 VCC** → **Pi 3.3V** (physical pin 1)
2. Connect **SEN-14262 GND** → **Pi GND** (physical pin 6)
3. Connect **OPS243-A GND (J3 Pin 10)** → same **Pi GND** rail

All three boards must share a common ground.

### Step 3: Connect Trigger

1. Connect **SEN-14262 GATE** → **OPS243-A HOST_INT (J3 Pin 3)**

That's it. No level shifter, no MOSFETs, no breadboard needed.

```
SEN-14262               Raspberry Pi           OPS243-A
┌───────────┐          ┌──────────┐          ┌──────────┐
│ VCC ──────┼──────────┤ 3.3V     │          │          │
│           │          │          │          │          │
│ GATE ─────┼──────────┼──────────┼──────────┤ HOST_INT │
│           │          │          │          │ (J3 P3)  │
│ GND ──────┼──────────┤ GND      ├──────────┤ GND      │
│           │          │          │          │ (J3 P10) │
└───────────┘          └──────────┘          └──────────┘
```

---

## Wiring Checklist

- [ ] R17 resistor soldered on SEN-14262 board
- [ ] SEN-14262 VCC → Pi 3.3V (pin 1)
- [ ] SEN-14262 GND → Pi GND (pin 6)
- [ ] SEN-14262 GATE → OPS243-A HOST_INT (J3 Pin 3)
- [ ] OPS243-A GND (J3 Pin 10) → Pi GND (shared ground)

---

## One-Time Radar Setup

The OPS243-A must have rolling buffer mode saved to persistent memory for HOST_INT triggers to work. This is due to a firmware bug where the HOST_INT pin mode changes when transitioning modes at runtime.

```bash
# Configure and save rolling buffer mode to flash (one-time)
uv run python scripts/hardware-test/test_rolling_buffer_persist.py --setup

# Power cycle the radar (unplug USB, wait 3s, replug)

# Verify
uv run python scripts/hardware-test/test_rolling_buffer_persist.py --test
```

---

## Testing

### Quick Test: Visual

Make a loud sound near the SEN-14262. The onboard LED should flash briefly, then turn off. If the LED stays on constantly, you need a lower-value resistor in R17.

### Full Test: Software

```bash
uv run python scripts/hardware-test/test_sound_trigger_hardware.py
```

You should see:
```
Ready for hardware sound triggers!
Make a sound near the sensor... (Ctrl+C to quit)

[1] Waiting for hardware trigger (timeout=60s)...
  TRIGGER RECEIVED after 0.02s!
  I/Q samples: 4096 I, 4096 Q
```

---

## Troubleshooting

### GATE LED stays on (stuck high)

The preamp gain is too high for 3.3V operation.
- **Fix:** Solder a lower-value resistor into R17 (try 33kΩ instead of 47kΩ)

### No trigger received

1. Check the GATE LED flashes when you clap
2. Verify GND is shared between all three boards (Pi, SEN-14262, OPS243-A)
3. Verify HOST_INT is J3 **Pin 3** (not Pin 2)
4. Run `uv run python scripts/hardware-test/test_rolling_buffer_persist.py --test` to confirm radar is in rolling buffer mode

### Triggers constantly / too sensitive

- Use a lower-value R17 resistor to reduce gain
- Move the sensor further from the hitting area

### Triggers but no I/Q data

- Run the one-time radar setup (see above) — HOST_INT mode must be saved to flash
- Power cycle the radar after setup

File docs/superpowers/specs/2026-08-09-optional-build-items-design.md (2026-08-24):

# Optional Battery and Camera Build Items

## Goal

Document two optional OpenFlight build components in both the canonical parts
list and the Raspberry Pi setup prerequisites:

- Geekworm X1202 four-cell UPS HAT for Raspberry Pi 5
- InnoMaker OV9281 global-shutter camera module

## Documentation Changes

Add both products to the existing `Optional` table in `docs/PARTS.md`, using
the supplied Amazon links. List the UPS HAT at approximately $48 and note that
it requires four compatible 18650 Li-ion cells, sold separately for roughly
$25 total. List the camera at approximately $30.

Add matching bullets under a current `Optional` heading in
`docs/raspberry-pi-setup.md`. Keep this heading separate from the existing
deprecated K-LD7 hardware so builders do not mistake the new items for
deprecated components.

## Scope

This is a purchase-list and prerequisite-checklist update only. It does not add
installation instructions, change the core cost summary, or claim that either
item is required for OpenFlight operation.

## Verification

Review the Markdown tables and lists for valid formatting, confirm both Amazon
links exactly match the supplied URLs, and inspect the final Git diff for
unrelated changes.

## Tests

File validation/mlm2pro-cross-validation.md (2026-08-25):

# MLM2 Pro Cross-Validation Protocol

**Date:** 2026-07-30
**Instrument:** Rapsodo MLM2 Pro (dual camera + radar), owned.
**Adapted from:** upstream `docs/trackman-test-process.md` — the project's established methodology with TrackMan as truth. This doc maps that process onto the MLM2 Pro.

## Why this matters upstream (not just for my build)

The public repo repeatedly names its biggest gap — a reference instrument:

- README: *"help validating [the dechirped spin estimator] against launch-monitor truth data is especially welcome."*
- IWR6843 Operator Guide, estimator limitations: three known-unresolved issues (curvature criterion not scale-normalised, select-vs-average policy, the 8° agreement gate resting on one session) are *"deferred pending a session paired with a reference instrument, which this repo does not have."*
- `compare_trackman.py` exists but TrackMan access is rare; a repeatable consumer-reference workflow would let more contributors produce comparison data.

A well-run MLM2 Pro protocol + published datasets is likely the **highest-leverage contribution I can make** with hardware I already own.

## Know your reference instrument (honest error bars)

The MLM2 Pro is a consumer unit, not a TrackMan. Treat it as a **reference for bias/trend detection**, not absolute truth.

| Metric | MLM2 Pro basis | Trust level for validation |
|---|---|---|
| Ball speed | Radar, measured | **High** — primary anchor metric |
| Launch angle (vertical) | Camera (Shot Vision), measured | **Good** — key for IWR6843 comparison |
| Launch direction (horizontal) | Camera, measured | **Good** |
| Spin rate / spin axis | **Measured only with RPT-marked balls** (Callaway Chrome Soft X RPT); otherwise algorithmically estimated | **Good with RPT balls; near-worthless without** |
| Club speed | Radar-derived; consumer reviews note it's less reliable than ball data | **Medium** — compare, but don't tune OpenFlight club speed against it alone |
| Carry / total | Simulated from launch conditions (especially indoors into a net) | **Low as truth** — both devices model carry; compare models, don't calibrate to it |

Rules that follow:

1. **RPT balls are mandatory for spin sessions.** Log ball type per shot block.
2. Indoors, compare **launch conditions** (speed, angles, spin), not outcomes (carry) — both units model carry from conditions, so carry agreement only tests whose ballistics model is which.
3. Log the MLM2 Pro app/firmware version each session; consumer devices change behavior across updates.

## Physical setup & interference check

Both units sit **behind the ball**: MLM2 Pro at its specified distance (~6–8 ft per Rapsodo setup guidance), OpenFlight at 3–5 ft. Side-by-side or stacked placement must not block either unit's view/beam.

⚠️ **Radar interference is an open question to test, not assume away.** The MLM2 Pro's radar operates in K-band (same neighborhood as the OPS243's 24.125 GHz CW). The IWR6843 is at 60 GHz (no conflict). Before trusting joint sessions, run the A/B/AB check:

1. **A:** 10 shots, OpenFlight only → note spin read rate, spin SNR (`spin_snr`), ball-speed spread.
2. **B:** 10 shots, MLM2 Pro only → note its readings behave normally.
3. **AB:** 10 shots, both running → compare OpenFlight `spin_snr` / read rate / trigger behavior vs session A, and MLM2 readings vs session B.

If AB degrades OpenFlight spin SNR or MLM2 readings, try greater lateral separation, then alternating-shot capture as the fallback (worse: no shot-paired data). Record the outcome in `notes/` — this result is itself useful to upstream (others will ask).

## Session protocol

**Fixed per session (record in a session header note):**

- Date, location, indoor/outdoor, net distance
- OpenFlight geometry actually passed on the command line (tee-m, net-m, tilt-deg, radar-height-m, ball-height-m, azimuth-offset-deg)
- OpenFlight commit SHA; MLM2 app version; ball type (RPT or not); mat vs tee per block
- Club per block; any intentional shot shaping (low/high, push/pull, cuts)

**Command:** run with `--debug` (keeps IWR `.l3dump` captures for replay) and a session location tag, e.g.:

```bash
scripts/start-kiosk.sh --debug --session-location mlm2-validation [geometry flags…]
```

**Shot matrix (target per full session):**

| Block | Club | Shots | Ball | Purpose |
|---|---|---|---|---|
| 1 | Driver | 10–15 | RPT | High speed, low spin — spin lower-rail behavior (≤~3100 RPM reduced-confidence zone) |
| 2 | 7-iron | 10–15 | RPT | Mid speed/spin — the plausibility-gating club class |
| 3 | PW or SW | 10–15 | RPT | High spin — upper-rail behavior (~12000 RPM rejection zone) |
| 4 (optional) | Any | 5–10 | range balls | Spin estimator behavior on unmarked balls |

Select the matching club in the OpenFlight UI per block (drives fallbacks and spin rail filtering). Keep shot order logged — pairing is by sequence + timestamp.

## Data collection & pairing

- **OpenFlight:** session JSONL from `~/openflight_sessions/` (rows: `shot_detected`, `rolling_buffer_capture`, `iwr6843_capture`, `trigger_diagnostic`), plus `.l3dump` files (debug mode).
- **MLM2 Pro:** export session CSV from the Rapsodo app (premium feature); if export is unavailable, transcribe per-shot from the app immediately after the session (tedious but workable for 30–45 shots).
- **Pairing:** shot index + wall-clock. Flag and exclude shots only one device saw — but *count* them: detection-rate asymmetry is a finding, not noise (upstream's first question: "Did OpenFlight detect the same shot the reference saw?").

## Analysis

Upstream already ships `scripts/analysis/compare_trackman.py` (per-club bias + row-level deltas for ball speed, club speed, smash, vertical/horizontal launch, spin, carry, plus OpenFlight spin diagnostics columns).

### Running the MLM2 Pro Adapter

We provide `scripts/analysis/mlm2pro_adapter.py` to convert raw Rapsodo MLM2 Pro exports (from R-Cloud or mobile app) into the standard TrackMan CSV layout.

#### Option 1: Standalone Adapter Conversion

Convert the exported CSV to TrackMan layout, then run `compare_trackman.py`:

```bash
# 1. Convert MLM2 Pro CSV export to TrackMan CSV format
uv run python scripts/analysis/mlm2pro_adapter.py \
    --input ~/Downloads/mlm2pro_session_20260730.csv \
    --output ~/openflight_sessions/mlm2pro_trackman_20260730.csv

# 2. Compare OpenFlight session log against the converted reference
uv run python scripts/analysis/compare_trackman.py \
    --openflight ~/openflight_sessions/session_20260730_*.jsonl \
    --trackman ~/openflight_sessions/mlm2pro_trackman_20260730.csv \
    --output ~/openflight_sessions/comparison_20260730.csv
```

#### Option 2: Direct `--source mlm2pro` in `compare_trackman.py`

Alternatively, pass the raw MLM2 Pro CSV directly using `--source mlm2pro`:

```bash
uv run python scripts/analysis/compare_trackman.py \
    --openflight ~/openflight_sessions/session_20260730_*.jsonl \
    --trackman ~/Downloads/mlm2pro_session_20260730.csv \
    --source mlm2pro \
    --output ~/openflight_sessions/comparison_20260730.csv
```

### Adapter Features & Column Mapping

- **Column Aliases:** Resolves variations in MLM2 Pro exports (`Shot Number` / `Shot #`, `DateTime` / `Date` + `Time`, `Club Type` / `Club`, `Ball Speed`, `Club Speed`, `Launch Angle`, `Launch Direction` / `Side Angle`, `Total Spin` / `Spin Rate`, `Spin Axis` / `Tilt Angle`, `Carry Distance`, `Apex`, `Smash Factor`).
- **Unit Conversions:** Automatically detects and converts speeds (`m/s` or `km/h` -> `mph`) and distances (`meters` -> `yards`, apex `meters` -> `feet`). Explicit overrides can be provided via `--speed-unit` and `--distance-unit`.
- **Directional Formats:** Parses L/R angle notations (e.g. `2.5 R` -> `+2.5`, `1.8 L` -> `-1.8`, `Straight` -> `0.0`).
- **Robust Ingestion:** Strips UTF-8 BOMs and Excel `sep=,` preambles; skips metadata headers and summary rows (`Average`, `Std Dev`, `Total`); falls back gracefully on missing / unmeasured metrics.

**Per session, report (mirroring upstream's post-session checklist):**

- Detection rate: shots seen by both / OpenFlight-only / MLM2-only
- Ball speed: bias, stddev of deltas (expect tight agreement — if not, something is wrong with setup, not physics)
- Launch angle V/H: bias, RMSE; split by `angle_source` (radar vs estimated) — only `Angle source: radar` shots validate the IWR estimator
- Spin: read rate, delta on accepted readings, rejection reasons histogram (`spin_rejection_reason`), rail flags — do **not** advocate loosening guardrails to raise read rate unless accepted candidates prove accurate (explicit upstream rule)
- Club speed: bias with the MLM2 caveat noted
- Carry: report deltas for curiosity, labeled "model vs model"
- Per-shot outlier autopsies: for the 2–3 worst disagreements, pull the JSONL diagnostics (spin SNR, track RMS, inlier count, rejection reasons) and the `.l3dump` replay

**Statistics:** with n≈10–15 per club, stick to mean bias ± stddev and Bland-Altman-style plots per metric; resist significance theater. Trends across sessions matter more than any single session.

## Deliverables ladder (each rung is upstream-useful)

1. First joint session ran + interference check documented → `notes/`
2. MLM2→TrackMan-format adapter script + first comparison CSV → this repo
3. 3+ sessions of paired data with per-club bias summary → shareable dataset
4. Upstream PR: `compare_trackman.py` MLM2 Pro source support + process doc
5. Upstream issue-quality data: IWR estimator behavior vs reference on the exact open questions (8° gate placement, select-vs-average on disagreeing-but-healthy channels), and dechirp spin estimator truth pairs

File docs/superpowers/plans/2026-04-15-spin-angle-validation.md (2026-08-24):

# Spin & Angle Data Quality Validation — Implementation Plan

> **For agentic workers:** REQUIRED SUB-SKILL: Use superpowers:subagent-driven-development (recommended) or superpowers:executing-plans to implement this plan task-by-task. Steps use checkbox (`- [ ]`) syntax for tracking.

**Goal:** Fix spin confidence over-reporting and missing angle validation so bad measurements don't reach the Shot object.

**Architecture:** Surgical changes inside existing detection code — `processor.py` for spin, `radc.py` + `tracker.py` for angles, `server.py` for horizontal plausibility. One new shared constant in `launch_monitor.py`. TDD for every behavioral change.

**Tech Stack:** Python, numpy, pytest

**Spec:** `docs/superpowers/specs/2026-04-15-spin-angle-validation-design.md`

---

### Task 1: Extract shared SPIN_CONFIDENCE_HIGH constant

**Files:**
- Modify: `src/openflight/launch_monitor.py:315`
- Modify: `src/openflight/rolling_buffer/processor.py:593-604`

- [ ] **Step 1: Add constant to launch_monitor.py**

In `src/openflight/launch_monitor.py`, add the constant after the imports (before `ClubType`), and use it in `spin_quality`:

```python
# Spin confidence threshold for "high" quality — used across modules.
# Measured spin is trusted for physics simulation only above this level.
SPIN_CONFIDENCE_HIGH = 0.7
```

Then update `spin_quality` (line 315) to use it:

```python
        if self.spin_confidence >= SPIN_CONFIDENCE_HIGH:
            return "high"
```

- [ ] **Step 2: Run existing tests to verify no regressions**

Run: `uv run pytest tests/test_rolling_buffer.py::TestSpinResult -v && uv run pytest tests/test_rolling_buffer.py::TestShotWithSpin -v`
Expected: All existing tests PASS (behavior unchanged — same threshold value)

- [ ] **Step 3: Import constant in processor.py**

In `src/openflight/rolling_buffer/processor.py`, add to imports:

```python
from ..launch_monitor import SPIN_CONFIDENCE_HIGH
```

No behavioral change yet — this just wires up the import for use in Task 2.

- [ ] **Step 4: Run tests to verify import works**

Run: `uv run pytest tests/test_rolling_buffer.py::TestSpinDetectionIntegration -v`
Expected: All PASS

- [ ] **Step 5: Commit**

```bash
git add src/openflight/launch_monitor.py src/openflight/rolling_buffer/processor.py
git commit -m "refactor: extract SPIN_CONFIDENCE_HIGH constant to launch_monitor"
```

---

### Task 2: Tighten spin confidence scoring + add hard RPM cap

**Files:**
- Modify: `src/openflight/rolling_buffer/processor.py:485-604`
- Test: `tests/test_rolling_buffer.py`

- [ ] **Step 1: Write failing test for hard RPM cap**

Add to `tests/test_rolling_buffer.py` at the end of the file:

```python
class TestSpinValidationGates:
    """Tests for spin detection validation: RPM ceiling, confidence tiers, modulation floor."""

    def _make_iq_with_seam_modulation(
        self,
        base_speed_mph: float,
        spin_rpm: float,
        modulation_depth: float = 0.03,
        sample_rate: int = 30000,
        num_samples: int = 4096,
    ):
        """Generate synthetic I/Q with amplitude modulation at 1x spin rate."""
        wavelength = 0.01243
        speed_mps = base_speed_mph / 2.23694
        doppler_hz = 2 * speed_mps / wavelength
        seam_hz = spin_rpm / 60.0
        t = np.arange(num_samples) / sample_rate
        phase = 2 * np.pi * doppler_hz * t
        amplitude = 200 * (1.0 + modulation_depth * np.sin(2 * np.pi * seam_hz * t))
        i_samples = (amplitude * np.cos(phase) + 2048).astype(int).clip(0, 4095).tolist()
        q_samples = (amplitude * np.sin(phase) + 2048).astype(int).clip(0, 4095).tolist()
        return i_samples, q_samples

    def test_rpm_above_12000_rejected(self):
        """Spin above SPIN_MAX_SEAM_HZ * 60 (12000 RPM) must be rejected."""
        processor = RollingBufferProcessor()
        # Create I/Q with 13000 RPM modulation — above the physical cap.
        # Call detect_spin directly so we can specify the exact ball timestamp.
        i_samples, q_samples = self._make_iq_with_seam_modulation(
            base_speed_mph=100,
            spin_rpm=13000,
            modulation_depth=0.05,
        )
        capture = IQCapture(
            sample_time=0.0,
            trigger_time=0.068,
            i_samples=i_samples,
            q_samples=q_samples,
        )
        result = processor.detect_spin(capture, ball_speed_mph=100, ball_timestamp_ms=5.0)
        assert result.spin_rpm == 0, f"13000 RPM should be rejected, got {result.spin_rpm} RPM"
```

- [ ] **Step 2: Run test to verify it fails**

Run: `uv run pytest tests/test_rolling_buffer.py::TestSpinValidationGates::test_rpm_above_12000_rejected -v`
Expected: FAIL — 13000 RPM is above SPIN_MAX_SEAM_HZ (200 Hz) so the FFT mask should already reject it, but this test confirms the safety net. If it passes already (FFT mask catches it), that's fine — the hard cap is still needed for the autocorrelation override path.

- [ ] **Step 3: Write failing test for tightened confidence — bare SNR without cycles**

Add to `TestSpinValidationGates`:

```python
def test_medium_snr_low_cycles_gets_reduced_confidence(self):
    """SNR >= 5 but < 3 seam cycles should score 0.5, not 0.7.

    With a short ball window (few cycles), the FFT peak is unreliable
    even with decent SNR — this is the repeated-bin pattern.
    """
    processor = RollingBufferProcessor()
    # Use 700 samples (~23ms) at 4000 RPM = 66.7 Hz → ~1.5 seam cycles.
    # Short window means few cycles, but SNR can still be decent.
    i_samples, q_samples = self._make_iq_with_seam_modulation(
        base_speed_mph=130,
        spin_rpm=4000,
        modulation_depth=0.04,
        num_samples=700,
    )
    capture = IQCapture(
        sample_time=0.0,
        trigger_time=0.003,
        i_samples=i_samples,
        q_samples=q_samples,
    )
    result = processor.detect_spin(capture, ball_speed_mph=130, ball_timestamp_ms=1.0)
    # If spin is detected at all, confidence should be <= 0.5
    if result.spin_rpm > 0:
        assert result.confidence <= 0.5, (
            f"Low-cycle detection should cap at 0.5, got {result.confidence}"
        )
```

- [ ] **Step 4: Run test to verify it fails**

Run: `uv run pytest tests/test_rolling_buffer.py::TestSpinValidationGates::test_medium_snr_low_cycles_gets_reduced_confidence -v`
Expected: FAIL (current code gives 0.7 for bare `SNR >= 5.0`)

- [ ] **Step 5: Write failing test for modulation depth confidence cap**

Add to `TestSpinValidationGates`:

```python
def test_weak_modulation_caps_confidence(self):
    """Modulation depth < 1% should cap confidence at 0.5 max."""
    processor = RollingBufferProcessor()
    # 0.008 modulation depth — above the 0.005 rejection floor but below 1%.
    i_samples, q_samples = self._make_iq_with_seam_modulation(
        base_speed_mph=130,
        spin_rpm=5000,
        modulation_depth=0.008,
    )
    capture = IQCapture(
        sample_time=0.0,
        trigger_time=0.068,
        i_samples=i_samples,
        q_samples=q_samples,
    )
    result = processor.detect_spin(capture, ball_speed_mph=130, ball_timestamp_ms=5.0)
    if result.spin_rpm > 0:
        assert result.confidence <= 0.5, (
            f"Weak modulation should cap at 0.5, got {result.confidence}"
        )
```

- [ ] **Step 6: Run test to verify it fails**

Run: `uv run pytest tests/test_rolling_buffer.py::TestSpinValidationGates::test_weak_modulation_caps_confidence -v`
Expected: FAIL (current code doesn't cap confidence based on modulation depth)

- [ ] **Step 7: Write test that good spin still scores high**

Add to `TestSpinValidationGates`:

```python
def test_strong_spin_still_scores_high(self):
    """Clean spin with good SNR and many cycles should still score 0.9."""
    processor = RollingBufferProcessor()
    i_samples, q_samples = self._make_iq_with_seam_modulation(
        base_speed_mph=120,
        spin_rpm=7000,
        modulation_depth=0.03,
    )
    capture = IQCapture(
        sample_time=0.0,
        trigger_time=0.068,
        i_samples=i_samples,
        q_samples=q_samples,
    )
    result = processor.detect_spin(capture, ball_speed_mph=120, ball_timestamp_ms=5.0)
    assert result.spin_rpm > 0, f"Should detect spin, got quality={result.quality}"
    assert result.confidence >= 0.8, f"Strong spin should score >= 0.8, got {result.confidence}"
```

- [ ] **Step 8: Run to verify it passes (existing behavior should handle this)**

Run: `uv run pytest tests/test_rolling_buffer.py::TestSpinValidationGates::test_strong_spin_still_scores_high -v`
Expected: PASS (7000 RPM at 120 mph with 3% modulation should produce high SNR and many cycles)

- [ ] **Step 9: Implement all three spin validation changes in processor.py**

In `src/openflight/rolling_buffer/processor.py`, make three changes:

**Change A — Modulation depth flag (after line 494):**

Replace:

```python
        # Remove DC and apply Hann window
        ball_envelope -= envelope_mean
```

With:

```python
        # Flag weak modulation — above the noise floor (0.5%) but below
        # the level where we trust the envelope FFT peak (1%). Caps
        # confidence later to prevent marginal signals scoring 0.7+.
        weak_modulation = modulation_depth < 0.01

        # Remove DC and apply Hann window
        ball_envelope -= envelope_mean
```

**Change B — Hard RPM cap (after line 531, before the cycles check):**

After the line `spin_rpm = peak_freq * 60`, add:

```python
        # Hard ceiling — reject anything above physical maximum.
        # The FFT mask should enforce this, but the autocorrelation override
        # path can bypass it. Belt-and-suspenders.
        max_rpm = self.SPIN_MAX_SEAM_HZ * 60
        if spin_rpm > max_rpm:
            return SpinResult.no_spin_detected(
                f"Spin {spin_rpm:.0f} RPM exceeds physical maximum ({max_rpm:.0f})"
            )
```

**Change C — New confidence tiers (replace lines 593-604):**

Replace:

```python
        if fft_snr >= self.SPIN_SNR_HIGH and seam_cycles >= 5:
            quality = "high"
            confidence = 0.9
        elif fft_snr >= self.SPIN_SNR_MEDIUM or autocorr_confirmed:
            quality = "medium"
            confidence = 0.7
        elif fft_snr >= self.SPIN_SNR_MIN:
            quality = "low"
            confidence = 0.4
        else:
            quality = "low"
            confidence = 0.3
```

With:

```python
        if fft_snr >= self.SPIN_SNR_HIGH and seam_cycles >= 5:
            quality = "high"
            confidence = 0.9
        elif fft_snr >= self.SPIN_SNR_HIGH and seam_cycles >= 3:
            quality = "high"
            confidence = 0.8
        elif fft_snr >= self.SPIN_SNR_MEDIUM and (seam_cycles >= 3 or autocorr_confirmed):
            quality = "medium"
            confidence = SPIN_CONFIDENCE_HIGH
        elif fft_snr >= self.SPIN_SNR_MEDIUM or autocorr_confirmed:
            quality = "low"
            confidence = 0.5
        elif fft_snr >= self.SPIN_SNR_MIN:
            quality = "low"
            confidence = 0.3
        else:
            quality = "low"
            confidence = 0.3

        # Weak modulation caps confidence — the envelope FFT peak may be
        # noise rather than real seam modulation.
        if weak_modulation:
            confidence = min(confidence, 0.5)
            if quality == "high":
                quality = "medium"
```

- [ ] **Step 10: Run all spin tests**

Run: `uv run pytest tests/test_rolling_buffer.py::TestSpinValidationGates -v && uv run pytest tests/test_rolling_buffer.py::TestSpinDetectionIntegration -v`
Expected: All new tests PASS, all existing spin tests PASS

- [ ] **Step 11: Commit**

```bash
git add src/openflight/rolling_buffer/processor.py tests/test_rolling_buffer.py
git commit -m "fix: tighten spin confidence scoring and add hard RPM ceiling"
```

---

### Task 3: Add hard angle bounds in radc.py

**Files:**
- Modify: `src/openflight/kld7/radc.py:276-285, 443-445`
- Modify: `src/openflight/kld7/tracker.py:321-327`
- Test: `tests/test_kld7_radc_lib.py`

- [ ] **Step 1: Write failing test for vertical angle bounds**

Add to `tests/test_kld7_radc_lib.py`:

```python
from openflight.kld7.radc import extract_launch_angle

class TestAngleBoundsValidation:
    """Tests for hard angle bounds rejection in extract_launch_angle."""

    def _make_single_frame_with_angle(self, angle_deg: float, snr: float = 10.0):
        """Create a minimal synthetic RADC frame that produces a known angle.

        Rather than constructing raw I/Q that produces a specific angle through
        the full pipeline (fragile), we test the bounds check by calling
        extract_launch_angle with crafted frames and verifying the result
        is filtered. This relies on the integration tests in test_kld7.py
        for end-to-end coverage.
        """
        # Build a synthetic 3072-byte RADC payload with a known phase offset
        # between F1A and F2A that produces the desired angle.
        # angle = arcsin(dphi * lambda / (2 * pi * d))
        # dphi = arcsin(angle_deg * pi / 180) * 2 * pi * d / lambda
        import math

        wavelength = 0.01243
        spacing = 0.008
        dphi = (
            math.asin(max(-1, min(1, math.sin(math.radians(angle_deg)))))
            * 2
            * math.pi
            * spacing
            / wavelength
        )

        # Create payload: F1A and F2A with a phase offset that produces dphi
        # at a specific FFT bin. We put energy in bin 50 (a mid-range velocity).
        n = 256
        t = np.arange(n, dtype=np.float64)
        freq_bin = 50
        f = freq_bin / n  # normalized frequency

        # F1A: reference channel
        f1a_i = (100 * np.cos(2 * np.pi * f * t) + 2048).astype(np.uint16)
        f1a_q = (100 * np.sin(2 * np.pi * f * t) + 2048).astype(np.uint16)
        # F2A: phase-shifted channel
        f2a_i = (100 * np.cos(2 * np.pi * f * t + dphi) + 2048).astype(np.uint16)
        f2a_q = (100 * np.sin(2 * np.pi * f * t + dphi) + 2048).astype(np.uint16)
        # F1B: unused, zero
        f1b_i = np.full(n, 2048, dtype=np.uint16)
        f1b_q = np.full(n, 2048, dtype=np.uint16)

        payload = b"".join(ch.tobytes() for ch in [f1a_i, f1a_q, f2a_i, f2a_q, f1b_i, f1b_q])
        return {"timestamp": 0.0, "radc": payload}

    def test_vertical_angle_above_45_rejected(self):
        """Vertical angles above 45° should be filtered out."""
        frame = self._make_single_frame_with_angle(50.0)
        results = extract_launch_angle(
            [frame] * 5,
            ops243_ball_speed_mph=100.0,
            orientation="vertical",
        )
        for r in results:
            assert r["launch_angle_deg"] <= 45.0, (
                f"Vertical angle {r['launch_angle_deg']}° should be rejected (>45°)"
            )

    def test_vertical_angle_below_0_rejected(self):
        """Negative vertical angles should be filtered out."""
        frame = self._make_single_frame_with_angle(-5.0)
        results = extract_launch_angle(
            [frame] * 5,
            ops243_ball_speed_mph=100.0,
            orientation="vertical",
        )
        for r in results:
            assert r["launch_angle_deg"] >= 0.0, (
                f"Vertical angle {r['launch_angle_deg']}° should be rejected (<0°)"
            )

    def test_horizontal_angle_beyond_15_rejected(self):
        """Horizontal angles beyond ±15° should be filtered out."""
        frame = self._make_single_frame_with_angle(20.0)
        results = extract_launch_angle(
            [frame] * 5,
            ops243_ball_speed_mph=100.0,
            orientation="horizontal",
        )
        for r in results:
            assert abs(r["launch_angle_deg"]) <= 15.0, (
                f"Horizontal angle {r['launch_angle_deg']}° should be rejected (>±15°)"
            )

    def test_valid_vertical_angle_passes(self):
        """A valid 12° vertical angle should pass through."""
        frame = self._make_single_frame_with_angle(12.0)
        results = extract_launch_angle(
            [frame] * 5,
            ops243_ball_speed_mph=100.0,
            orientation="vertical",
        )
        # Result may be empty if synthetic frame doesn't produce enough SNR,
        # but if present, the angle should be close to 12°.
        # This test verifies valid angles aren't rejected by the bounds check.
        for r in results:
            assert 0.0 <= r["launch_angle_deg"] <= 45.0

    def test_orientation_defaults_to_no_filtering(self):
        """When orientation is not specified, no angle bounds are applied (backward compat)."""
        frame = self._make_single_frame_with_angle(50.0)
        # No orientation parameter — should not crash or filter
        results = extract_launch_angle(
            [frame] * 5,
            ops243_ball_speed_mph=100.0,
        )
        # Just verify it doesn't raise — bounds filtering is opt-in via orientation
```

- [ ] **Step 2: Run tests to verify they fail**

Run: `uv run pytest tests/test_kld7_radc_lib.py::TestAngleBoundsValidation -v`
Expected: FAIL — `extract_launch_angle` doesn't accept an `orientation` parameter yet

- [ ] **Step 3: Add orientation parameter and bounds check to extract_launch_angle**

In `src/openflight/kld7/radc.py`, modify the function signature (line 276):

Replace:

```python
def extract_launch_angle(
    frames: list[dict],
    fft_size: int = 2048,
    max_speed_kmh: float = 100.0,
    cfar_threshold: float = 2.5,
    impact_energy_threshold: float = 3.0,
    angle_offset_deg: float = 0.0,
    ops243_ball_speed_mph: float | None = None,
    speed_tolerance_mph: float = 10.0,
) -> list[dict]:
```

With:

```python
def extract_launch_angle(
    frames: list[dict],
    fft_size: int = 2048,
    max_speed_kmh: float = 100.0,
    cfar_threshold: float = 2.5,
    impact_energy_threshold: float = 3.0,
    angle_offset_deg: float = 0.0,
    ops243_ball_speed_mph: float | None = None,
    speed_tolerance_mph: float = 10.0,
    orientation: str | None = None,
) -> list[dict]:
```

Then, inside the function, after `corrected_angle` is computed (after line 422) and before `avg_speed_mph` (line 424), add the bounds check:

Replace:

```python
        corrected_angle = weighted_angle + angle_offset_deg

        avg_speed_mph = float(np.mean(peak_speeds_mph))
```

With:

```python
        corrected_angle = weighted_angle + angle_offset_deg

        # Hard physical bounds — reject obvious outliers before they
        # reach the Shot object. Orientation-aware: vertical [0°, 45°],
        # horizontal [-15°, +15°]. When orientation is None (offline
        # analysis), skip bounds filtering.
        if orientation == "vertical" and not (0.0 <= corrected_angle <= 45.0):
            logger.info(
                "[RADC] Vertical angle %.1f° outside [0, 45] — rejected",
                corrected_angle,
            )
            continue
        if orientation == "horizontal" and abs(corrected_angle) > 15.0:
            logger.info(
                "[RADC] Horizontal angle %.1f° outside ±15° — rejected",
                corrected_angle,
            )
            continue

        avg_speed_mph = float(np.mean(peak_speeds_mph))
```

Also add `import logging` and `logger = logging.getLogger(__name__)` at the top of `radc.py` if not already present.

- [ ] **Step 4: Pass orientation from tracker.py**

In `src/openflight/kld7/tracker.py`, update `_extract_ball_radc()` (line 321):

Replace:

```python
        results = extract_launch_angle(
            frames,
            ops243_ball_speed_mph=ball_speed_mph,
            angle_offset_deg=self.angle_offset_deg,
            speed_tolerance_mph=10.0,
            impact_energy_threshold=energy_threshold,
        )
```

With:

```python
        results = extract_launch_angle(
            frames,
            ops243_ball_speed_mph=ball_speed_mph,
            angle_offset_deg=self.angle_offset_deg,
            speed_tolerance_mph=10.0,
            impact_energy_threshold=energy_threshold,
            orientation=self.orientation,
        )
```

- [ ] **Step 5: Run angle bounds tests and existing K-LD7 tests**

Run: `uv run pytest tests/test_kld7_radc_lib.py::TestAngleBoundsValidation -v && uv run pytest tests/test_kld7_radc_lib.py -v`
Expected: All PASS

- [ ] **Step 6: Commit**

```bash
git add src/openflight/kld7/radc.py src/openflight/kld7/tracker.py tests/test_kld7_radc_lib.py
git commit -m "fix: add hard angle bounds to K-LD7 extraction (V[0,45] H[±15])"
```

---

### Task 4: Add horizontal angle plausibility check in server.py

**Files:**
- Modify: `src/openflight/server.py:997-1002`
- Test: `tests/test_rolling_buffer.py` (server-level test)

- [ ] **Step 1: Write failing test for horizontal rejection**

Add to `tests/test_rolling_buffer.py`:

```python
class TestHorizontalAnglePlausibility:
    """Tests for server-level horizontal angle rejection."""

    def test_extreme_horizontal_angle_rejected(self):
        """Horizontal angles beyond ±15° should not reach the Shot."""
        # This tests the contract: any KLD7Angle with |horizontal_deg| > 15
        # should be rejected before assignment to shot.launch_angle_horizontal.
        # We test the logic directly rather than spinning up the server.
        h_angle = 34.0  # The exact value from the bad session
        assert abs(h_angle) > 15.0, "Test setup: angle should be out of bounds"

    def test_valid_horizontal_angle_accepted(self):
        """Horizontal angles within ±15° should be accepted."""
        h_angle = -3.3
        assert abs(h_angle) <= 15.0, "Test setup: angle should be in bounds"
```

Note: These are contract/sanity tests. The real integration test requires the full server, which we can't run in CI without hardware. The bounds check in `radc.py` (Task 3) is the primary gate; this server-level check is the backstop.

- [ ] **Step 2: Add horizontal plausibility check in server.py**

In `src/openflight/server.py`, replace lines 997-1002:

Replace:

```python
                if kld7_angle_h and kld7_angle_h.horizontal_deg is not None:
                    shot.launch_angle_horizontal = kld7_angle_h.horizontal_deg
                    if shot.angle_source is None:
                        shot.angle_source = "radar"
                    if shot.launch_angle_confidence is None:
                        shot.launch_angle_confidence = kld7_angle_h.confidence
```

With:

```python
                if kld7_angle_h and kld7_angle_h.horizontal_deg is not None:
                    if abs(kld7_angle_h.horizontal_deg) <= 15.0:
                        shot.launch_angle_horizontal = kld7_angle_h.horizontal_deg
                        if shot.angle_source is None:
                            shot.angle_source = "radar"
                        if shot.launch_angle_confidence is None:
                            shot.launch_angle_confidence = kld7_angle_h.confidence
                    else:
                        logger.warning(
                            "[SERVER] Horizontal angle %.1f° rejected: exceeds ±15°",
                            kld7_angle_h.horizontal_deg,
                        )
```

- [ ] **Step 3: Run tests**

Run: `uv run pytest tests/test_rolling_buffer.py::TestHorizontalAnglePlausibility -v`
Expected: PASS

- [ ] **Step 4: Run full test suite to check for regressions**

Run: `uv run pytest tests/ -v --timeout=60`
Expected: All tests PASS

- [ ] **Step 5: Commit**

```bash
git add src/openflight/server.py tests/test_rolling_buffer.py
git commit -m "fix: add horizontal angle plausibility check (±15° max)"
```

---
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

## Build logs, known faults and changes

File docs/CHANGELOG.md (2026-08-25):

# Changelog

All notable changes to this project will be documented in this file.

The format is based on [Keep a Changelog](https://keepachangelog.com/en/1.1.0/),
and this project adheres to [Semantic Versioning](https://semver.org/spec/v2.0.0.html).

## [Unreleased]

### Added
- **Battery and external-power status for Raspberry Pi UPS boards.** OpenFlight
  can now display charging state and battery percentage, issue dismissible 20%
  and 10% warnings while discharging, and record throttled power telemetry in
  session logs. Enable the initial Geekworm X1202/X1206 provider with
  `--battery geekworm`; monitoring remains disabled when no provider is
  selected. The accompanying Pi setup installs native Linux power-supply
  telemetry and optional taskbar capacity support without enabling automatic
  shutdown or charging control. See [Battery Monitoring](battery/README.md).
- **System Prerequisites:** Documented missing binary dependencies (`swig`, `liblgpio-dev`, `python3-dev`) required prior to executing `./scripts/setup/setup.sh`.
- **Environment Reload Guidance:** Added instructions for reloading terminal environment variables (`source ~/.bashrc`) when installed dependencies or scripts (`setup.sh`, `start-kiosk.sh`) are not recognized in the current terminal session.
- **Configurable IWR6843 capture compression.** One firmware image can now
  switch at runtime between the recommended 24-frame, 3 ms, 53-bin IQ16
  profile and an advanced 36-frame, 2 ms, 32-bin IQ8 profile. Both retain the
  same 72 ms shot movie and all 3 TX x 4 RX channels. Per-frame range windows,
  timing, and IQ8 scales are carried in the dump so offline and live processing
  use the actual capture geometry. The dense profile uses a sparse scale
  preview to sustain the 2 ms HWA rearm budget and exposes missed frames,
  overruns, and clipped components through firmware `stats`.
- **OPS243 over the Raspberry Pi GPIO UART.** The radar can now run on the J3
  header instead of USB, which frees the Pi's USB power budget for the TI angle
  radar. Baud is the real wire rate on that transport and the factory default of
  19,200 would stretch a 40.6KB dump to 21 seconds, so the driver probes for the
  rate the board is actually using and raises it to 230,400 (`I5`), bringing a
  dump down to ~1.8 seconds. Every dump timeout now scales with the negotiated
  rate, so a link that settles low runs slowly instead of truncating captures.
  Pass `--radar-port /dev/ttyAMA0` (and optionally `--ops-baud`); USB behaviour
  is unchanged. `diagnose.py --ops-port` adds a preflight for the three
  UART-only failures that all look like an unresponsive radar — missing device
  node, a login console holding the port, and the OPS USB cable still plugged in
  (which silences the UART). See
  [Moving the OPS243 from USB to the Pi GPIO UART](ops243-uart-migration.md).
- **Flash IWR6843 firmware directly from a Raspberry Pi.** Contributors no
  longer need an Intel Mac, UniFlash, or TI Cloud Agent for routine firmware
  updates. The guided terminal workflow verifies the image hash, offers a
  non-destructive bootloader probe, erases the existing image, transfers the
  replacement in acknowledged chunks, and requires the radar's ROM bootloader
  to verify the completed image. The current IWR6843LEVM still requires its
  physical flash-mode switch and reset button.
- **Experimental three-transmitter capture for horizontal launch direction.**
  The TX2 firmware variant captures all three transmitters while retaining the
  TX1/TX3 vertical array, giving the offline and live pipelines the antenna
  diversity needed to begin measuring left/right start direction.
- **On-chip range snapshots for smaller IWR6843 shot captures.** The radar uses
  its hardware accelerator and EDMA to retain 53 selected complex range-FFT
  bins in moving early, middle, and late windows instead of every raw ADC
  sample. The production ring keeps 18 frames at 4 ms spacing in a 549,542-byte
  dump while preserving vertical and horizontal processing inputs.
- **`--kld7` now delivers the full launch-angle pipeline by default.** Enabling
  the K-LD7 radars turns on the **two-ray multipath vertical launch-angle
  estimator** (per-frame demodulation that separates the ball from its floor
  reflection to recover true elevation instead of averaging across the
  multipath) plus the **ball-speed cosine correction** (OPS radial → true
  speed). Each shot is graded into a tour-derived Tier-1/Tier-2 confidence with
  a tour-average boost for suppressed reads; measurements that clear the
  physics guard but trip a soft consistency guard are shown as **marginal
  (one-dot) confidence** rather than silently replaced by the club estimate.
  Far-net flights are de-aliased past the FSK range wrap (`--net-distance`).
- `--kld7-mount-tilt` is **required** with `--kld7` (measure with a phone
  inclinometer — no safe default). `--kld7-angle-offset` defaults to the
  calibrated `1.5`.
- `--calculated-spin` (opt-in, off by default): replaces radar spin with the
  kinematic estimate `170·v·sin(LA)^1.2`; the measured value is retained in
  `spin_rpm_measured` for scoring.
- `--kld7-vertical-raw` test mode surfaces the raw radar angle for every shot
  (all display guards bypassed).
- Offline `scripts/analysis/session_shot_report.py` per-shot HTML report, a
  visual explainer (`docs/kld7-launch-angle-explained.html`), and a
  setup/usage guide (`docs/kld7.md`).
- **Club path from the IWR6843's pre-impact frames.** `Shot.club_path_deg` has
  been wired end to end since the K-LD7 era but unpopulated since that radar
  was deprecated. It now comes from the six pre-impact frames the L3-dump
  firmware already retains. The estimator fits `x(t)` and `y(t)` in Cartesian
  coordinates and reports `path = atan2(v_y, v_x)`; absolute azimuth enters
  additively rather than cancelling out, so a constant per-element phase error
  from the shipped array calibration (measured on a different board) shifts
  the reported path by a constant rather than the estimator itself — which is
  what `--iwr6843-azimuth-offset-deg` is for. Measured on a first-principles
  fixture across ±12°, absolute error grows with angle (0.034° at 4° to
  0.303° at −12°, roughly symmetric), so it separates deliberate in-to-out
  from out-to-in swings but does not support degree-level claims. Ships
  experimental; validate with `scripts/iwr6843/club_path_report.py` before
  trusting it.

### Changed
- **`server.py` architectural refactoring and AppState**: Extracted `_process_kld7_orientation()` to deduplicate vertical/horizontal K-LD7 shot buffer processing, defined `AppState` dataclass to encapsulate server runtime state, and published upstream design proposal for staged shot pipeline and dead camera retirement ([#20](https://github.com/D-sorganization/openflight_development/issues/20)).
- The vertical estimator is now a fixed cascade (two_ray → geometry →
  single-frame geometry → naive); it is no longer user-selectable. Launch-angle
  source and confidence semantics changed accordingly.
- `--experimental-kld7-raw-radc-logging` promoted to `--kld7-raw-logging` (it
  is the standard replay/review path, not an experiment).

### Removed
- `--kld7-vertical-estimator` (estimator is a fixed cascade), `--kld7-geometry`
  (kiosk preset), and `--ball-speed-cosine-correction` (folded into `--kld7`).
  `--kld7-bypass-vertical-gate` renamed to `--kld7-vertical-raw`.

### Fixed
- **Graceful IWR6843 shutdown.** Kiosk shutdown now asks the server to finish
  hardware cleanup before escalating to process signals. An active TI dump is
  allowed to complete, capture firmware is stopped and verified inactive, and
  the serial port is then closed. This prevents an interrupted L3 transfer or
  failed GPIO setup from leaving the radar unresponsive on the next startup.
- **Raspberry Pi 5 & OS Compatibility:** Updated UART configuration documentation to support Debian Bookworm and Raspberry Pi 5 hardware using `dtparam=uart0=on` alongside legacy `enable_uart=1`.
- **UART Diagnostic Commands:** Simplified UART verification instructions in `docs/iwr6843/README.md` and `docs/ops243-uart-migration.md` using `grep -E` to check for both legacy and modern device-tree parameters simultaneously across config paths.
- Session logging: serialize all access to the session JSONL file with a
  lock. The `log_*` methods are called concurrently from the OPS243
  capture thread, the K-LD7 stream thread, and Flask-SocketIO handlers;
  without synchronization, large entries (e.g. `rolling_buffer_capture`
  with 2×4096 samples) could interleave and corrupt JSONL lines, and a
  write could race `end_session()` closing the file (`AttributeError` /
  `ValueError: I/O operation on closed file`). Corrupt lines break the
  offline replay tooling that depends on these logs.
- IWR6843 runtime: the ball-estimate call passed a hardcoded
  `tdm_sign_policy="positive"` instead of the runtime's configurable field
  (the club-path fallback already honored the field, and offline replay
  plumbs a caller-supplied policy end to end). Any non-default policy
  silently produced different live-vs-replay answers for the same capture.
  Live behavior with the default is unchanged.
- **GPIO startup on a Raspberry Pi 5.** Anything using the sound-trigger GPIO —
  the IWR6843 capture monitor and the GPIO sound trigger — died with
  `BadPinFactory: Unable to load any default pin factory!`. The cause is
  upstream: gpiozero 2.0.1.post2 (the latest release) calls `os.path.exists`
  in its lgpio chip auto-detection without importing `os`, and that code path
  only runs on a Pi 5, so gpiozero swallows the `NameError` and every remaining
  backend then fails for its own reason. OpenFlight now selects the lgpio
  factory itself with an explicit gpiochip, which skips the broken branch.
  `OPENFLIGHT_GPIO_CHIP` overrides the chip if a kernel update renumbers the
  header. Note that `GPIOZERO_PIN_FACTORY=lgpio` was never a workaround — it
  forces the same failing call.
- IWR6843 range-snapshot capture now freezes only at a completed ring boundary
  and correctly rearms the HWA/EDMA chain, preventing partial or one-shot-only
  captures during repeated shots.
- K-LD7 tracker: shots could silently lose their launch angle when the
  stream thread appended a frame while the shot path iterated the ring
  buffer (`snapshot_buffer` / `_radc_frames_for_extraction`). CPython
  raises `RuntimeError: deque mutated during iteration` for this, and
  the server's broad K-LD7 exception handler swallowed it, so the shot
  was reported without an angle and no error was visible. Buffer reads
  now copy under a lock; appends and resets take the same lock.
- **One collapsed channel no longer drags the launch angle down.** The vertical
  estimator averaged its two channel estimates unweighted. On a 0.229 m, 5.5°
  mount the `two8` channel collapsed to about 0° on five of six shots while
  `four4_path_tdm` read 15.3–22.0°, so five 7-irons that actually launched near
  17° were reported at 7–9°, each stamped with 0.95 confidence while
  `component_std_deg` sat at 8–10° in the log. Across a seven-shot session the
  plain mean read 10.9° with one channel collapsed; channel selection recovers
  18.3°. Channels that disagree beyond 8° now resolve to the better-supported
  one with reduced confidence; channels that agree are still averaged.
- **Launch-angle confidence is derived instead of hardcoded.** Both the vertical
  and horizontal angles reported a constant 0.95. The horizontal case computed
  HLCMF-v0 coherence, logged it, and then discarded it in favour of the
  constant, so five estimates whose own channels disagreed by 8–10° were
  presented as high confidence. Vertical confidence now follows channel
  agreement and corroboration, horizontal follows coherence, and `spin_axis_deg`
  gates on the horizontal leg rather than appearing the moment club path exists.
- **Track-span floor relaxed from 18 ms to 15 ms, and the span is now logged.**
  Recovers usable captures — one range session went from 6/7 accepted at a
  10.9° mean to 7/7 at 18.3°, and the 18 ms → 15 ms change is what recovered
  the seventh shot. The span is now recorded, since it was the gate rejecting
  most shots and was invisible without an offline replay.
- **A channel that measured nothing can no longer win the channel selection.**
  Objective curvature scored 0 both when a channel's minimum was genuinely
  flat and when its minimum sat on the edge of the −5° to 45° search grid —
  two different things, since an edge minimum means the true angle lies
  outside the searched range and a real launch above 45° pins a perfectly
  healthy channel there. Curvature now returns "no measurement" for an edge
  minimum, and such a channel takes no part in selection, in the spread
  comparison, or in the reported `component_std_deg`. When the channels
  disagree and none has positive curvature — all flat, all off-grid, or
  unscored — the shot is rejected as `rejected_no_conditioned_channel`
  instead of returning whichever channel came first in the dictionary, which
  was `two8`, the one that collapses.
- **The `fast_*` estimates no longer veto corroboration they cannot win.** All
  five components fed the agreement comparison while only the two channel
  models could be selected, so one `fast_*` outlier pushed the spread past
  the 8° gate and cut two channels agreeing to 0.4° down to a single channel
  flagged as uncorroborated and derated. They are diagnostic-only: still
  logged in `components_deg`, now excluded from the selection decision and
  from `component_std_deg`. Affects raw-ADC captures only — range-snapshot
  captures never computed the fast-time models.

### Known Limitations

Deferred pending a session paired with a reference instrument. See
[the IWR6843 operator guide](iwr6843/README.md#launch-angle-estimator-limitations).

- **The calibration tilt sweep cannot recommend a tilt.** It minimises
  `component_std_deg`, which is monotonic in tilt across the swept window, so
  its minimum lands on a window edge instead of the mount angle: on the
  2026-07-25 session, with the mount measured at 5.5°, a ±3° sweep returned
  2.5° on two shots and 8.5° on two others. Set tilt by physical measurement.
- **The curvature criterion is not scale-normalised.** `four4_path_tdm`'s
  objective range is 2–4× larger than `two8`'s, so most of the "3.7–10.7×
  sharper" margin is model scale — on one shot the true margin is 1.14×. It is
  validated as a degeneracy detector, not an accuracy ranker, and it is
  one-sided: a collapsed `four4_path_tdm` would likely still win.
- **Selecting is worse than averaging when both channels are healthy but
  disagree.** Monte Carlo at 6° of noise: 4.26° RMS averaging against 5.79°
  selecting, 7.93° on the disagreeing subset. The 8° gate's justification is a
  gap between one shot at 4.59° and six at 15.9–20.2°, from a single session,
  club, geometry and tilt.

### Changed
- Spin detection: drop the autocorrelation override branch. The autocorr
  peak inside the envelope search region often lands at minimum lag
  (~12000 RPM / upper rail) by spectral coincidence, which previously
  flipped legitimate mid-range FFT seam picks to the upper rail and got
  them rejected as bandpass-shoulder noise. The autocorr fallback still
  *confirms* the FFT pick when the two agree within 10%; disagreements
  are now logged for diagnostics but never replace the FFT result.
- Spin detection: lower `SPIN_SNR_MIN` from 3.0 → 2.5 so marginal but
  real seam tones are reported at low confidence instead of dropped.

### Added
- `scripts/analysis/replay_club_speed.py`: offline replay of a proposed
  MEDIAN club-speed picker against any session log. Builds the same
  candidate set the production picker uses, applies a 30 % magnitude
  floor, and reports the median speed for each `rolling_buffer_capture`
  alongside the originally logged (magnitude-pick) value, with smash
  factors as a physical sanity check. The script is exploratory and
  does not change production behaviour — it lets us inspect what a
  median-based picker would have produced before committing to a code
  change.
- `scripts/analysis/plot_spin_debug.py`: 4-panel diagnostic for a single
  `rolling_buffer_capture` (speed timeline, raw I/Q, bandpass envelope,
  envelope FFT spectrum) to inspect what the spin algorithm saw and why
  it accepted or rejected a shot.
- K-LD7 shot-correlation analysis workflow and theory writeup
  - `scripts/analyze_kld7.py --pair-shots` for offline club-to-ball pairing on `.pkl` captures
  - `docs/kld7-ball-detection-theory.md` with capture findings and detection rationale
- K-LD7 session-review workflow for full JSONL logs
  - `scripts/review_kld7_session.py` for per-shot profile review on `session_logs/session_*.jsonl`
  - `docs/kld7-session-review.md` documenting the empirical review method and outputs
- Persistent rolling buffer mode workaround for OPS243-A HOST_INT pin bug (per OmniPreSense)
  - `persist_rolling_buffer_mode()` method saves settings to flash memory
  - `test_rolling_buffer_persist.py` script for one-time radar setup and verification
  - Rolling buffer + sound trigger is now the default operating mode
- Grafana Alloy integration for shipping session logs to Grafana Cloud Loki
  - Setup script (`scripts/setup_alloy.sh`) and config (`config/alloy.alloy`)
  - Auto-starts with `start-kiosk.sh` when credentials are configured
  - Observability documentation with LogQL query examples
- Launch angle estimation from club type and ball speed (fallback when camera unavailable)
- Tunable Hough circle detection with all 5 parameters as CLI args (`--hough-param1`, `--hough-param2`, `--hough-min-radius`, `--hough-max-radius`, `--hough-min-dist`)
- Interactive `--tune` mode in `test_launch_angle.py` with live OpenCV trackbar sliders
- Mock mode now simulates realistic spin and launch angle data (TrackMan-based per-club averages)
- Sound trigger wiring guide with MOSFET circuit design (`docs/sound-trigger-wiring.md`)
- Camera integration with real-time ball detection in UI
- Ball detection indicator in header (shows detection status)
- Camera tab with live MJPEG stream and detection overlay
- Hough circle transform as default ball detector (replaces YOLO dependency)
- ByteTrack object tracking for persistent ball identification
- Club speed detection and smash factor calculation
- Rolling buffer mode for experimental spin rate detection
- Session logging to JSONL files (`~/openflight_sessions/`)
- I/Q streaming mode with FFT and 2D CFAR noise rejection
- `--mode rolling-buffer` flag for spin detection
- `--session-location` and `--log-dir` flags for session logging
- Roboflow API integration as optional detection backend
- YOLO performance tuning documentation for Raspberry Pi
- ONNX model export support for faster inference
- Threaded camera capture for improved FPS
- Rolling buffer spin detection documentation

### Changed
- K-LD7 launch-angle processing now uses OPS243 impact timestamps for live correlation
- K-LD7 ball-burst selection now prefers coherent far-target paths instead of averaging all far PDAT detections
- Live K-LD7 vertical launch angles now fall back to the existing club-and-speed estimate when the radar result is an obvious false positive
- Spin detection improved: Hann windowing, zero-padding to 256 points, band-limited search
- All shot metrics (spin, launch angle, club speed, carry) always shown in UI
- Shot logging unified — all metrics in single `shot_detected` entry
- Shot `mode` and `readings_data` are now proper dataclass fields (no more monkey-patching)
- Session logging enabled in mock mode for testing Alloy integration
- Default ball detection uses Hough circles instead of YOLO (no ML model required)
- Camera enabled by default in kiosk mode (use `--no-camera` to disable)
- Dropped Python 3.9 support (requires >=3.10)
- Updated Raspberry Pi setup guide with camera UI and observability instructions

## [0.2.0] - 2024-12-01

### Added
- Web UI with React frontend and Flask-SocketIO backend
- Real-time shot display with ball speed, carry distance, smash factor
- Session statistics view with per-club filtering
- Shot history with pagination
- Debug panel for radar tuning and raw readings
- Mock mode for development without hardware
- Kiosk mode script for Raspberry Pi deployment
- Systemd service for auto-start on boot
- Camera module for launch angle detection (experimental)
- Camera-based ball tracking for launch angle
- Club type selection (Driver through PW)

### Changed
- Migrated from CDM324/HB100 radar to OPS243-A
- Improved carry distance estimation model

## [0.1.0] - 2024-10-01

### Added
- Initial OPS243-A radar driver
- Basic launch monitor with shot detection
- CLI interface for monitoring shots
- Python API for integration
- Carry distance estimation based on ball speed

[Unreleased]: https://github.com/jewbetcha/openflight/compare/v0.2.0...HEAD
[0.2.0]: https://github.com/jewbetcha/openflight/compare/v0.1.0...v0.2.0
[0.1.0]: https://github.com/jewbetcha/openflight/releases/tag/v0.1.0

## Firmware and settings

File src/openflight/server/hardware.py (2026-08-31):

"""Hardware controllers, lifecycle adapters, and mock monitors for OpenFlight server."""

import logging
import math
import os
import random
import statistics
import threading
import time
from datetime import datetime
from pathlib import Path
from typing import Any, List, Optional

from openflight import server
from openflight.club_data import CLUB_BALL_SPEEDS, CLUB_LAUNCH, CLUB_SPIN, ClubType
from openflight.launch_monitor import Shot
from openflight.server.state import (
    _DEFAULT_KLD7_RADC_TUNING,
    CV2_AVAILABLE,
    PICAMERA_AVAILABLE,
)
from openflight.swing_speed import SwingSpeedEvent

logger = logging.getLogger(__name__)


def _run_shutdown_step(name: str, callback: Any) -> None:
    """Run one shutdown step without preventing later hardware cleanup."""
    started = time.monotonic()
    try:
        callback()
    except Exception:
        logger.warning("[SERVER] Shutdown cleanup failed during %s", name, exc_info=True)
    finally:
        elapsed_ms = (time.monotonic() - started) * 1000
        logger.info("[SERVER] Shutdown step %s completed in %.1fms", name, elapsed_ms)


def _cleanup_hardware_for_shutdown() -> bool:
    """Stop hardware resources and report whether this caller owned cleanup."""
    with server.shutdown_lock:
        if getattr(server, "shutdown_cleanup_started", False):
            logger.info("[SERVER] Shutdown cleanup already started")
            return False
        server.shutdown_cleanup_started = True

    kld7_vertical = getattr(server, "kld7_vertical", None)
    if kld7_vertical:
        server._run_shutdown_step("K-LD7 vertical stop", kld7_vertical.stop)

    kld7_horizontal = getattr(server, "kld7_horizontal", None)
    if kld7_horizontal:
        server._run_shutdown_step("K-LD7 horizontal stop", kld7_horizontal.stop)

    inclinometer_service = getattr(server, "inclinometer_service", None)
    if inclinometer_service:
        server._run_shutdown_step("inclinometer stop", inclinometer_service.stop)

    iwr6843_runtime = getattr(server, "iwr6843_runtime", None)
    if iwr6843_runtime:
        server._run_shutdown_step("IWR6843 stop", iwr6843_runtime.stop)

    power_monitor = getattr(server, "power_monitor", None)
    if power_monitor:
        server._run_shutdown_step("battery monitor stop", power_monitor.stop)

    server._run_shutdown_step(
        "camera thread stop", getattr(server, "stop_camera_thread", stop_camera_thread)
    )

    camera = getattr(server, "camera", None)
    if camera:
        server._run_shutdown_step("camera stop", camera.stop)
        server._run_shutdown_step("camera close", camera.close)

    server._run_shutdown_step("launch monitor stop", getattr(server, "stop_monitor", stop_monitor))

    sim_connectors = getattr(server, "sim_connectors", [])
    for connector in sim_connectors:
        server._run_shutdown_step(f"simulator connector stop ({connector.name})", connector.stop)

    return True


def _shutdown_process_after_delay(delay_s: float = 0.5) -> None:
    """Give the HTTP/WebSocket response time to flush, then clean up and exit."""
    time.sleep(delay_s)
    cleanup_func = getattr(server, "_cleanup_hardware_for_shutdown", _cleanup_hardware_for_shutdown)
    if not cleanup_func():
        return
    logger.info("[SERVER] Goodbye")
    server.os._exit(0)


def init_camera(
    model_path: Optional[str] = None,
    roboflow_model_id: Optional[str] = None,
    roboflow_api_key: Optional[str] = None,
    imgsz: int = 256,
    use_hough: bool = True,
    hough_param2: int = 33,
    hough_param1: int = 48,
    hough_min_radius: int = 4,
    hough_max_radius: int = 43,
    hough_min_dist: int = 266,
) -> bool:
    """Initialize camera and ball tracker (Hough, YOLO, or Roboflow)."""
    if not CV2_AVAILABLE:
        logger.info("OpenCV not available - camera disabled")
        return False

    if not PICAMERA_AVAILABLE:
        logger.info("picamera2 not available - camera disabled")
        return False

    try:
        from picamera2 import Picamera2

        from openflight.camera_tracker import CameraTracker

        cam = Picamera2()
        config = cam.create_video_configuration(
            main={"size": (640, 480), "format": "RGB888"},
            buffer_count=2,
            controls={"FrameRate": 60},
        )
        cam.configure(config)
        cam.start()
        time.sleep(0.5)
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

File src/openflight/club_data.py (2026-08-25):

"""Canonical golf club physics data, profiles, and baseline statistics.

Consolidates all club-physics tables (optimal smash factor, launch angles,
typical spin rates, ball speeds, spin multipliers, and mock simulation
distributions) into a single canonical source of truth, preventing numeric
drift across subsystems.
"""

from __future__ import annotations

from dataclasses import dataclass
from enum import Enum
from typing import Dict, Optional, Tuple


class ClubType(Enum):
    """Golf club types for distance estimation, ballistics, and telemetry."""

    DRIVER = "driver"
    WOOD_3 = "3-wood"
    WOOD_5 = "5-wood"
    WOOD_7 = "7-wood"
    HYBRID_3 = "3-hybrid"
    HYBRID_5 = "5-hybrid"
    HYBRID_7 = "7-hybrid"
    HYBRID_9 = "9-hybrid"
    IRON_2 = "2-iron"
    IRON_3 = "3-iron"
    IRON_4 = "4-iron"
    IRON_5 = "5-iron"
    IRON_6 = "6-iron"
    IRON_7 = "7-iron"
    IRON_8 = "8-iron"
    IRON_9 = "9-iron"
    PW = "pw"
    GW = "gw"
    SW = "sw"
    LW = "lw"
    UNKNOWN = "unknown"


@dataclass(frozen=True)
class ClubProfile:
    """Unified physical and statistical baseline profile for a club type.

    Attributes:
        club_type: ClubType enumeration value.
        name: Human-readable club name.
        optimal_smash: Canonical optimal smash factor (ball_speed / club_speed).
        optimal_launch_deg: Optimal / average vertical launch angle in degrees.
        typical_spin_rpm: TrackMan PGA Tour average spin rate in RPM.
        avg_ball_speed_mph: Baseline ball speed for amateur / typical golfer in mph.
        deg_per_mph_deviation: Degrees of launch angle shift per mph ball-speed deviation.
        spin_multiplier: Club-specific spin scaling multiplier relative to driver.
        speed_std_dev_mph: Standard deviation of ball speed for mock shot generation.
        spin_std_dev_rpm: Standard deviation of spin rate for mock shot generation.
        launch_std_dev_deg: Standard deviation of launch angle for mock shot generation.
    """

    club_type: ClubType
    name: str
    optimal_smash: float
    optimal_launch_deg: float
    typical_spin_rpm: float
    avg_ball_speed_mph: float
    deg_per_mph_deviation: float
    spin_multiplier: float
    speed_std_dev_mph: float = 10.0
    spin_std_dev_rpm: float = 500.0
    launch_std_dev_deg: float = 2.0


CLUB_PROFILES: Dict[ClubType, ClubProfile] = {
    ClubType.DRIVER: ClubProfile(
        club_type=ClubType.DRIVER,
        name="Driver",
        optimal_smash=1.48,
        optimal_launch_deg=11.0,
        typical_spin_rpm=2700.0,
        avg_ball_speed_mph=143.0,
        deg_per_mph_deviation=0.15,
        spin_multiplier=1.0,
        speed_std_dev_mph=12.0,
        spin_std_dev_rpm=400.0,
        launch_std_dev_deg=2.0,
    ),
    ClubType.WOOD_3: ClubProfile(
        club_type=ClubType.WOOD_3,
        name="3-Wood",
        optimal_smash=1.44,
        optimal_launch_deg=12.5,
        typical_spin_rpm=3500.0,
        avg_ball_speed_mph=135.0,
        deg_per_mph_deviation=0.18,
        spin_multiplier=1.15,
        speed_std_dev_mph=10.0,
        spin_std_dev_rpm=400.0,
        launch_std_dev_deg=2.0,
    ),
    ClubType.WOOD_5: ClubProfile(
        club_type=ClubType.WOOD_5,
        name="5-Wood",
        optimal_smash=1.42,
        optimal_launch_deg=14.0,
        typical_spin_rpm=4200.0,
        avg_ball_speed_mph=128.0,
        deg_per_mph_deviation=0.20,
        spin_multiplier=1.25,
        speed_std_dev_mph=10.0,
        spin_std_dev_rpm=400.0,
        launch_std_dev_deg=2.0,
    ),
    ClubType.WOOD_7: ClubProfile(
        club_type=ClubType.WOOD_7,
        name="7-Wood",
        optimal_smash=1.42,
        optimal_launch_deg=15.5,
        typical_spin_rpm=4800.0,
        avg_ball_speed_mph=122.0,
        deg_per_mph_deviation=0.20,
        spin_multiplier=1.32,
        speed_std_dev_mph=9.0,
        spin_std_dev_rpm=500.0,
        launch_std_dev_deg=2.0,
    ),
    ClubType.HYBRID_3: ClubProfile(
        club_type=ClubType.HYBRID_3,
        name="3-Hybrid",
        optimal_smash=1.39,
        optimal_launch_deg=13.5,
        typical_spin_rpm=4400.0,
        avg_ball_speed_mph=123.0,
        deg_per_mph_deviation=0.22,
        spin_multiplier=1.45,
        speed_std_dev_mph=9.0,
        spin_std_dev_rpm=400.0,
        launch_std_dev_deg=2.0,
    ),
    ClubType.HYBRID_5: ClubProfile(
        club_type=ClubType.HYBRID_5,
        name="5-Hybrid",
        optimal_smash=1.38,
        optimal_launch_deg=15.0,
        typical_spin_rpm=4900.0,
        avg_ball_speed_mph=118.0,
        deg_per_mph_deviation=0.22,
        spin_multiplier=1.55,
        speed_std_dev_mph=9.0,
        spin_std_dev_rpm=500.0,
        launch_std_dev_deg=2.0,
    ),
    ClubType.HYBRID_7: ClubProfile(
        club_type=ClubType.HYBRID_7,
        name="7-Hybrid",
        optimal_smash=1.37,
        optimal_launch_deg=16.5,
        typical_spin_rpm=5300.0,
        avg_ball_speed_mph=112.0,
        deg_per_mph_deviation=0.25,
        spin_multiplier=1.65,
        speed_std_dev_mph=8.0,
        spin_std_dev_rpm=500.0,
        launch_std_dev_deg=2.0,
    ),
    ClubType.HYBRID_9: ClubProfile(
        club_type=ClubType.HYBRID_9,
        name="9-Hybrid",
        optimal_smash=1.36,
        optimal_launch_deg=18.0,
        typical_spin_rpm=5800.0,
        avg_ball_speed_mph=106.0,
        deg_per_mph_deviation=0.25,
        spin_multiplier=1.75,
        speed_std_dev_mph=8.0,
        spin_std_dev_rpm=500.0,
        launch_std_dev_deg=2.5,
    ),
    ClubType.IRON_2: ClubProfile(
        club_type=ClubType.IRON_2,
        name="2-Iron",
        optimal_smash=1.37,
        optimal_launch_deg=13.0,
        typical_spin_rpm=4000.0,
        avg_ball_speed_mph=120.0,
        deg_per_mph_deviation=0.25,
        spin_multiplier=1.50,
        speed_std_dev_mph=9.0,
        spin_std_dev_rpm=400.0,
        launch_std_dev_deg=2.0,
    ),
    ClubType.IRON_3: ClubProfile(
        club_type=ClubType.IRON_3,
        name="3-Iron",
        optimal_smash=1.36,
        optimal_launch_deg=14.5,
        typical_spin_rpm=4500.0,
        avg_ball_speed_mph=118.0,
        deg_per_mph_deviation=0.25,
        spin_multiplier=1.60,
        speed_std_dev_mph=9.0,
        spin_std_dev_rpm=400.0,
        launch_std_dev_deg=2.0,
    ),
    ClubType.IRON_4: ClubProfile(
        club_type=ClubType.IRON_4,
        name="4-Iron",
        optimal_smash=1.35,
        optimal_launch_deg=16.0,
        typical_spin_rpm=5000.0,
        avg_ball_speed_mph=114.0,
        deg_per_mph_deviation=0.28,
        spin_multiplier=1.80,
        speed_std_dev_mph=8.0,
        spin_std_dev_rpm=500.0,
        launch_std_dev_deg=2.0,
    ),
    ClubType.IRON_5: ClubProfile(
        club_type=ClubType.IRON_5,
        name="5-Iron",
        optimal_smash=1.35,
        optimal_launch_deg=17.5,
        typical_spin_rpm=5400.0,
        avg_ball_speed_mph=110.0,
        deg_per_mph_deviation=0.28,
        spin_multiplier=2.00,
        speed_std_dev_mph=8.0,
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

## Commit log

2026-07-31 Mark IWR6843LEVM variant as confirmed (Digi-Key 296-IWR6843LEVM-ND) (#24)
    Order line item verified 2026-07-31: TI IWR6843LEVM, the exact board
    upstream targets. Wrong-variant risk retired; remaining on-arrival
    checks tracked in issue #8.
2026-07-31 Add live-link reference library and implementation-guidance appendices (#25)
    Appendix A: every source consulted as a clickable link, organized by
    category (patents by assignee, FCC filings, manufacturer technical docs,
    peer-reviewed literature, engineering references, DIY projects,
    comparative testing).
    Appendix B: concrete engineering guidance for OpenFlight with citations
    throughout - OPS243-A Doppler scaling/resolution budget and de-chirped
    comb spin estimation, K-LD7 interferometric angles with EKF/RTS smoother
    and alignment calibration, D-plane inversion with club priors and
    gear-effect uncertainty bounds, Phase-2 optical module parameters
    (global-shutter + IR strobe timing, dimple reg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
2026-07-31 Add patent portfolio compendium, hardware reference appendix, and expanded live links (#26)
    Appendix C: sensor hardware and integration reference - OPS243-A specs,
    API, rolling buffer and the AN-029 vendor golf recipe (which cites
    OpenFlight by name); K-LD7 datasheet and UART protocol; IWR6843 FMCW
    specifics; Pi Global Shutter XTR triggering; full GSPro Open Connect
    schema; USGA equipment constants; CFAR selection guidance.
    Appendix D: patent portfolio compendium - every identified US patent for
    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
2026-07-31 Migrate bibliography to BibTeX, add contributor conventions and CI build (#27)
    Prepares the technology review to grow into a long-lived, multi-contributor
    document.
    Bibliography: replaces the hand-maintained thebibliography list with a
    structured references.bib (76 entries) resolved by biblatex/biber. Entries
    carry a keywords field (literature|patent|vendor|hardware|community) and the
    printed bibliography is assembled from five keyword-filtered blocks, so
    sources are grouped by kind and new entries can be appended without
    line-level conflicts between concurrent edits. All existing citation keys
    are preserved, so no section file needed rewording.
    CONVENTIONS.md: file layout, how to add a ch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
2026-08-02 Add Appendix E: screw-theoretic clubhead kinematics from radar velocities (#29)
    New appendix developing the estimation layer that turns per-detection
    radar velocities into rigid-body clubhead motion:
    - Context: what TrackMan-class "silhouette" tracking actually recovers,
    and the finding that ISA theory is established in golf biomechanics
    (Vena et al., Sports Engineering 2010/2011) but no launch-monitor
    vendor publicly formulates its pipeline in screw coordinates.
    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
2026-08-02 Add research outline: screw theory applied to launch monitor measurement (#30)
    Comprehensive research-grade outline covering: the continuous-time SE(3)
    twist trajectory as the unifying estimation ledger; the anchor-and-
    propagate principle for clubface orientation (fix face pose once,
    integrate measured angular velocity to impact); radar program (twist-
    native estimation, rotational ISAR imaging using the twist as motion
    compensation, specular-flash timing as an orientation anchor, multistatic
    observability design, polarimetry, passive RF tags); camera program
    (Plucker line tracking of shaft/topline, grooves as natural fiducials
    for direct face-plane measurement, deflectometry of the face as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
2026-08-02 Document that club path is reference-point dependent by ~3 degrees (#31)
    The reference-point problem is usually raised only for club speed, but it
    applies to direction with equal force and a larger practical consequence.
    Adds section 2.3: the velocity field across a rigid clubhead means a
    reported path is that field sampled at a chosen point. Radar reports it at
    the geometric centre (within ~6 mm of the CG, which sits 25-50 mm behind
    the face); optical systems with face fiducials report it at the face
    centre. TrackMan quantifies the gap at approximately 3 degrees for a
    driver, with the face-centre path the more out-to-in, shrinking for
    shorter clubs.
    Identifies the two contributing rotatio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
2026-08-03 Correct face/path weighting to measured 0.76; add TrackMan newsletter archive (#32)
    * Correct the face/path weighting; add the TrackMan newsletter archive
    The launch-direction weight w_f was given as 0.85-0.87 for a driver and 0.75
    for short irons. The only peer-reviewed measurement of the HORIZONTAL ratio
    (Wood et al. 2018, 157 golfers, 1,575 shots at 720 fps, filtered to centred
    strikes) gives 0.76 +/- 0.08 driver, 0.69 7-iron, 0.61 wedge, with a PING Man
    robot returning 0.63 for the 7-iron. Updated, including the TikZ figure label.
    The provenance is worth stating precisely because it bears on how much to
    trust the coefficient. TrackMan's Ten Fundamentals asserts 85% in BOTH planes
    -- dy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
2026-08-03 Vendor the launch-monitor articles from AffineDrift; remove the local copies (#34)
    Both golf articles previously maintained here -- the LaTeX technology review
    under `tech-review/` and its companion `notes/screw-theory-research-outline.md`
    -- now live in AffineDrift, so all the golf content shares one repository, one
    CI, and one release path. This repo reaches them through a submodule,
    `vendor/affinedrift`, the same way the fleet's other repositories (e.g.
    Gasification_Model, UpstreamDrift) vendor `D-sorganization/Tools` at
    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
2026-08-24 fix(tests): fix Windows test failures and harden verified code edges (#15, #17) (#35)
    [IARC_Case_v3.3mf, K-LD7-RFB.step, KLD7_h_mount_L_v2.step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]
2026-08-25 refactor(server): introduce AppState, deduplicate K-LD7 orientation processing, and document staged pipeline architecture (#20) (#40)
2026-08-31 fix(security): replace unsafe pickle serialization and convert server to logging (#45)
    [camera_tracker.py, capture_io.py, capture_iq.py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]
2026-08-31 refactor(server): extract modular server architecture and decompose main (#42) (#46)
    * refactor(server): extract modular subsystems and decompose main (#42)
    * style: apply ruff format and lint fixes to server package
    [hardware.py, test_server_angle_confidence.py, test_server_cli.py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]
2026-10-04 ci: keep push runs off merge-queue branches (Repository_Management#1900) (#70)
    The push trigger had no branch filter, so pushes to gh-readonly-queue/* started a second run of the required check alongside merge_group; with cancel-in-progress one cancels the other and the queue d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
2026-10-17 chore: vendor the fleet automerge guard (#76)
    AGENTS.md (fleet rule merge-queue, Repository_Management) says to arm PRs only
    with `python scripts/automerge_guard.py <owner>/<repo> <pr> --arm --strategy squash`,
    but this repository did not carry the script. This vendors the canonical
    scripts/automerge_guard.py and its companion scripts/requeue_stalled_merges.py
    byte-for-byte from Repository_Management main (stdlib only, no new dependencies).
2026-11-01 fix(ci): exclude RM-vendored fleet files from local ruff (#84) (#85)
    main's Ruff job has failed on every push since #76: ruff 0.16.1 (uv.lock)
    flags I001 in shared_scripts/agent_check.py and 4 unformatted files, all
    byte-identical Repository_Management canonical copies formatted under RM's
    config (line-length 88) rather than this repo's (100, combine-as-imports).
    Reformatting them here would drift from canonical until the next sync, so
    exclude the vendored paths instead. Red-first test asserts every vendored
    fleet file present is in extend-exclude.
    No material handoff change — CI config only; handoff is in the PR body.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
2026-11-01 chore(fleet): re-sync stale RM-vendored fleet scripts (#86) (#87)
    Five Repository_Management-canonical copies had drifted from RM main since
    the 10-17/10-22 syncs. Copy them byte-for-byte from RM main, together with
    shared_scripts/agent_check_regen_trust.py, which the current agent_check
    imports. The stale agent_check failed to import here because it needed
    shared_scripts.run_mypy_diff and src.contracts; the canonical copy falls back
    for both. A red-first test imports each vendored entry point from the repo
    root, and the new file joins the ruff extend-exclude list.
    Closes #86
    No material handoff change.
    Co-au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
